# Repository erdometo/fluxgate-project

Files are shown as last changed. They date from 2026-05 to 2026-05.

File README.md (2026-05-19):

# 🧲 High-Precision Fluxgate Magnetic Field Sensor Design

An open-source, high-sensitivity, single-axis Fluxgate magnetometer and development platform designed for aerospace, geophysics, and navigation applications. This project implements a fully integrated system containing hardware (KiCad PCBs), firmware (MSP430 24-bit SD-ADC & RP2040 Controller), simulations (LTSpice), and software (Python PyQt real-time GUI).

Developed as a senior capstone engineering project at **Karadeniz Technical University (KTU)** by **Erdem Metin** and **Mücahit Ata**, under the supervision of **Prof. Dr. İsmail Kaya**.

---

## 📸 System Overview

The Fluxgate sensor system is designed around a dual-MCU architecture consisting of an **RP2040** (master controller and driver) and an **MSP430AFE253** (24-bit Sigma-Delta ADC data acquisition).

System Schematic
*Fig 1: Full system schematic diagram detailing all MCU pinouts, power distribution, and analog filters.*

<p align="center">
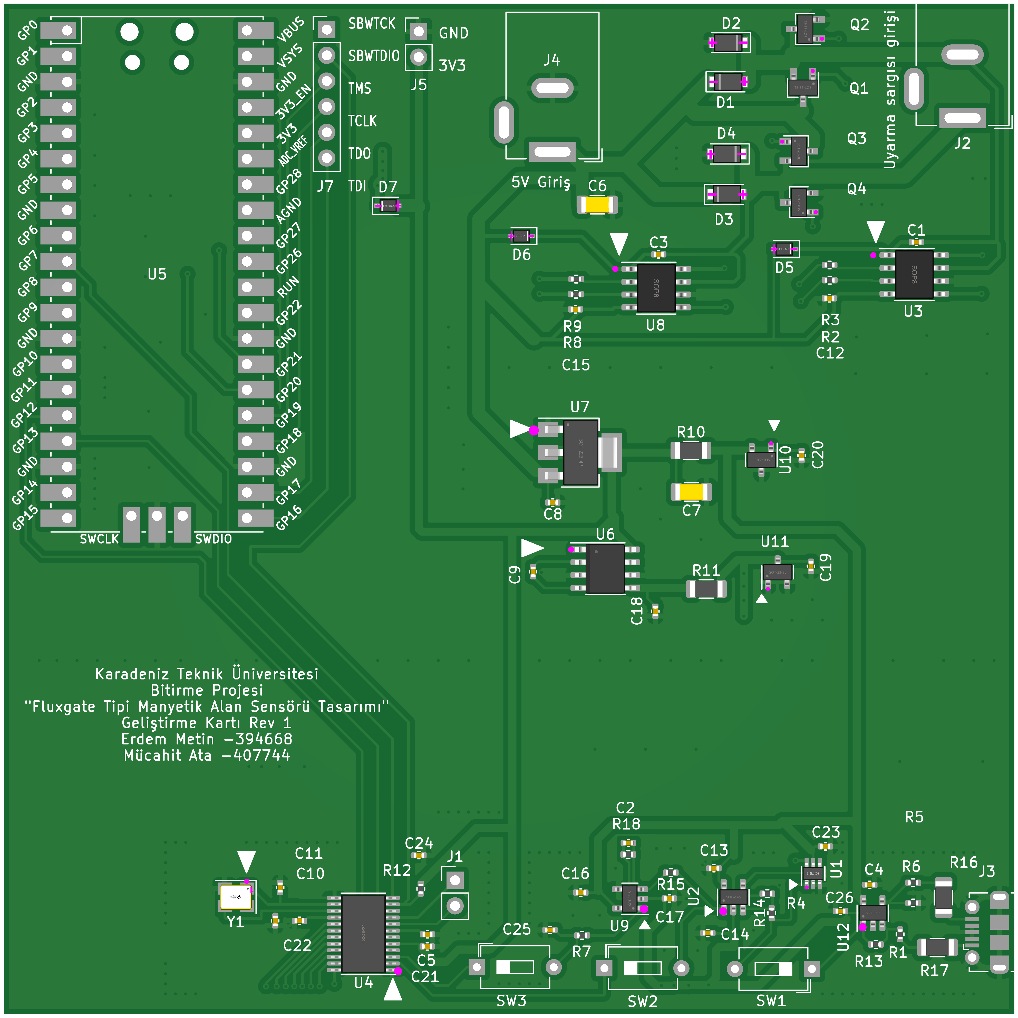
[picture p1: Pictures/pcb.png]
PCB Design Render
  
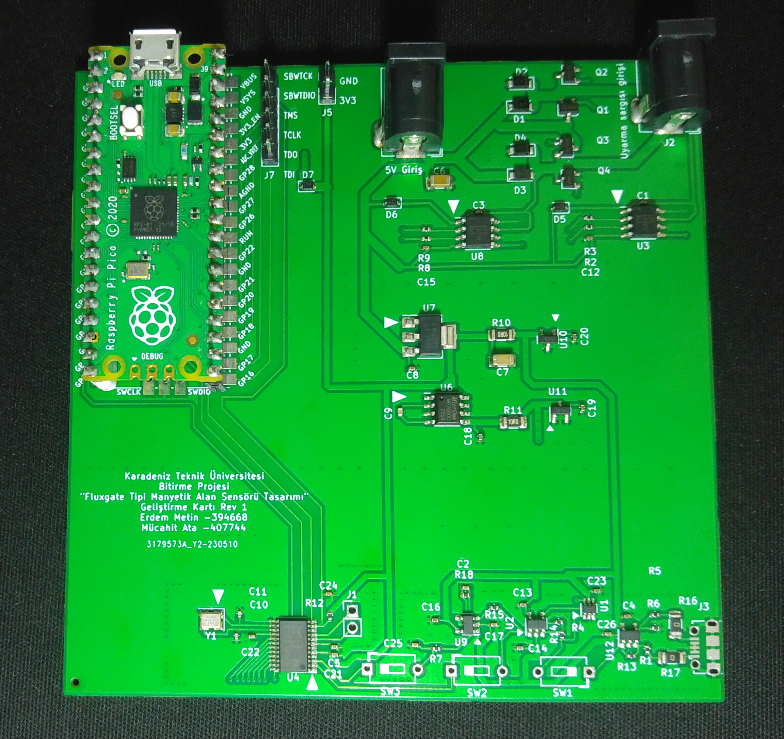
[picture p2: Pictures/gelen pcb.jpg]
Assembled Hardware Prototype
  
</p>
*Fig 2: KiCad PCB 3D layout render (left) and the fully assembled physical testing board (right).*

```mermaid
graph TD
    PC[Computer PyQt GUI / Matlab] <-->|USB virtual COM / UDP Wifi| Pico[Raspberry Pi Pico RP2040]
    Pico -->|PWM Excitation Control f| FET[H-Bridge MOSFET Driver]
    FET -->|AC Excitation staircase Wave| Core[Magnetic Core & Coils]
    Core -->|Induced Sensing Signal| Demod[Analog Processing Circuit]
    Demod -->|DC Level / AC Signal| MSP[MSP430AFE253 24-bit ADC]
    MSP -->|1.5 MBaud UART| Pico
```

---

## 📖 Theory of Operation

A **Fluxgate Magnetometer** measures weak static or low-frequency magnetic fields (in the nT to µT range) by exploiting the non-linear magnetic saturation characteristics of a ferromagnetic core.

1. **Excitation (Drive):** An AC current at frequency $f$ drives the core deep into saturation in both positive and negative directions.
2. **Symmetric Core State:** In the absence of an external magnetic field, the magnetic flux changes symmetrically. The voltage induced in the sensing (pick-up) coil contains only **odd harmonics** ($3f$, $5f$, etc.).
3. **Asymmetric Core State (External Field Present):** When an external magnetic field (like the Earth's field $H_{ext}$) is present, it biases the core, causing it to saturate earlier in one direction and later in the other.
4. **Second Harmonic (2f) Detection:** This asymmetry generates **even harmonics** (predominantly the $2f$ component) in the sensing coil. The amplitude of this second harmonic is directly proportional to the magnitude of the external magnetic field, and its phase indicates the field's direction.

---

## 🛠️ Project Structure

The repository is structured into logically separated folders to make implementation and replication straightforward:

*   📁 **[`Hardware/`](file:///c:/Users/ASUS/Desktop/Fluxgate/Fluxgate-Project-Files/Hardware)**: KiCad schematic and PCB layout designs, Gerber files, and Bill of Materials (BOM).
*   📁 **[`Firmware/`](file:///c:/Users/ASUS/Desktop/Fluxgate/Fluxgate-Project-Files/Firmware)**:
    *   **MSP430:** IAR and CCS projects for 24-bit Sigma-Delta ADC sampling at 16.5 kSps and 1.5 MBaud USART transmission.
    *   **RP2040 (Raspberry Pi Pico):** C/C++ SDK projects generating precise excitation PWM and streaming data to PC via USB Serial or UDP Wi-Fi.
*   📁 **[`Software/`](file:///c:/Users/ASUS/Desktop/Fluxgate/Fluxgate-Project-Files/Software)**: Python-based GUI utilizing `pyqtgraph` for real-time serial and UDP plotting, and Matlab analytics.
*   📁 **[`Simulations/`](file:///c:/Users/ASUS/Desktop/Fluxgate/Fluxgate-Project-Files/Simulations)**: LTSpice circuits simulating the H-Bridge excitation driver and the analog synchronous demodulation path.

---

## 🚀 Step-by-Step Build & Replication Guide

To replicate and build this high-precision Fluxgate sensor, follow these five steps:

### 1. Hardware Fabrication & Assembly
1. Go to **[`Hardware/`](file:///c:/Users/ASUS/Desktop/Fluxgate/Fluxgate-Project-Files/Hardware)** and select either the **Excitation Circuit V1**, the **Excitation Circuit Final**, or the **JLCPCB Version** which is optimized for SMT assembly.
2. Export Gerbers or use the provided `.zip` files under the directories to order PCBs from your manufacturer (e.g., JLCPCB).
3. Assemble the PCB using the BOM. Key components include:
    *   **Primary Controller:** Raspberry Pi Pico (RP2040)
    *   **Precision ADC:** MSP430AFE253IPW (24-bit Sigma-Delta ADC)
    *   **H-Bridge Driver:** HIP4082xB half-bridge gate driver
    *   **Excitation MOSFETs:** AP2300 or IRFZ44N
    *   **Ultra Low-Noise Opamps:** TP2311 or LT149x series (12nV/√Hz input noise)
    *   **Voltage References:** AN431 shunt regulators (2.5V, 20ppm/°C stability)

### 2. Fluxgate Core & Coil Preparation
1. **Core Selection:** Use a high-permeability **green iron-powder ferrite toroid core** with an **inner diameter of 7 mm, thickness of 2 mm, and height of 4.5 mm**. (While a 6-81 Permalloy racetrack core with $100\text{ µm}$ laminations provides lower noise, a toroidal ferrite core is robust and hand-windable).
2. **Drive Winding:** Wind the excitation (drive) coil uniformly around the toroid using **32 AWG** enameled copper wire. In the experimental prototype, the completed drive winding exhibited a measured **series resistance of $17.945\text{ }\Omega$** and a **series inductance of $19.686\text{ mH}$**.
3. **Sense Winding:** Wind the sensing (pick-up) coil on top of the drive winding, orienting the windings to capture the fluxgate effect while canceling direct coupling from the excitation drive.

Wound Fluxgate Core on Prototyping Board
*Fig 3: The custom hand-wound toroidal fluxgate core integrated onto the testing board.*

### 3. Simulation & Validation
1. Open **[`Simulations/LTSpice/`](file:///c:/Users/ASUS/Desktop/Fluxgate/Fluxgate-Project-Files/Simulations)**.
2. Run `fluxgate.asc` to simulate the H-Bridge excitation path. Verify the staircase voltage waveform across the drive bobbin.
3. Run `fluxgateACAnaliz.asc` or `Draft7.asc` to analyze the frequency response of the active integrator and synchronous demodulator. Ensure the integration region lies between **159 Hz and 1591 Hz** and the low-pass filter kesim frekansı is configured near **28 Hz**.

### 4. Firmware Deployment
1. **MSP430 Firmware:**
    *   Open IAR Embedded Workbench or Code Composer Studio.
    *   Load the project in **[`Firmware/MSP430_AFE_ADC/`](file:///c:/Users/ASUS/Desktop/Fluxgate/Fluxgate-Project-Files/Firmware/MSP430_AFE_ADC)** or **[`Firmware/MSP430_ADC_to_UART/`](file:///c:/Users/ASUS/Desktop/Fluxgate/Fluxgate-Project-Files/Firmware/MSP430_ADC_to_UART)**.
    *   Compile and flash the firmware using an eZ-FET debugger (or the Spy-Bi-Wire pins on an MSP430 Launchpad).
    *   *Function:* Configures the 12MHz MCLK, initializes the SD24 Module in group conversion mode, and streams 24-bit raw ADC readings via USART0 at **1.5M Baud**.
2. **RP2040 Firmware:**
    *   Navigate to **[`Firmware/Pico_Firmwares/`](file:///c:/Users/ASUS/Desktop/Fluxgate/Fluxgate-Project-Files/Firmware/Pico_Firmwares)**.
    *   Choose either `pico-custom-firmware-usb` (USB Virtual Serial) or `pico-custom-firmware-udp` (Wi-Fi streaming).
    *   Build the project using the Pico SDK (`CMake`) and flash the resulting `.uf2` file onto your Pi Pico.
    *   *Function:* Emits precise complementary PWM drive signals (80µs duty, 40µs dead-time) at frequency $f$ to drive the H-Bridge. It uses a **PIO state machine** to reliably capture the 1.5MBaud UART stream from the MSP430 and forwards it to the PC.

### 5. GUI & Visualization
1. Install Python 3 and requirements:
   ```bash
   pip install pyqtgraph PyQt5 pyserial numpy
   ```
2. Run the visualization app in **[`Software/Python_GUI_Demo/`](file:///c:/Users/ASUS/Desktop/Fluxgate/Fluxgate-Project-Files/Software/Python_GUI_Demo)**:
   ```bash
   python compass.py
   # or
   python pyqtgraph_float_v2x2_yesim.py
   ```
3. Connect your Pi Pico to the PC via USB. You will see a real-time rolling graph of the 24-bit sampled magnetic field data representing the external field.

---

## 📡 Digital Signal Processing (DSP) & Digital Lock-In Mode

During the final experimental testing phase of this project, the analog op-amps in the physical synchronous demodulation circuit were found to be defective or counterfeit, preventing analog phase detection from working out of the box. To solve this, the project utilized a highly robust **Digital Signal Processing (DSP)** pipeline to bypass the analog demodulator entirely.

### Bypassing the Analog Demodulator
1. The analog SPDT switch (SN74LVC1G3157) was disabled (tied to a static ground state via the MCU).
2. The active low-noise op-amps were configured as a simple differential preamplifier.
3. The raw, high-speed AC signal (which contains the even and odd harmonics) was fed directly into the **MSP430's 24-bit Sigma-Delta ADC**.
4. The raw, un-demodulated samples were digitized at ~16.5 kSps and streamed to the PC via the RP2040 UART/USB bridge.

### Two Host-Side Digital Processing Implementations
Your software repository implements two distinct mathematical approaches on the host PC to extract the external magnetic field from this raw stream:

1. **Frequency-Domain Demodulation (Real-Time FFT):**
   * *File:* **[`pyqtgraph_float_v2x2_yesim.py`](file:///c:/Users/ASUS/Desktop/Fluxgate/Fluxgate-Project-Files/Software/Python_GUI_Demo/pyqtgraph_float_v2x2_yesim.py)**
   * *Method:* Computes a high-performance **Fast Fourier Transform (FFT)** on blocks of 8192 raw samples using Scipy:
     ```python
     Yf0 = fft(ch0)
     ```
   * *Result:* The GUI displays the real-time frequency spectrum. By measuring the amplitude peak of the **second harmonic ($2f$ at 25 kHz)** in the frequency domain, the software calculates the precise external magnetic field intensity, completely replacing the physical analog lock-in filters!

2. **Time-Domain Smoothing (Moving Average Convolution):**
   * *Files:* **[`udp_plot_pyqt.py`](file:///c:/Users/ASUS/Desktop/Fluxgate/Fluxgate-Project-Files/Software/Python_GUI_Demo/udp_plot_pyqt.py)** and **[`udp_plot_pyqt_2.py`](file:///c:/Users/ASUS/Desktop/Fluxgate/Fluxgate-Project-Files/Software/Python_GUI_Demo/udp_plot_pyqt_2.py)**
   * *Method:* Unpacks the high-speed telemetry and applies a real-time **Moving Average Filter** using NumPy convolution across a 1000-sample window:
     ```python
     filtered_data = np.convolve(data, weights, mode='valid')
     ```
   * *Result:* Smooths out the excitation switching ripples and transient spikes, feeding a clean time-domain signal to the graphical compass needle interface to dynamically show the core's magnetic orientation.

---

## 🛠️ Hardware Debugging & Engineering Solutions

During the assembly and testing phase, two critical engineering challenges arose and were systematically resolved:

### 1. The H-Bridge Bootstrap Capacitor & Duty Cycle Adaptation
*   **The Issue:** High-side gate drivers require a bootstrap capacitor ($C_{Bst}$) to maintain the gate-to-source voltage ($V_{GS}$) when the high-side MOSFET turns on. By design guidelines, the minimum bootstrap capacitance is:
    $$C_{Bst} = \frac{Q_{gate}}{\Delta V_{Bst}}$$
    Using the AP2300 gate charge $Q_{gate} = 11\text{ nC}$ and an acceptable voltage ripple $\Delta V_{Bst} = 0.1\text{ V}$, the minimum capacitor required is $110\text{ nF}$. Due to a design oversight, a **$1\text{ nF}$** capacitor was initially populated. This capacitor discharged instantly, causing the high-side gate drivers to drop out immediately.
*   **The Fix:** Populating a **$1\text{ µF}$** capacitor resolved the gate-dropout issue. However, experimental tests under a $330\text{ }\Omega$ load revealed that the high-side gate could remain continuously open for a maximum of **$1.125\text{ ms}$** before the bootstrap charge depleted.
*   **PWM Adaptation:** To prevent the high-side gate from collapsing during lower frequencies, the RP2040 firmware was adapted to emit a highly optimized PWM excitation pattern. Instead of a basic symmetrical square wave, the drive cycle was structured as:
    *   **$0.8\text{ ms}$ Positive Drive Phase** (containing high-speed $80\text{ µs}$ pulses with $40\text{ µs}$ dead-times).
    *   **$0.4\text{ ms}$ Neutral Phase** (H-bridge disabled, allowing the bootstrap capacitors to fully recharge).
    *   **$0.8\text{ ms}$ Negative Drive Phase** (H-bridge reversed).

### 2. Defective Analog Op-Amps & DSP Bypass
*   **The Issue:** During board validation, short-circuiting the sensing coil to ground resulted in the low-noise differential preamplifier and active integrator output locks stuck at a solid **$2.5\text{ V}$** (the virtual ground analog reference voltage). The op-amps (TP2311 or LT1492) failed to respond to any AC or DC input signal changes, leading to the conclusion that the physical components received were defective or counterfeit.
*   **The Solution:** The analog synchronous SPDT demodulator switch (SN74LVC1G3157) was set to ground mode via the RP2040, transforming the first stage into a simple, highly linear $1:2$ differential preamplifier (total differential gain of 20). The raw, high-speed AC pick-up signal was routed directly into the MSP430's 24-bit Sigma-Delta ADC, and the entire lock-in and filtering cascade was bypassed in hardware and reconstructed in real-time software on the host PC.

---

## ⚡ Specifications

| Parameter | Value | Description |
| :--- | :--- | :--- |
| **Sensor Type** | Parallel Fluxgate | Single Axis Magnetometer |
| **Excitation Waveform** | AC Staircase Wave | Minimizes transient EMF spikes |
| **Excitation Frequency** | 12.5 kHz | Configurable via Pico PWM registers |
| **ADC Resolution** | 24-Bit | Sigma-Delta Converter (MSP430AFE253) |
| **Sampling Rate** | ~16,500 samples/sec | High-speed oversampled stream |
| **Baud Rate** | 1,500,000 Baud | High-speed MSP430 to RP2040 UART link |
| **Demodulator Gain** | 1:10 (or 20 Differential) | Synchronous analog SPDT demodulation |
| **Low-Pass Filter (LPF)** | $f_c = 28.42\text{ Hz}$ | Eliminates grid noise (50Hz) and ripples |
| **Integrator Bandwidth** | 159 Hz to 1591 Hz | Limits noise and captures second harmonics |

---

## ⚖️ License

This project is open-source and released under the [MIT License](file:///c:/Users/ASUS/Desktop/Fluxgate/Fluxgate-Project-Files/LICENSE). Feel free to use, modify, and distribute for personal, academic, or commercial purposes.

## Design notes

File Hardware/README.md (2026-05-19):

# 🔌 Hardware & PCB Design

This folder contains the KiCad schematics and PCB layout files for the Fluxgate Sensor Development and Testing Board. The hardware combines the master controller, excitation power electronics, high-speed 24-bit ADC, and a low-noise analog signal processing path into a single 150mm x 100mm PCB.

Full Circuit Schematic
*Fig 1: Complete circuit schematic for the Fluxgate Development Board (open-source).*

<p align="center">
  KiCad 3D Layout
  Manufactured PCB Board
</p>
*Fig 2: KiCad board layout 3D render (left) and the actual manufactured PCB received from JLCPCB (right).*

---

## 📁 Directory Directory

*   📁 **[`Excitation_Circuit_V1/`](file:///c:/Users/ASUS/Desktop/Fluxgate/Fluxgate-Project-Files/Hardware/Excitation_Circuit_V1)**: The initial KiCad prototype.
*   📁 **[`Excitation_Circuit_Final/`](file:///c:/Users/ASUS/Desktop/Fluxgate/Fluxgate-Project-Files/Hardware/Excitation_Circuit_Final)**: The revised KiCad project with improvements in the bootstrap driver and ground isolation.
*   📁 **[`KiCad_Development_Board_JLCPCB/`](file:///c:/Users/ASUS/Desktop/Fluxgate/Fluxgate-Project-Files/Hardware/KiCad_Development_Board_JLCPCB)**: Design optimized for JLCPCB's automated surface mount technology (SMT) assembly service. Contains BOM and component positioning files.

---

## ⚡ Hardware Architecture & Circuit Sub-systems

The Fluxgate Development Board contains four main hardware sub-systems:

### 1. Power Management & Low-Noise Rails
Since magnetic sensors are highly sensitive to power supply noise, a robust voltage regulation and reference system is implemented:
*   **Main Regulator:** AMS1117-3.3 produces the digital 3.3V supply.
*   **Negative Rail Generator:** ME7660C charge-pump voltage converter generates a low-noise $-3.3\text{ V}$ rail from the $3.3\text{ V}$ input.
*   **Precision Analog References:** Originally, the op-amps shared the noisy 3.3V digital rail with the microcontrollers, which coupled massive MCU switching ripples into the analog signal path. To achieve extremely low-noise operation, the board was modified to use two **AN431 precision shunt regulators** with a **20 PPM/°C temperature coefficient**. These regulators derive highly stable $+2.5\text{ V}$ and $-2.5\text{ V}$ virtual ground references from the noisy $3.3\text{ V}$ rail, isolated via $10\text{ }\Omega$ current-limiting resistors to prevent temperature-induced offset drifts.

```
       [ 5V USB Input ]
              │
      ┌───────┴───────┐
      ▼               ▼
[AMS1117-3.3V]   [ME7660C]
      │               │
  [ +3.3V ]       [ -3.3V ]
      │               │
  [ AN431 ]       [ AN431 ]
      │               │
  [ +2.5V ]       [ -2.5V ]
```

### 2. Excitation Drive (H-Bridge)
To saturate the ferromagnetic core in both directions:
*   **Drivers:** Two half-bridge drivers (LP1111) are configured to form a full H-bridge.
*   **Switching Elements:** Low $R_{DS(on)}$ AP2300 or IRFZ44N N-channel MOSFETs.
*   **Protection:** 1N5400 flyback diodes protect the MOSFETs against massive back-EMF spikes (up to 200A instantaneous rating) when the coil current reverses.
*   **Bootstrap Optimization:** High-side gate drivers require a bootstrap capacitor ($C_{Bst}$) to maintain the gate-to-source voltage ($V_{GS}$) when the high-side MOSFET is active. The minimum bootstrap capacitance is calculated using:
    $$C_{Bst} = \frac{Q_{gate}}{\Delta V_{Bst}}$$
    Using the AP2300 gate charge $Q_{gate} = 11\text{ nC}$ and an acceptable voltage ripple $\Delta V_{Bst} = 0.1\text{ V}$, the minimum capacitor required is $110\text{ nF}$.
    *   Due to a design oversight, a **$1\text{ nF}$** capacitor was initially populated, causing the high-side MOSFETs to fail to switch completely.
    *   Replacing this with a **$94\text{ nF}$** capacitor allowed switching but triggered rapid charge depletion, causing the gates to turn on and off hundreds of times during a 5ms cycle.
    *   Restoring this to **$1\text{ µF}$** in the final hardware stabilized the gate, allowing stable gate-on periods up to **$1.125\text{ ms}$** under a $330\text{ }\Omega$ load.

### 3. Low-Noise Analog Signal Processing
The induced voltage from the pickup (sensing) coil undergoes analog preprocessing to extract the second harmonic component ($2f$):
*   **Differential Input Preamp:** Winding coupling experiences massive Common-Mode coupling from the high-voltage excitation drive. To solve this, the sensing coil is connected to a **differential preamplifier with a 1:2 gain** using low-noise TP2311 or LT1492 op-amps. This rejects common-mode excitation noise while increasing the differential sensing signal, bringing the total channel gain to 20.
*   **Synchronous Demodulator:** An SN74LVC1G3157 analog SPDT switch acts as a phase-sensitive rectifier. It is toggled by the RP2040 at twice the excitation frequency ($2f$), demodulating the second harmonic directly to DC.
*   **Active Integrator:** A low-pass integrator with an integration bandwidth configured between **159 Hz and 1591 Hz** ($\text{BW} = 1/(2\pi R_f C)$ with $R_f = 100\text{ k}\Omega, C = 10\text{ nF}$).
*   **Output Filter:** An RC low-pass filter with a cutoff frequency $f_c = 28.42\text{ Hz}$ ($C = 100\text{ nF}, R = 56\text{ k}\Omega$) filters out the $50\text{ Hz}$ mains grid noise and lingering switching ripples.

### 4. Precision Digitization & Processing
*   **MSP430AFE253:** Reads the filtered DC level (or the pre-demodulated high-speed AC signal) using its internal **24-bit Sigma-Delta ADC**. It runs on a $12\text{ MHz}$ internal DCO and transmits over UART at **1.5M Baud**.
*   **RP2040 (Raspberry Pi Pico):** Controls H-Bridge timing and routes the MSP430's digitized telemetry to a computer via USB virtual serial or a UDP socket over Wi-Fi.

---

## 📋 Component Checklist (BOM)

If assembling the board manually, ensure the following core components are ready:

| Designator | Component Name | Package | Description |
| :--- | :--- | :--- | :--- |
| **U5** | Raspberry Pi Pico | Module | Master controller and PWM driver |
| **U4** | MSP430AFE253IPW | TSSOP-24 | 24-Bit Sigma-Delta ADC / High-Speed DSP |
| **U1, U2** | LP1111 (or HIP4082) | SOIC-8 | Half-Bridge Bootstrap MOSFET Gate Drivers |
| **Q1 - Q4** | AP2300 (or IRFZ44N) | SOT-23 / TO-220 | Excitation H-Bridge Switching MOSFETs |
| **U3, U8, U9** | TP2311 (or LT1492) | SOIC-8 | $12\text{ nV}/\sqrt{\text{Hz}}$ Low-Noise Precision Op-Amps |
| **U12** | SN74LVC1G3157 | SOT-363 | High-Speed SPDT Analog Switch (Demodulator) |
| **U10, U11** | AN431 | SOT-23 | High-Precision Shunt Voltage Regulator (2.5V) |
| **U6** | ME7660C | SOIC-8 | Switched-Capacitor Negative Voltage Converter |
| **U7** | AMS1117-3.3 | SOT-223 | $3.3\text{ V}$ Low-Dropout Linear Regulator |
| **D1 - D4** | 1N5400 (or 1N4148) | DO-201AD | 200A Flyback Back-EMF Protection Diodes |

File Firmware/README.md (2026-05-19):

# 💾 Firmware Guide

This folder contains the source code, project workspace configurations, and build directories for the dual-MCU system powering the Fluxgate magnetometer: the **Texas Instruments MSP430AFE253** and the **Raspberry Pi Pico (RP2040)**.

---

## 📁 Directory Structure

*   📁 **[`MSP430_ADC_to_UART/`](file:///c:/Users/ASUS/Desktop/Fluxgate/Fluxgate-Project-Files/Firmware/MSP430_ADC_to_UART)**: IAR project that configures the SD24 ADC module and transmits data via UART.
*   📁 **[`MSP430_AFE_ADC/`](file:///c:/Users/ASUS/Desktop/Fluxgate/Fluxgate-Project-Files/Firmware/MSP430_AFE_ADC)**: Standard MSP430 C firmware implementing oversampled 24-bit analog data acquisition.
*   📁 **[`MSP430_AFE_Test/`](file:///c:/Users/ASUS/Desktop/Fluxgate/Fluxgate-Project-Files/Firmware/MSP430_AFE_Test)**: Verification routines for validating the MCU clock and peripheral subsystems.
*   📁 **[`MSP430_SigmaDelta_Demo/`](file:///c:/Users/ASUS/Desktop/Fluxgate/Fluxgate-Project-Files/Firmware/MSP430_SigmaDelta_Demo)**: Code Composer Studio (CCS) project template for the Sigma-Delta ADC.
*   📁 **[`MSP430_UART_Demo/`](file:///c:/Users/ASUS/Desktop/Fluxgate/Fluxgate-Project-Files/Firmware/MSP430_UART_Demo)**: Isolated USART test code used to push the baud-rate boundaries.
*   📁 **[`Pico_Firmwares/`](file:///c:/Users/ASUS/Desktop/Fluxgate/Fluxgate-Project-Files/Firmware/Pico_Firmwares)**:
    *   **`pico-custom-firmware-usb`**: C/C++ SDK project routing data via high-speed USB CDC.
    *   **`pico-custom-firmware-udp`**: C/C++ SDK project streaming data over Wi-Fi UDP.

---

## 🧠 MSP430AFE253 Firmware Architecture

The MSP430's primary role is high-speed, high-resolution data acquisition using its integrated **SD24_A 24-bit Sigma-Delta ADC**.

```
    [Analog Input]
          │
          ▼
   [SD24 Channel 0/1] ──► [SD24_ISR (Interrupt)]
                                │ (Read 24-bit Conversion)
                                ▼
                       [USART0 TX Buffer] ──► [1.5 MBaud TX Pin]
```

### Key Configurations
1.  **Watchdog Timer:** Proactively disabled at power-on (`WDTCTL = WDTPW + WDTHOLD`) to prevent unexpected resets during clock configuration.
2.  **Clock System Calibration:**
    *   By default, the MSP430 runs on an internal Digitally Controlled Oscillator (DCO) at $1\text{ MHz}$.
    *   To support high-speed UART transmission without frame errors, the firmware calibrates the DCO to **$12\text{ MHz}$** using factory-stored calibration constants:
        ```c
        BCSCTL1 = CALBC1_12MHZ;
        DCOCTL = CALDCO_12MHZ;
        ```
3.  **High-Speed USART0 Setup:**
    *   Configured in asynchronous UART mode.
    *   Baud rate set to **1,500,000 Baud** (1.5M Baud) using the $12\text{ MHz}$ sub-main clock (SMCLK) as the clock source. This extreme baud rate is required to stream two channels of oversampled 24-bit data in real-time.
4.  **SD24_A Sigma-Delta ADC Register-Level Setup:**
    *   **Voltage Reference:** Set to use the internal precision $1.2\text{ V}$ bandgap reference.
    *   **Channel Grouping (`SD24GRP`):** Configures Channel 0 (Ch0) and Channel 1 (Ch1) in Group Conversion Mode, ensuring that conversions are initiated simultaneously across both analog channels to prevent phase lag during dual-axis or differential sensing.
    *   **LSB Formatting (`SD24LSBACC`):** Set to format the output alignment, allowing the firmware to extract the lower bits directly from the conversion registers.
    *   **Register Mapping:**
        *   `SD24CTL`: Configures the ADC clock source as SMCLK ($12\text{ MHz}$).
        *   `SD24INCTLx`: Controls input channel routing (Ch0/Ch1).
        *   `SD24GAINx`: Selects analog pre-amplifier gain settings.
        *   `SD24CCTLx`: Sets conversion options (Oversampling Ratio, interrupts).
        *   `SD24MEMx`: Stores raw ADC results.
    *   *Operation:* Inside the high-priority interrupt routine (`SD24_ISR`), the conversion memory registers (`SD24MEMx`) are read, formatted, split into bytes, and immediately written to the USART0 TX buffer to keep the stream gapless.

---

## 🎛️ RP2040 (Raspberry Pi Pico) Firmware Architecture

The RP2040 serves as the master coordinator. It handles two critical tasks:
1.  Generating ultra-stable, complementary PWM drive signals for the excitation circuit.
2.  Capturing the 1.5MBaud UART stream from the MSP430 and forwarding it to the PC.

### 1. Excitation PWM Synthesis
The RP2040 uses its hardware PWM slice to generate two out-of-phase drive signals (`in1` and `in2`) and a global `enable` gate. To prevent high-side gate charge depletion on the LP1111 half-bridge drivers, the excitation waveform requires a specific duty pattern. Instead of a basic symmetrical square wave, the RP2040 generates a triple-phase excitation sequence:
*   **Positive Phase ($0.8\text{ ms}$):** Emits high-speed active pulses of $80\text{ µs}$ on `in1` separated by $40\text{ µs}$ dead-times.
*   **Neutral Recharge Phase ($0.4\text{ ms}$):** The H-bridge is completely disabled (`enable` low). This gives the high-side bootstrap capacitors a dedicated window to fully recharge from the $+5\text{ V}$ supply.
*   **Negative Phase ($0.8\text{ ms}$):** Emits active $80\text{ µs}$ pulses on `in2` separated by $40\text{ µs}$ dead-times.

This triple-phase architecture ($0.8\text{ ms} / 0.4\text{ ms} / 0.8\text{ ms}$) guarantees that the high-side bootstrap gates never collapse, keeping the excitation stage perfectly stable.

### 2. High-Speed Telemetry Ingestion (PIO)
Standard microcontroller hardware UART engines can struggle to ingest continuous, gapless data streams at 1.5M Baud without dropping bits or starving the CPU.
*   The RP2040 solves this by using its integrated **Programmable I/O (PIO) blocks**.
*   A custom PIO state machine is loaded to act as a high-speed, hardware-level UART RX receiver on **GPIO10** (connected to MSP430's TXD pin).
*   The PIO automatically samples the incoming bitstream, decodes the serial frames, and writes the assembled bytes directly into a hardware FIFO.

### 3. PC Data Forwarding Paths
*   **USB Virtual Serial Mode (`pico-custom-firmware-usb`):**
    The firmware initializes a USB CDC (virtual serial port) interface using the **TinyUSB** stack. Bytes read from the PIO FIFO are pushed directly into the USB buffer, which appears on the PC as a Virtual COM port.
*   **Wi-Fi UDP Mode (`pico-custom-firmware-udp`):**
    If using a Raspberry Pi Pico W, the firmware initializes the CYW43439 Wi-Fi chip, connects to the local wireless network, and bundles the incoming ADC byte stream into **UDP Packets**. These packets are streamed wirelessly over the network to the PC's IP address, eliminating all physical connections to the sensor during measurement (greatly reducing electromagnetic interference).

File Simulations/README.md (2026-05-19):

# ⚡ LTSpice Simulations

This directory contains the LTSpice simulation files used to model, analyze, and optimize both the power excitation stage and the analog signal conditioning path prior to committing to PCB manufacturing.

---

## 📁 Key Simulation Files

*   📉 **[`fluxgate.asc`](file:///c:/Users/ASUS/Desktop/Fluxgate/Fluxgate-Project-Files/Simulations/LTSpice/fluxgate.asc)**: Main system model containing the MOSFET H-bridge driver, flyback diodes, and dual-coil mutual inductance model.
*   📉 **[`fluxgateACAnaliz.asc`](file:///c:/Users/ASUS/Desktop/Fluxgate/Fluxgate-Project-Files/Simulations/LTSpice/fluxgateACAnaliz.asc)**: AC frequency response analysis of the active integration filter and low-pass output stage.
*   📉 **[`driver.asc`](file:///c:/Users/ASUS/Desktop/Fluxgate/Fluxgate-Project-Files/Simulations/LTSpice/driver.asc)**: Isolated gate-driver simulation modeling half-bridge switching dynamics and bootstrap capacitor charging cycles.
*   📉 **[`Draft1.asc` to `Draft7.asc`](file:///c:/Users/ASUS/Desktop/Fluxgate/Fluxgate-Project-Files/Simulations/LTSpice)**: Incremental design drafts representing the evolution of the synchronous phase detector, low-pass filter coefficients, and feedback networks.

---

## 🎛️ Circuit Modeling & Analysis

LTSpice was used to simulate two primary engineering domains: the **Power Excitation Circuit** and the **Demodulator/Filter Conditioning Path**.

### 1. Excitation Circuit Simulation (`fluxgate.asc`, `driver.asc`)
*   **Purpose:** To verify that the H-bridge generates a clean AC staircase voltage across the drive bobbin without inducing excessive overshoot, rings, or cross-conduction.
*   **Gate Driver Substitution Limitation:** 
    Because a SPICE model for the specific **Harris/Intersil/Renesas HIP4082** full-bridge gate driver was unavailable in standard LTSpice libraries, the simulation was modeled using **two LT1162 half-bridge gate drivers** connected in a complementary configuration to form a complete full H-bridge excitation stage.
*   **H-Bridge Load Impedance Modeling:** 
    The H-bridge utilizes four N-channel MOSFETs (IRFZ44N/AP2300 series) driven by complementary gate pulses with a $40\text{ µs}$ dead-time. The load is modeled as a primary excitation inductor in series with its winding resistance:
    $$Z_{\text{load}}(s) = sL_1 + R_1$$
    where the primary excitation coil parameters are defined as $L_1 = 1.3\text{ mH}$ and series winding resistance $R_1 = 3\text{ }\Omega$.
*   **Back-EMF Suppression:** 
    The circuit model includes high-current 1N5400 flyback power diodes. Transient simulation (`.tran 0 0.01 0`) verifies that when the H-Bridge switches off, the inductor's magnetic energy discharges safely through the flyback path into the supply rails, clamping the maximum voltage stress to safe levels.
*   **Bootstrap Capacitor Dynamics:** 
    The gate-source bootstrap charging process is simulated. A bootstrap capacitor $C_{Bst}$ must supply the gate charge $Q_{gate}$ without dropping below a tolerable gate voltage dip $\Delta V_{Bst}$:
    $$C_{Bst} = \frac{Q_{gate}}{\Delta V_{Bst}}$$
    For $Q_{gate} = 11\text{ nC}$ (AP2300/IRFZ44N class) and $\Delta V_{Bst} = 0.1\text{ V}$, the absolute minimum capacitance is $110\text{ nF}$. The initial physical footprint error populated a $1\text{ nF}$ capacitor, which resulted in complete gate-source voltage collapse within microseconds in simulation. Populating a $1\text{ µF}$ capacitor stabilized the high-side gate-drive voltage, keeping the channel open for a maximum of $1.125\text{ ms}$ under load.

```
       +5V Supply
         │
    ┌────┴────┐
   [Q1]      [Q3]
    │──(L1)───│  <-- Winding Inductor (1.3mH, 3Ω)
   [Q2]      [Q4]
    └────┬────┘
         ▼ Ground
```

### 2. Analog Phase-Sensitive Demodulation (`fluxgateACAnaliz.asc`, `Draft7.asc`)
*   **Purpose:** To verify the rectification of the second harmonic ($2f$) signal and the removal of switching spikes.
*   **Demodulator Switching Model:** Implements a voltage-controlled switch component (`SW`) controlled by a square-wave source operating at twice the excitation frequency ($2f = 25\text{ kHz}$). This represents the SN74LVC1G3157 SPDT analog switch.
*   **Active Integrator Frequency Response:**
    The active integrator (with feedback resistor $R_f = 100\text{ k}\Omega$ and feedback capacitor $C = 10\text{ nF}$) has a parallel RC feedback path. The closed-loop transfer function is given by:
    $$H(s) = -\frac{Z_f(s)}{Z_{in}(s)} = -\frac{R_f}{R_{in} (1 + s R_f C)} = -\frac{R_f / R_{in}}{1 + s R_f C}$$
    *   **Low-Frequency Limit (Pole Frequency):**
        $$f_L = \frac{1}{2\pi R_f C} = \frac{1}{2\pi \cdot 100\text{ k}\Omega \cdot 10\text{ nF}} \approx 159.15\text{ Hz}$$
        Below this frequency ($f < f_L$), the capacitor behaves as an open circuit, and the integrator acts as a standard inverting amplifier with a fixed DC gain of $-R_f / R_{in} = -10$ (for $R_{in} = 10\text{ k}\Omega$).
    *   **High-Frequency Limit (Unity-Gain Frequency):**
        $$f_H = \frac{1}{2\pi R_{in} C} = \frac{1}{2\pi \cdot 10\text{ k}\Omega \cdot 10\text{ nF}} \approx 1591.55\text{ Hz}$$
        Above $f_H$, the gain drops below $0\text{ dB}$, limiting high-frequency noise amplification. The integration region is thus strictly bounded inside the bandpass-like region of $[159.2\text{ Hz}, 1591.5\text{ Hz}]$.
    *   **Transient Time Integration Limit:**
        For perfect integration of transient magnetic pulses without saturation, the integration time window $T$ must span at least five time constants of the feedback loop:
        $$T \ge 5 \tau = 5 R_f C = 5 \cdot 100\text{ k}\Omega \cdot 10\text{ nF} = 5\text{ ms}$$
        This time-domain limit corresponds to a minimum integration frequency of:
        $$f_{\text{min}} = \frac{1}{T} \le 200\text{ Hz}$$
*   **RC Output Low-Pass Filter Transfer Function:**
    The filtered signal is further smoothed using a passive RC low-pass filter:
    $$H_{\text{LPF}}(s) = \frac{1}{1 + s R_2 C_2}$$
    where $R_2 = 56\text{ k}\Omega$ and $C_2 = 100\text{ nF}$.
    *   **Cut-Off Frequency:**
        $$f_c = \frac{1}{2\pi R_2 C_2} = \frac{1}{2\pi \cdot 56\text{ k}\Omega \cdot 100\text{ nF}} \approx 28.42\text{ Hz}$$
    *   **AC Grid Noise Rejection:**
        This low cut-off frequency provides heavy attenuation for frequencies at and above $50\text{ Hz}$ (specifically, $\approx -10\text{ dB}$ at $50\text{ Hz}$ and $\approx -22\text{ dB}$ at $100\text{ Hz}$), which serves as a powerful shield rejecting local $50\text{ Hz}$ AC mains power grid radiation.

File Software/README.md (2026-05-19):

# 💻 Software, GUI & Analytics

This directory contains the Python-based real-time graphical user interfaces (GUIs), data plotting dashboards, and Matlab analytical scripts used to process, log, and visualize the digitized Fluxgate sensor telemetry.

---

## 📁 Key Software Files

*   🐍 **[`compass.py`](file:///c:/Users/ASUS/Desktop/Fluxgate/Fluxgate-Project-Files/Software/Python_GUI_Demo/compass.py)**: Python client that maps the parsed magnetic field intensity to a graphical rotating compass needle (`needle.png` and `dial.png`).
*   🐍 **[`pyqtgraph_float_v2x2_yesim.py`](file:///c:/Users/ASUS/Desktop/Fluxgate/Fluxgate-Project-Files/Software/Python_GUI_Demo/pyqtgraph_float_v2x2_yesim.py)**: Real-time, multi-channel oscilloscope client built using **PyQtGraph** for rendering the high-speed (16.5 kSps) 24-bit ADC data.
*   🐍 **[`udp_plot_pyqt.py`](file:///c:/Users/ASUS/Desktop/Fluxgate/Fluxgate-Project-Files/Software/Python_GUI_Demo/udp_plot_pyqt.py)**: Original Python plotting script for UDP data streams.
*   🐍 **[`udp_plot_pyqt_2.py`](file:///c:/Users/ASUS/Desktop/Fluxgate/Fluxgate-Project-Files/Software/Python_GUI_Demo/udp_plot_pyqt_2.py)**: Networked plotting client designed to bind to a local UDP socket and visualize wireless telemetry streamed over Wi-Fi by the RP2040 (updated version).
*   🐍 **[`fluxgateDB.py`](file:///c:/Users/ASUS/Desktop/Fluxgate/Fluxgate-Project-Files/Software/Python_GUI_Demo/fluxgateDB.py)**: Data logging engine that logs the parsed magnetic readings into a database structure for long-term drift studies.
*   📊 **[`m1.m`, `m2.m`](file:///c:/Users/ASUS/Desktop/Fluxgate/Fluxgate-Project-Files/Software/Python_GUI_Demo)**: Matlab scripts for importing logged datasets, executing Fast Fourier Transforms (FFT), and computing the signal-to-noise ratio (SNR) and harmonic distortion of the sensor.

---

## 🖥️ Graphical Dashboards & APIs

The software stack implements three main processing and filtering pathways to display sensor data:

### 1. Real-Time Fast Fourier Transform (FFT) Analyzer (`pyqtgraph_float_v2x2_yesim.py`)
This script acts as a high-speed, GPU-accelerated **digital spectrum analyzer** used to run in **DSP Mode** (bypassing physical filters).
*   **Performance Engine:** Utilizes **PyQtGraph** for rendering, which delegates processing directly to the GPU via OpenGL/Qt graphics contexts. This allows the GUI to plot 16,500 samples/sec continuously at 60fps without lag or UI freezing.
*   **Spectral Demodulation & FFT Math:** 
    *   Reads and decodes the gapless 1.5MBaud UART stream.
    *   Saves raw AC data points into rolling buffer arrays of size $N = 8192$.
    *   Computes the Discrete Fourier Transform (DFT) via the Fast Fourier Transform (FFT) algorithm on the CPU:
        $$X[k] = \sum_{n=0}^{N-1} x[n] \cdot e^{-j \frac{2\pi}{N} k n}, \quad k = 0, 1, \dots, N-1$$
        where $x[n]$ is the discrete time-domain input sequence, $N = 8192$, and $k$ represents the frequency bin.
    *   The complex magnitude of each frequency bin is calculated as:
        $$|X[k]| = \sqrt{\text{Re}(X[k])^2 + \text{Im}(X[k])^2}$$
    *   Plots the rolling magnitude spectrum on a logarithmic scale (`p2.setLogMode(False, True)`) using the decibel (dB) scale representation:
        $$\text{Magnitude}_{\text{dB}}[k] = 20 \log_{10} \left( |X[k]| + \epsilon \right)$$
        where $\epsilon = 10^{-10}$ is a regularization constant added to prevent singular $\log(0)$ errors.
*   **Digital Lock-In Amplification:**
    *   **Excitation Frequency:** Given the RP2040 triple-phase excitation cycle ($0.8\text{ ms}$ positive + $0.4\text{ ms}$ neutral + $0.8\text{ ms}$ negative = $2.0\text{ ms}$ total period), the fundamental drive frequency is $f_0 = \frac{1}{2\text{ ms}} = 500\text{ Hz}$.
    *   **Demodulation Math:** The fluxgate effect concentrates the external magnetic field intensity in the second harmonic ($2f_0 = 1000\text{ Hz}$ or $1\text{ kHz}$). The digital lock-in process multiplies the digitized sensor output $x[n]$ with orthogonal sine and cosine reference signals at the second harmonic frequency:
        $$I[n] = x[n] \cdot \sin(4\pi f_0 n T_s)$$
        $$Q[n] = x[n] \cdot \cos(4\pi f_0 n T_s)$$
        where $T_s = \frac{1}{f_s}$ is the sampling period (for $f_s \approx 16.5\text{ kSps}$, $T_s \approx 60.6\text{ µs}$).
    *   **Filtering & Vector Extraction:** The in-phase $I[n]$ and quadrature $Q[n]$ products are passed through a digital low-pass filter (moving average or convolution) to extract the static DC terms $I_{\text{filt}}$ and $Q_{\text{filt}}$. The reconstructed magnetic field magnitude $R$ and phase angle $\theta$ are then derived as:
        $$R = \sqrt{I_{\text{filt}}^2 + Q_{\text{filt}}^2}$$
        $$\theta = \arctan2(Q_{\text{filt}}, I_{\text{filt}})$$
        This dual-phase lock-in structure allows the GUI to extract magnetic intensity with massive noise rejection, capturing both magnitude and phase orientation while bypassing all physical analog filter drift and component tolerances.

### 2. Time-Domain Moving Average Smoothing (`udp_plot_pyqt.py` and `udp_plot_pyqt_2.py`)
These scripts are designed for time-domain visualization of both raw and filtered signals.
*   **Signal Reconstruction:** Decodes UDP packets received over Wi-Fi, separating the primary channel and secondary OPAMP channels.
*   **Moving Average Filter Math:** Applies a digital **Moving Average Filter** in real-time using a NumPy convolution window of $M = 1000$ samples:
    $$y[n] = \frac{1}{M}\sum_{k=0}^{M-1} x[n-k]$$
*   **Discrete Time Convolution:** This summation is mathematically equivalent to the linear convolution of the input sequence $x[n]$ with a rectangular impulse response $h[n]$:
    $$y[n] = (x * h)[n] = \sum_{k=-\infty}^{\infty} x[k] \cdot h[n-k]$$
    where the filter's discrete impulse response $h[n]$ is defined by:
    $$h[n] = \begin{cases} \frac{1}{M}, & 0 \le n < M \\ 0, & \text{otherwise} \end{cases}$$
    ```python
    window_size = 1000
    weights = np.ones(window_size) / window_size
    filtered_data = np.convolve(data, weights, mode='valid')
    ```
*   **Frequency Response & Notch Characteristics:** The frequency-domain transfer function $H(e^{j\omega})$ of this moving average filter is a Dirichlet kernel (sinc-like function):
    $$H(e^{j\omega}) = \frac{1}{M} \sum_{n=0}^{M-1} e^{-j\omega n} = e^{-j\omega \frac{M-1}{2}} \cdot \frac{\sin\left(\frac{\omega M}{2}\right)}{M \sin\left(\frac{\omega}{2}\right)}$$
    This transfer function provides deep low-pass filtering and places periodic notches (infinite attenuation) at integer multiples of $f_{\text{notch}} = \frac{f_s}{M}$. For $f_s \approx 16.5\text{ kSps}$ and $M = 1000$, the first notch occurs at exactly $16.5\text{ Hz}$, which effectively filters out high-frequency switching ripples, transient spikes, and electromagnetic noise from the excitation H-bridge, providing a pristine, readable time-domain baseline.

*   **Wireless Ingestion (UDP Sockets):** To isolate the sensor from electromagnetic coupling (EMI) radiating from the host computer's USB ports, the sensor streams data over Wi-Fi. The scripts initialize a UDP receiver socket:
    ```python
    import socket
    sock = socket.socket(socket.AF_INET, socket.SOCK_DGRAM)
    sock.bind(('0.0.0.0', 6001))
    ```
    It listens for incoming packets, extracts the 24-bit binary ADC payloads, and updates the PyQtGraph widget dynamically.

### 3. Graphical Compass UI
*   **Implementation:** `compass.py` integrates a lightweight PyQt interface that loads two image assets: `dial.png` (a 360-degree compass card) and `needle.png` (a red indicator needle).
*   **Function:** By converting the incoming digitized voltage stream into a magnetic field vector (scaled in microteslas, $µT$), the script computes the relative magnetic heading and applies a rotation matrix to `needle.png` in real-time, providing an intuitive, interactive display of the sensor's direction.

---

## 🚀 How to Run the GUIs

### Prerequisites
Install Python 3.8+ and the required packages:
```bash
pip install PyQt5 pyqtgraph numpy pyserial
```

### Running the USB Serial Plotter
1. Ensure the hardware is connected via USB and recognized by your system (check Device Manager on Windows for the active COM port, e.g., `COM3`).
2. Run the PyQtGraph script:
   ```bash
   python pyqtgraph_float_v2x2_yesim.py
   ```

### Running the Wireless UDP Plotter
1. Ensure the Pico W and your computer are connected to the same local network.
2. Update the `LOCAL_IP` in `udp_plot_pyqt_2.py` or `udp_plot_pyqt.py` to match your computer's IP address.
3. Start the UDP server script:
   ```bash
   python udp_plot_pyqt_2.py
   # or
   python udp_plot_pyqt.py
   ```
4. Power on the sensor. The data stream will automatically render on the screen.

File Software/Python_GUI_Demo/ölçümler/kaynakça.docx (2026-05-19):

[1]. İ. Yağlıdere, “Fluxgate Tipi Hassas Magnetik Sensör Tasarımı,” Yüksek Lisans Tezi, İstanbul Teknik Üniversitesi Fen Bilimleri Enstitüsü, Haziran 2010, sf. 1.

[2] U. Topal, Tubitak Proje Özeti, 2013.

[3] C. Hinnrichs, J. Stahl, Kai Kuchen Brandt ve M. Schilling, Dependence of Sensitivity and Noise of Fluxgate Sensors on Race-track Geometry, 2001, pp. 1983-1985.

[4] J. Kubik ve P. Ripka, "Racetrack fluxgate sensor core demagnetization," Sensors and Actuators A: Physical, Volume 143, Issue 2, 2008, Pages 237-244, ISSN 0924-4247, (https://doi.org/10.1016/j.sna.2007.10.066.)

[5] M. Janosek, M. Butta, M. Dressler, E. Saunderson, D. Novotny ve C. Fourie, "1-pT Noise Fluxgate Magnetometer for Geomagnetic Measurements and Unshielded Magnetocardiography," IEEE Transactions on Instrumentation and Measurement, vol. 69, no. 5, pp. 2552-2560, May 2020, doi: 10.1109/TIM.2019.2949205.

[6] E. Özkök, "Düşük manyetik alan algılama için fluxgate sensör geliştirme ve optimizasyonu," Yüksek Lisans Tezi, Yildiz Teknik Üniversitesi Fen Bilimleri Enstitüsü, İstanbul, 2017, sf. 17-18.

[7] E. Özergin, “Elektrodepozisyon Tekniği ile Büyütülen CoFeCu Filmlerin Yapısal, Manyetik ve Manyetodirenç Özelliklerinin incelenmesi,” Yüksek Lisans Tezi, Balikesir Üniversitesi

Fen Bilimleri Enstitüsü, 2008.

[8] E. Özkök, "Düşük manyetik alan algılama için fluxgate sensör geliştirme ve optimizasyonu," Yüksek Lisans Tezi, Yildiz Teknik Üniversitesi Fen Bilimleri Enstitüsü, İstanbul, 2017, sf. 12-17.

[9] H. Can, "Farklı uygulama alanlaı için fluxgate sensör tasarımı ve opimizasyonu," Doktora Tezi, Gebze Teknik Üniversitesi Fen Bilimleri Enstitüsü, 2018, sf. 6.

[10] Imperial College London, “Fluxgate Magnetometers,” Web [Online]. (https://www.imperial.ac.uk/space-and-atmospheric-physics/research/areas/space-magnetometer-laboratory/space-instrumentation-research/magnetometers/fluxgate-magnetome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), Erişim tarihi: 22 Nisan 2023.

[11] X. Shen, Y. Teng, and X. Hu, “Design of a Low-Cost Small-Size Fluxgate Sensor,” Sensors, vol. 21, no. 19, p. 6598, Oct. 2021, doi: 10.3390/s21196598.

[12] R. Noble, "Fluxgate Magnetometry," Electronics World + Wireless World, Eylül 1991, sf. 726.

[13] R. Clarke, “Fluxgate Magnetometer,” Web [Online], 2007, (https://www.clarcana.info/proj/magnetometer/index.html), Erişim tarihi: 18 Ağustos 2023.

[14] W. Y. Du, Resistive, Capacitive, Inductive, and Magnetic Sensor Technologies, CRC Press, 2014, sf. 209.

[15] W. Y. Du, Resistive, Capacitive, Inductive, and Magnetic Sensor Technologies, CRC Press, 2014, sf. 206.

[16] K. Evans, "Fluxgate Magnetometer Explained," 23 Ekim 2006. Web [Online] (http://www.invasens.co.uk/FluxgateExplained.PDF), Erişim tarihi: 11.06.2023.

[17] H. Can, "Farklı uygulama alanlaı için fluxgate sensör tasarımı ve opimizasyonu," Doktora Tezi, Gebze Teknik Üniversitesi Fen Bilimleri Enstitüsü, 2018, sf. 9.

[18] "‘Supermalloy: a New Magnetic Alloy," Nature 161, p. 554, 1948, (https://doi.org/10.1038/161554a0).

[19] "Wikipedia- Permeability (electromagnetism)," [Online]. (https://en.wikipedia.org/wiki/Permeability_(electromagnetism)) Erişim tarihi: 30.12.2022.

[20] D. M. Miles, R. Dvorsky, K. Greene, C. T. Hansen, B. B. Narod, ve M. D. Webb, “Contributors to fluxgate magnetic noise in permalloy foils including a potential new copper alloy regime,” Geosci. Instrum. Method. Data Syst., vol. 11, sf. 111–126, 2022, (https://doi.org/10.5194/gi-11-111-2022).

[21] D. M. Miles, M. Ciurzynski, D. Barona, B. B. Narod, J. R. Bennest, A. Kale, M. Lessard, D. K. Milling, J. Larson, ve I. R. Mann, “Low-noise permalloy ring cores for fluxgate magnetometers,” Geosci. Instrum. Method. Data Syst, vol. 8, sf. 227-240, 2019,
(https://doi.org/10.5194/gi-8-227-2019).

[22] S. A. Macintyre, J. G. Webster, "Magnetic Field Measurement," Electricial Measurement, Signal Proccessing and Displays, CRC Press, Bölüm: 12-1, 2004.

[23] YSX321SL CRYSTAL UNIT Datasheet, YXC. Crystal, Shenzen, 2021.

[24] Preliminary Datasheet LP1111, Lowpowersemi, China, 2017.

[25] AP2300 N-Channel MOSFET, All Power Semi Conducter Ltd., v1.0.

[26] Adjustable Precision Shunt Regulators: AN431, D. Incorporated, Rev. 3 - 2.

[27] “MSP430F2xx, MSP430G2xx Family User’s Guide”, Texas Instruments, REVISED AUGUST 2022.

[28] Raspberry Pi Pico Datasheet, Raspberry Pi Trading Ltd, build-version: 000dcb1-clean, 2021.

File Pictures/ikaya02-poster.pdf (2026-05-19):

# Fluxgate Tipi Manyetik Alan Sensörü Tasarımı

Erdem METİN
erdem-metin@windowslive.com

Mücahit ATA
6934muco@gmail.com

Proje Danışmanı : Prof.Dr. İsmail KAYA ikaya@ktu.edu.tr

Yapılan proje sayesinde çok çeşitli Fluxgate tipi manyetometrelerin geliştirilebilmesinin önü açılmış, yapılabilecek ileri çalışmalar sayesinde özel kullanım alanlarına yönelik sensörler geliştirilebilir. Üretilen Fluxgate sensöründe nüve, ADC ve sinyal işleme tekniği gibi konular geliştirilmeye açık olup elde edilen mevcut hassasiyetle basit bir pusula uyarlaması yapmak mümkün olmuştur. Elde edilen sensörün kalibrasyonu, tasarlanan 6-81 Permalloy malzeme bazlı bir nüvenin üretimi gibi aşamaların ilerletilmesi ile proje hedefi olan 1pT gürültü oranına ulaşılması mümkün olabilir.

Çözünürlük, ölçüm aralığı, kompakt boyutları gibi özellikleri yönünden Fluxgate tipi manyetik alan sensörleri bir üstünlüğe sahiptir. Bu projede de bir Fluxgate sensörü üretilmiş ve klasik yöntemlerin dışında sayısal sinyal işleme teknikleriyle beraber 24 bit çözünürlüğe sahip sensör verisi elde edilmeye çalışılmıştır. Bunların yanı sıra Fluxgate nüvesi, sinyalin analog olarak işlenmesi, alınan verinin kablosuz olarak gönderilmesi gibi konulara da odaklanılmıştır

Analog bazlı sinyal işleme tekniklerinde birçok faktörden dolayı ulaşılabilecek çözünürlük ve gürültü seviyeleri sınırlanmaktadır. Bu probleme karşın, sensör verisi sayısal olarak işlenirse daha üstün bir performans elde edilmesi mümkün olabilir. Nüve tasarımı ve nüve malzemesinde yapılacak geliştirmelerle beraber çok hassas manyetik akı yoğunluğu ölçümleri mümkün hale gelecektir. Bu sayede havacılıkta, Jeomanyetik haritalandırma çalışmalarında ve Manyeto kardiyografi gibi manyetik alanların hassas bir şekilde ölçülmesini gerektirecek alanlar için vektörel bir manyetometre geliştirmek amaçlanmıştır.

Algılanan sinyalin yorumlanabilmesi için bu sinyalin ortalama ve etkin değerini bilmemiz yeterlidir. Bunun için ADC üzerinden alınan veriyi sayısal olarak işleyecek bir sistem tasarlanmıştır.

1Hz | 10Hz | 100Hz | 1KHz

0dB

2dB

4dB

6dB

8dB

10dB

12dB

14dB

16dB

18dB

20dB

22dB

-88°

-80°

-72°

-64°

-56°

-48°

-40°

-32°

-24°

-16°

-8°

0° V(integrator)

SINE(0 .1 250 0.1p 0.1p 0)

V1

PULSE(-2 2 0 0.1p 0.1p 0.002 0.004 0)

V3

U1

LT1498

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
SPDT

U3

LT1498

R8

10k

C3

10n

R4

100k

C2

100n

R6

56k

U4

LT1498

R1

200k
R2

100k
R3

100k R9 200k

+5v
-5v

+5v

demodulator

-5v

+5v -5v

lowpass

integrator

+5v -5v

preamp

.tran 0 .2 0.0 startup

.subckt SPDT COM NO NC POS NEG
S1 COM NO POS NEG MYSW1
S2 COM NC NEG POS MYSW2
.model MYSW1 SW(Ron=.01 Roff=1000Meg Vh=.25 Vt=.5) .model MYSW2 SW(Ron=.01 Roff=1000Meg Vh=.25 Vt=-.5) .ends

Senkron Demodülatör Devresi

Lowpass İntegral Alıcı Filtre

2F frekansında darbe

2F frekansında algılanan sinyal

RC Lowpass Filtre

1:2 Preamp Farksal Giriş

Simülasyon aşamasında tasarlanan analog sinyal işleme devresine ve uyarma devresine ilişkin simülasyonlar yapılmıştır.

Fluxgate Etkisi

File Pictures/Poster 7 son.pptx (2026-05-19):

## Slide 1

Fluxgate Tipi Manyetik Alan Sensörü Tasarımı

Proje Danışmanı : Prof.Dr. İsmail KAYA
ikaya@ktu.edu.tr

Analog bazlı sinyal işleme tekniklerinde birçok faktörden dolayı ulaşılabilecek çözünürlük ve gürültü seviyeleri sınırlanmaktadır. Bu probleme karşın, sensör verisi sayısal olarak işlenirse daha üstün bir performans elde edilmesi mümkün olabilir. Nüve tasarımı ve nüve malzemesinde yapılacak geliştirmelerle beraber çok hassas manyetik akı yoğunluğu ölçümleri mümkün hale gelecektir. Bu sayede havacılıkta, Jeomanyetik haritalandırma çalışmalarında ve Manyeto kardiyografi gibi manyetik alanların hassas bir şekilde ölçülmesini gerektirecek alanlar için vektörel bir manyetometre geliştirmek amaçlanmıştır.

Erdem METİN
erdem-metin@windowslive.com

Mücahit ATA
6934muco@gmail.com

Çözünürlük, ölçüm aralığı, kompakt boyutları gibi özellikleri yönünden Fluxgate tipi manyetik alan sensörleri bir üstünlüğe sahiptir. Bu projede de bir Fluxgate sensörü üretilmiş ve klasik yöntemlerin dışında sayısal sinyal işleme teknikleriyle beraber 24 bit çözünürlüğe sahip sensör verisi elde edilmeye çalışılmıştır. Bunların yanı sıra Fluxgate nüvesi, sinyalin analog olarak işlenmesi, alınan verinin kablosuz olarak gönderilmesi gibi konulara da odaklanılmıştır

Özet

Giriş

Algılanan sinyalin yorumlanabilmesi için bu sinyalin ortalama ve etkin değerini bilmemiz yeterlidir. Bunun için ADC üzerinden alınan veriyi sayısal olarak işleyecek bir sistem tasarlanmıştır.

Konu

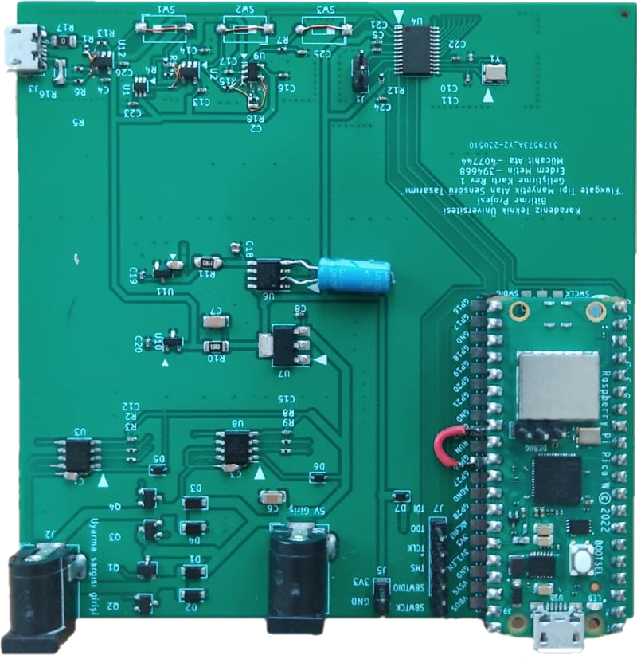
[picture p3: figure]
elektronik donanım, devre, elektronik mühendisliği, elektronik bileşen içeren bir resim Açıklama otomatik olarak oluşturuldu
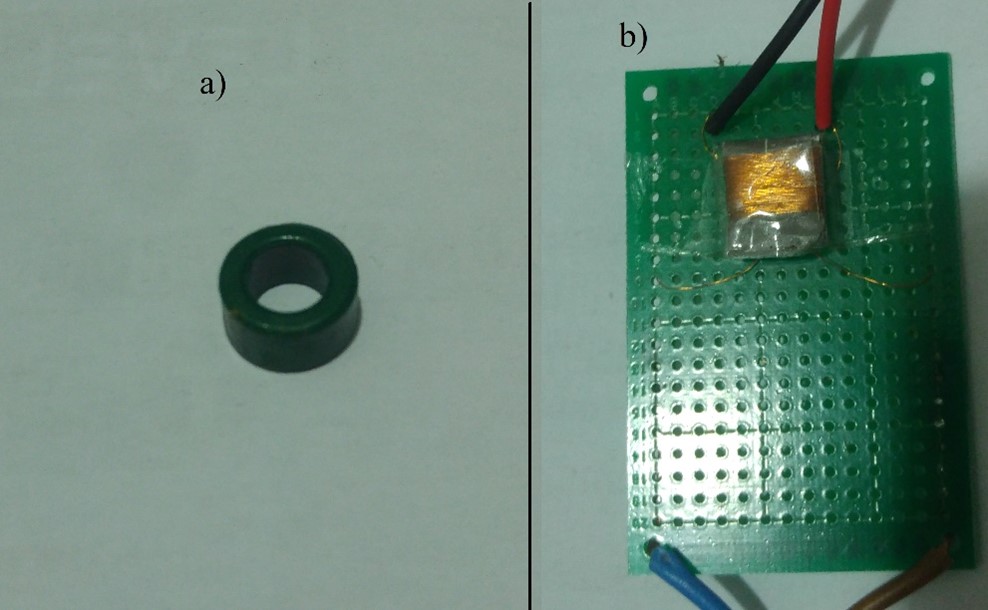
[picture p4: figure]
elektronik donanım, elektronik mühendisliği, Elektrik kabloları, devre bileşeni içeren bir resim Açıklama otomatik olarak oluşturuldu
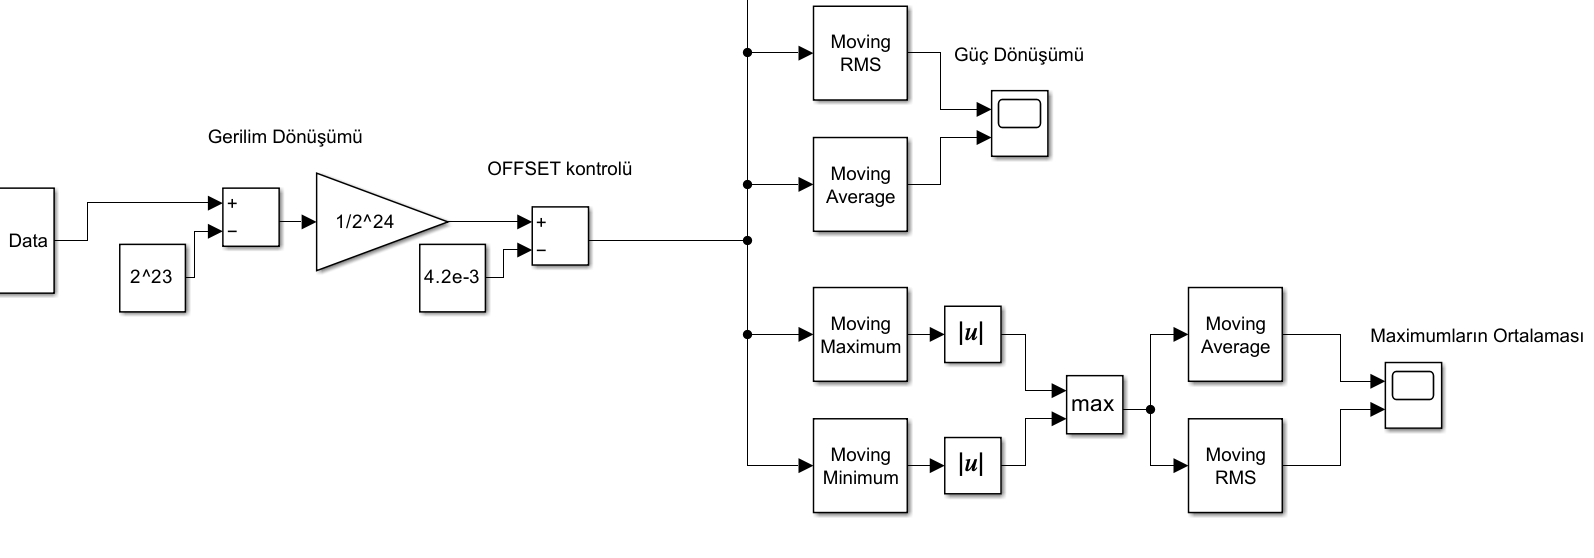
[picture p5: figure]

Tasarım

Deneysel bağlantı diyagramları

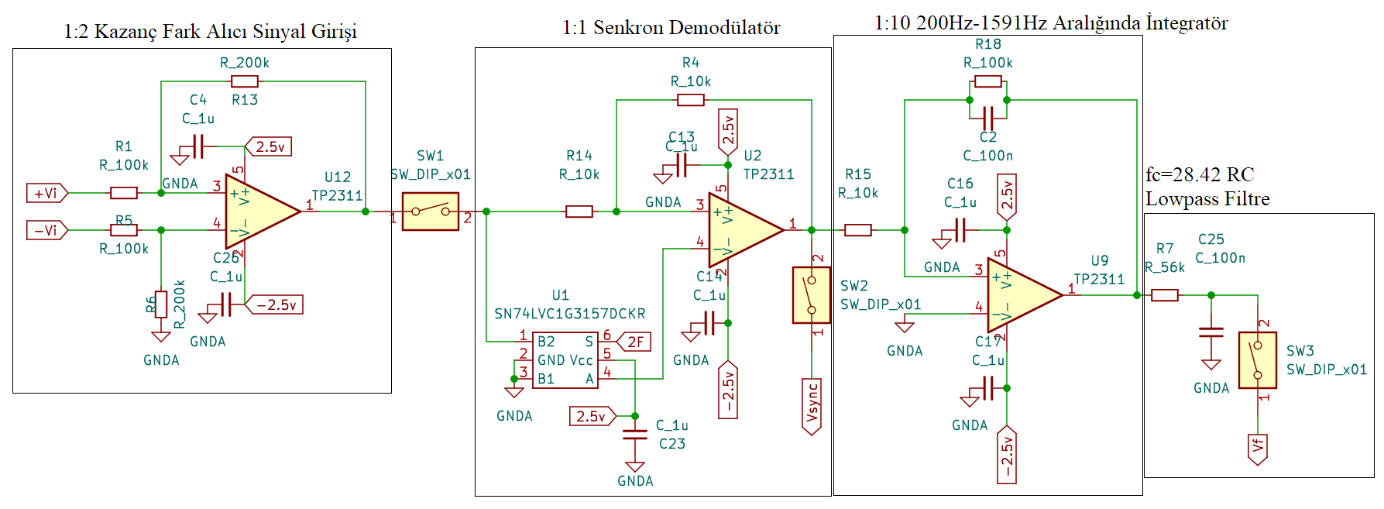
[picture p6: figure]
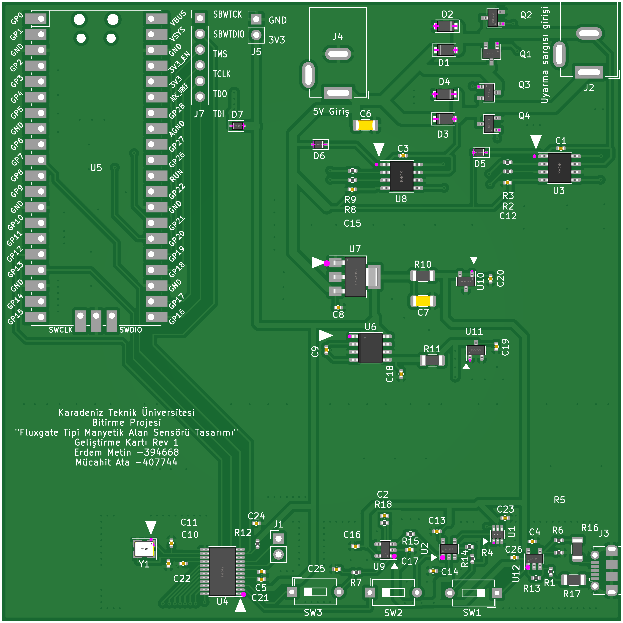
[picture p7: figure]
devre, metin, ekran görüntüsü, harita içeren bir resim Açıklama otomatik olarak oluşturuldu
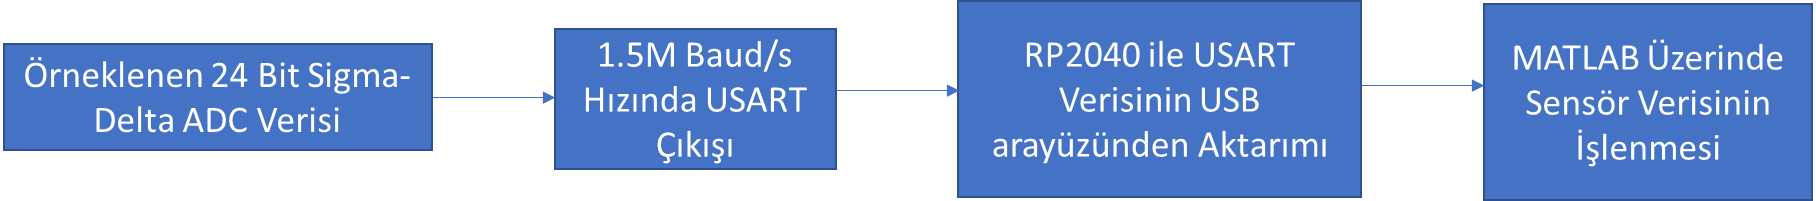
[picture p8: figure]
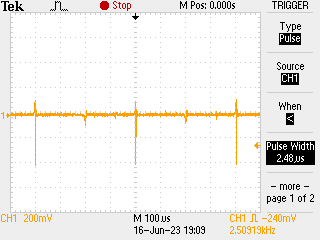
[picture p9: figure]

Fluxgate Etkisi

Simülasyon Sonuçları

Simülasyon aşamasında tasarlanan analog sinyal işleme devresine ve uyarma devresine ilişkin simülasyonlar yapılmıştır.

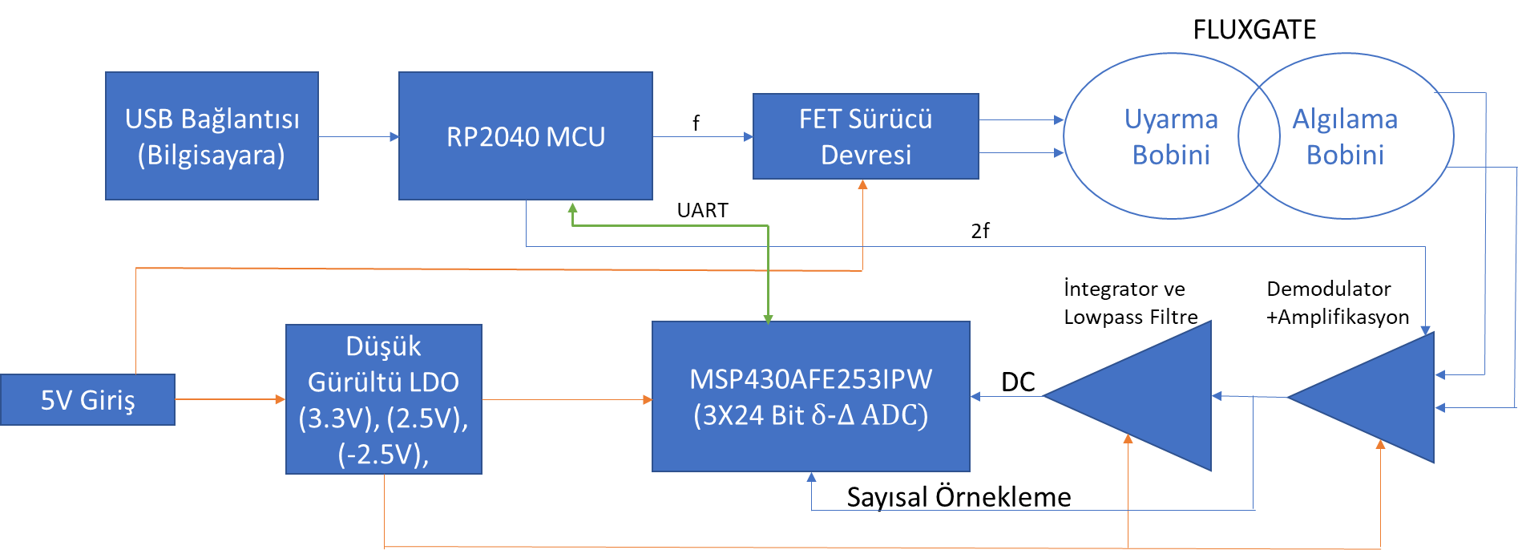
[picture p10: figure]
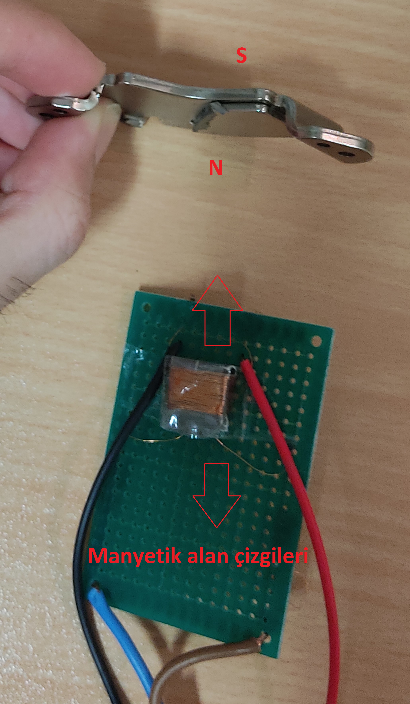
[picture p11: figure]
alet, elektronik mühendisliği, devre bileşeni, elektronik bileşen içeren bir resim Açıklama otomatik olarak oluşturuldu

Değerlendirme

Yapılan proje sayesinde çok çeşitli Fluxgate tipi manyetometrelerin geliştirilebilmesinin önü açılmış, yapılabilecek ileri çalışmalar sayesinde özel kullanım alanlarına yönelik sensörler geliştirilebilir. Üretilen Fluxgate sensöründe nüve, ADC ve sinyal işleme tekniği gibi konular geliştirilmeye açık olup elde edilen mevcut hassasiyetle basit bir pusula uyarlaması yapmak mümkün olmuştur. Elde edilen sensörün kalibrasyonu, tasarlanan 6-81 Permalloy malzeme bazlı bir nüvenin üretimi gibi aşamaların ilerletilmesi ile proje hedefi olan 1pT gürültü oranına ulaşılması mümkün olabilir.

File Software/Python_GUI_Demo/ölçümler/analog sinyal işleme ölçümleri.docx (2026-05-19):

Analog sinyal işleme devresindeki hatalar:

İlk başta Op-Amp’ların sahte olduğu ve bu yüzden devrenin çalışmadığı düşünülmüştü. Sonrasında tasarımda yapılan hatanın (şekil xx) fark edilmesi üzerine PCB’deki hatalı yollar kazınarak söküldü ve şekil xx’deki gibi yeni bağlantılar yapıldı. Bu işlemlerden sonra analog sinyal işleme devresi ile sinyal işlemek mümkündü.

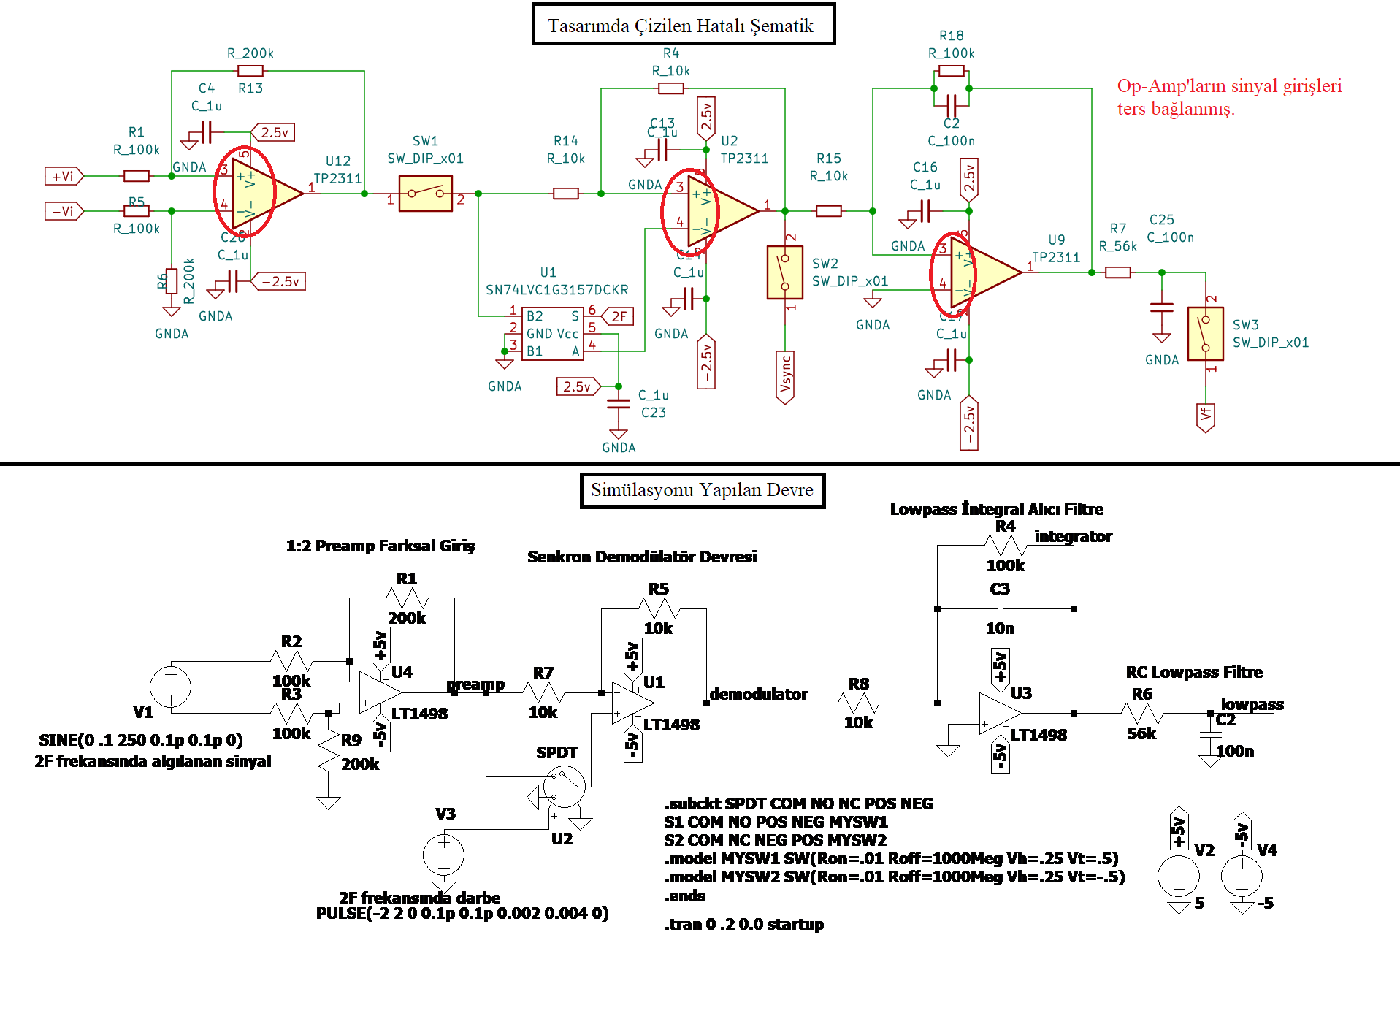
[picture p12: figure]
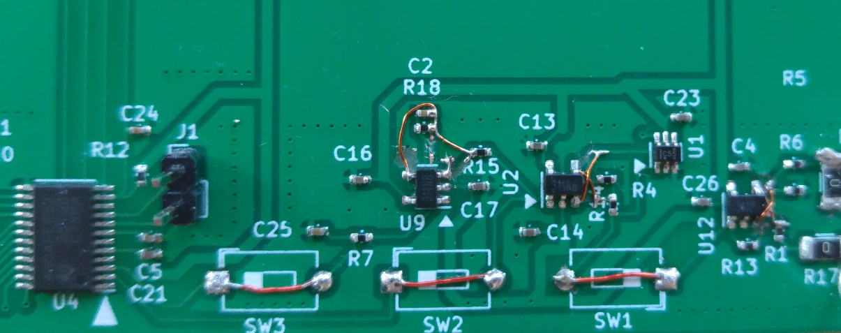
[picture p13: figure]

Nüvenin satürasyon süresi 70 mikrosaniye olarak ölçüldü. Satürasyonun garantilenmesi için 80 mikrosaniyelik merdiven dalga formu üretildi.

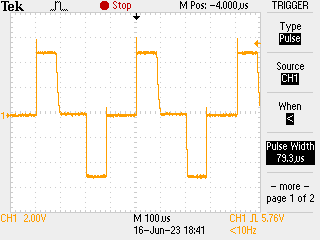
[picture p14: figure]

Uyarma altında dalga formu bu şekilde oldu. Endüktansın dolması ve nüenin çökmesi bu aralıklarda oldu (şekilde göster).

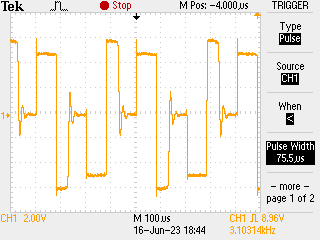
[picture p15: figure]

Ortam manyetik alanı altında yaklaşık -400mV tepe değerli algılama sinyali elde edildi


Nüveye kuzey kutbundan şekil x deki gibi mıknatıs yaklaştırılınca yaklaşık -800mV tepe değerli algılama sinyali elde edildi

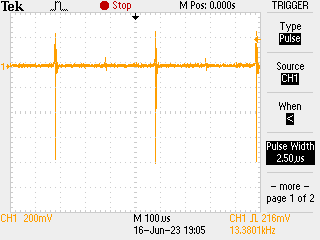
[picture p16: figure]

Aynı mesafeden mıknatısın güney kutbu yaklaştırıldığında yaklaşık 600mV tepe değerli algılama sinyali elde edildi.

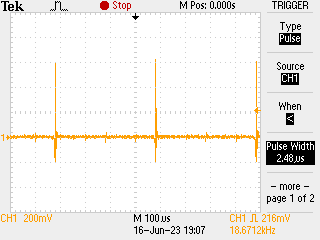
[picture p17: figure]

Analog sinyal işleme sonuçları

Şekil xx’deki (önceki şekil) ortam manyetik alanı nüve konumu değiştirilmeden, 1:2 kazanç oranlı preamp devresi sonrasında aşağıdaki gibi olmuştur.

Bu sinyalde uyarma geriliminin oluşturduğu gürültü vardır. Bu gürültüyü gidermek için senkron demodülasyon işlemi yapılmalıdır.

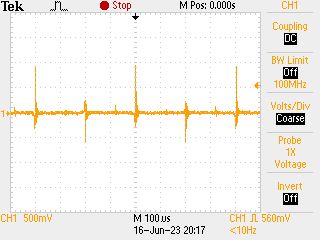
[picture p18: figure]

Senkron demodülasyon için demodülasyon sinyali şekil X’deki ikinci kanal gibi üretilmiştir. Bu şekildeki birinci kanal (CH1) uyarma devresinin ileri veya geri fazının anahtarlanmasını ifade etmektedir. Demodülasyon işleminde elde edilmek istenen sonuç ise nüvenin ilk anahtarlanması anında oluşan gürültüyü engellemektir. Bu yüzden nüvenin indüklenme frekansından 40us ileri fazda, 120us genişliğinde, 200us periyodunda bir sinyal üretilmiştir. Böylece demodülatör devresi nüvenin sadece çökme (uyarma geriliminin sıfıra düştüğü bölge) anlarını yakalayacaktır.

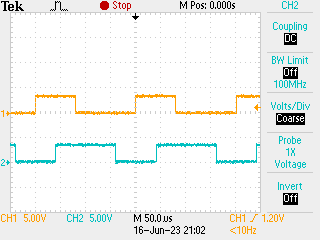
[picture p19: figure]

Demodulasyon işleminin sonucunda şekil x’deki gibi demodulator çıkışı elde edilmiştir. Bu çıktıda, Şekil x’in aksine preamp devresi çıkışında bulunan uyarma gürültüsü mevcut değildir.

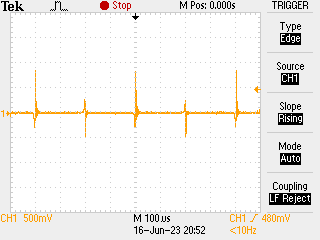
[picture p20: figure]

Demodüle edilen sinyalin artık gücü hesaplanabilir. Bunun için analog sinyal işleme devresinde bir adet integral alıcı Op-amp devresi ve bir adet RC alçak geçiren filtre bulunur. Bu işlemlerden de geçen sinyal artık doğru gerilim cinsinden elde edilen sinyalin ortalama gücünü verecektir.

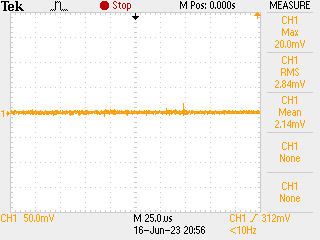
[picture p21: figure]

Sonuç olarak nüve rastgele bir konuma bakarken 2.14mV ortalama gerilime sahip bir sinyal okunmuştur. Bu sinyal artık ADC üzerinden okunarak bilgisayara aktarılabilir.

ADC üzerinden sinyallerin okunması ve mikrotesla dönüşümleri

Offset ayarı:

Yaklaşık 2.4mv offset okundu.

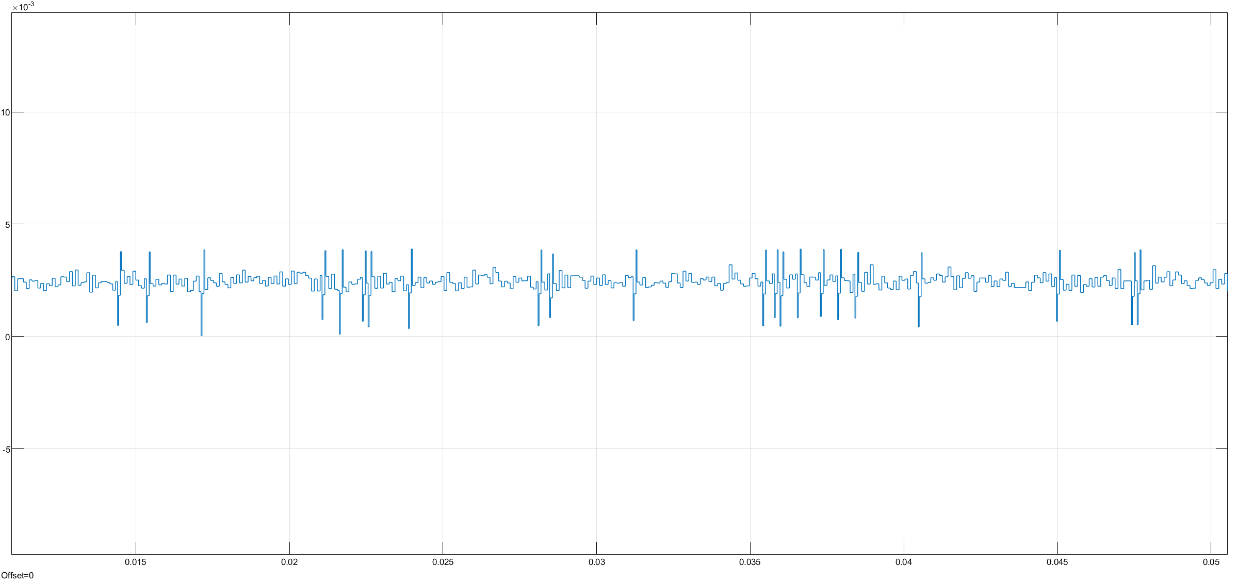
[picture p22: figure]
metin, çizgi, öykü gelişim çizgisi; kumpas; grafiğini çıkarma, diyagram içeren bir resim Açıklama otomatik olarak oluşturuldu

30ksps hızında ölçüm yapıldığından, her örnek değeri yaklaşık 33.33us zaman aralığında alınmaktadır. 200us periyodik aralıklarla gerçekleşen fluxgate algılama sinyalinde tercihen 10 adet ölçümün ortalama gücünü ve etkin değerini bulmak için Simulink üzerinde Moving Average ve Moving RMS blokları kullanılmıştır. 10 adet fluxgate etkisi 2ms edeceğinden, toplam 60 adet örneği kapsayacak şekilde bu bloklar konfigüre edilmiştir.

Analog sinyal işleme devresi 5kHz frekansında çalıştırıldığında, analog sinyal işleme devresinin çıkışında güçlü bir gerilim elde edilemedi. Elde edilen gerilm yaklaşık 50uT’lik ortam manyetik akı yoğunluğu için 2.14mV idi. Bu yüzden devrenin çalışma frekansında değişikliklere gidildi.

Bu değişiklikler yapılmadan önce 5kHz frekansında bir fluxgate sinyalinin simülasyonu yapıldı.

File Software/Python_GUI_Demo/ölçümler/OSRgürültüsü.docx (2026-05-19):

Osr 32:

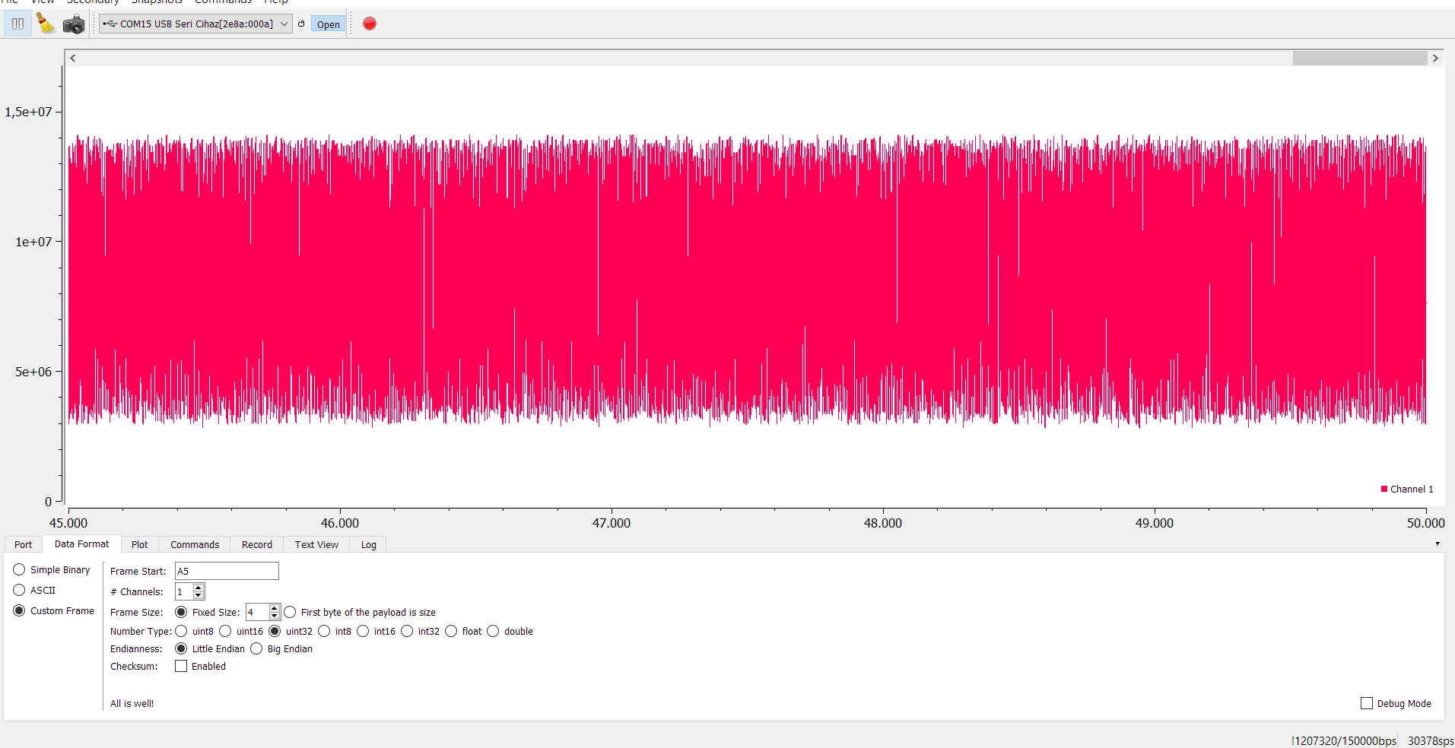
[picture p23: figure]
metin, ekran görüntüsü, yazılım içeren bir resim Açıklama otomatik olarak oluşturuldu

Osr: 64

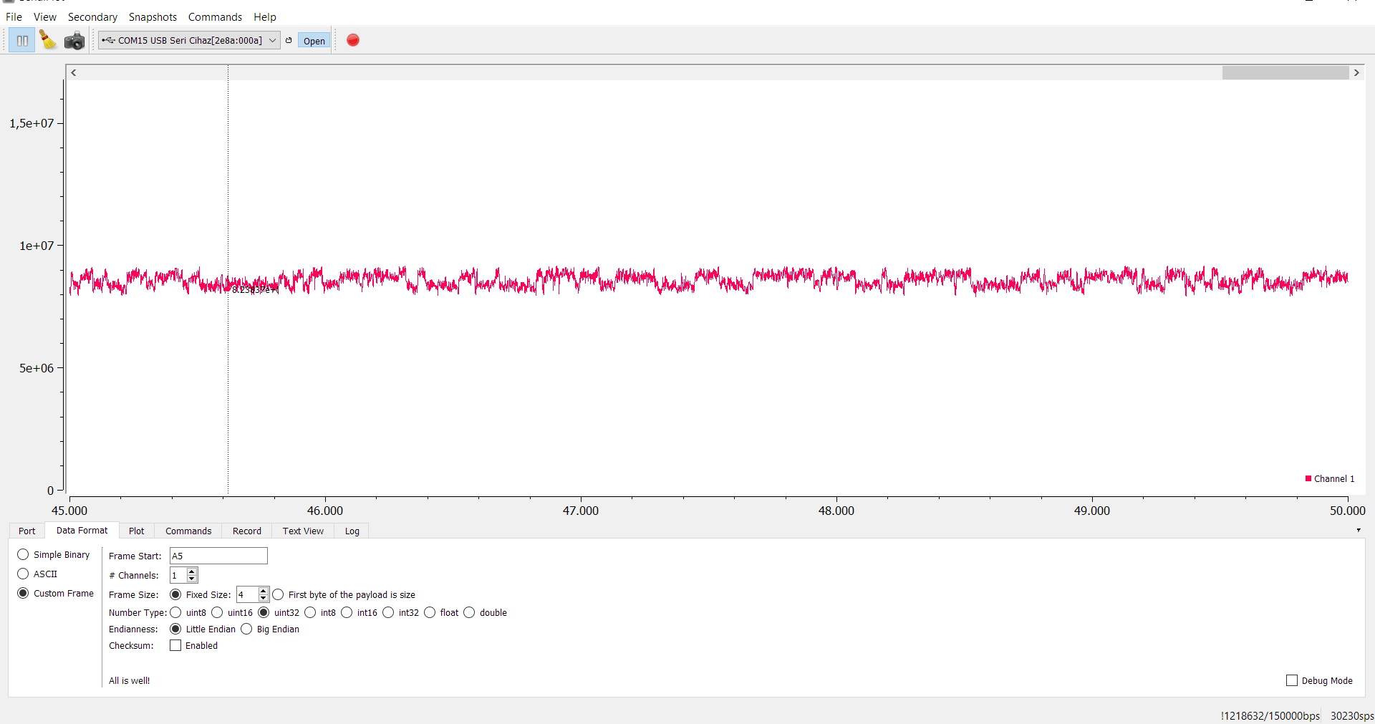
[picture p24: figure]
metin, ekran görüntüsü, yazılım, çizgi içeren bir resim Açıklama otomatik olarak oluşturuldu

Osr 128:

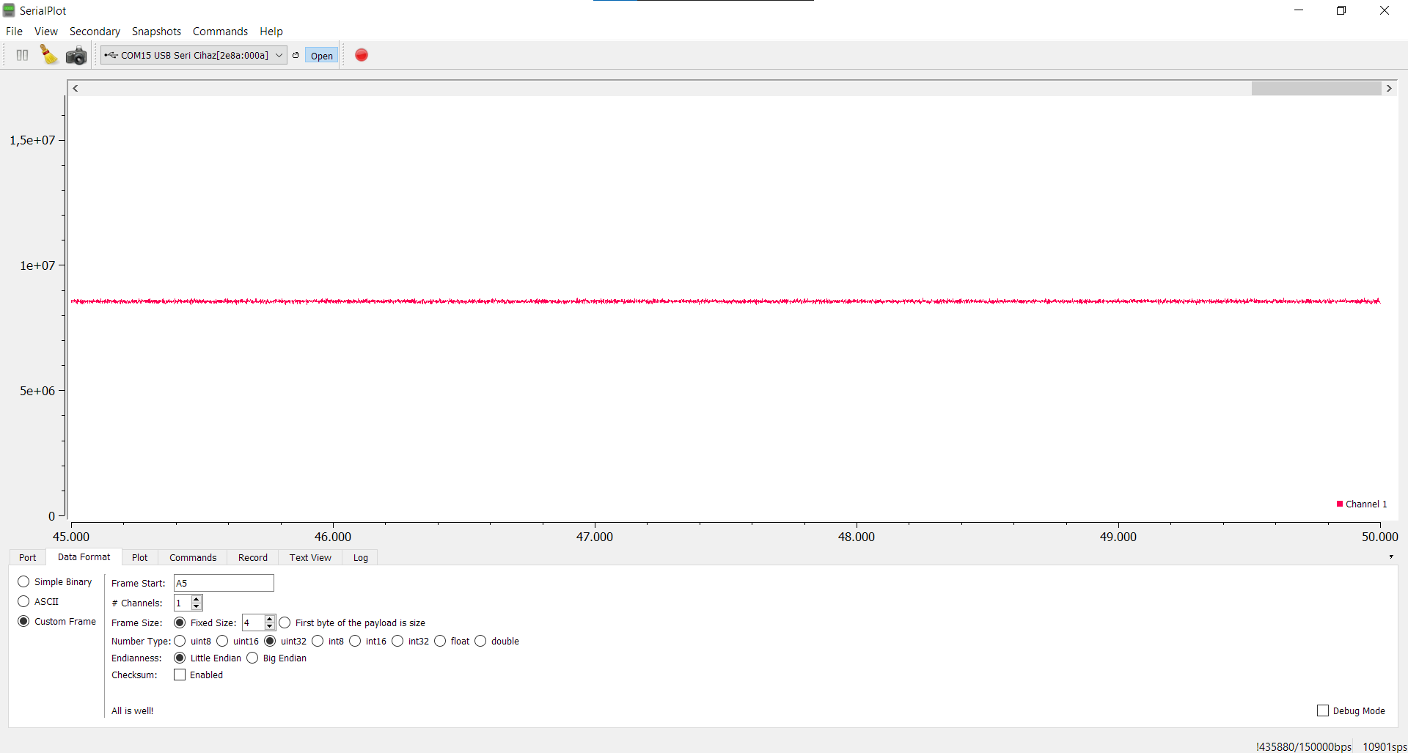
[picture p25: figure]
metin, ekran görüntüsü, yazılım, çizgi içeren bir resim Açıklama otomatik olarak oluşturuldu

Osr:1024

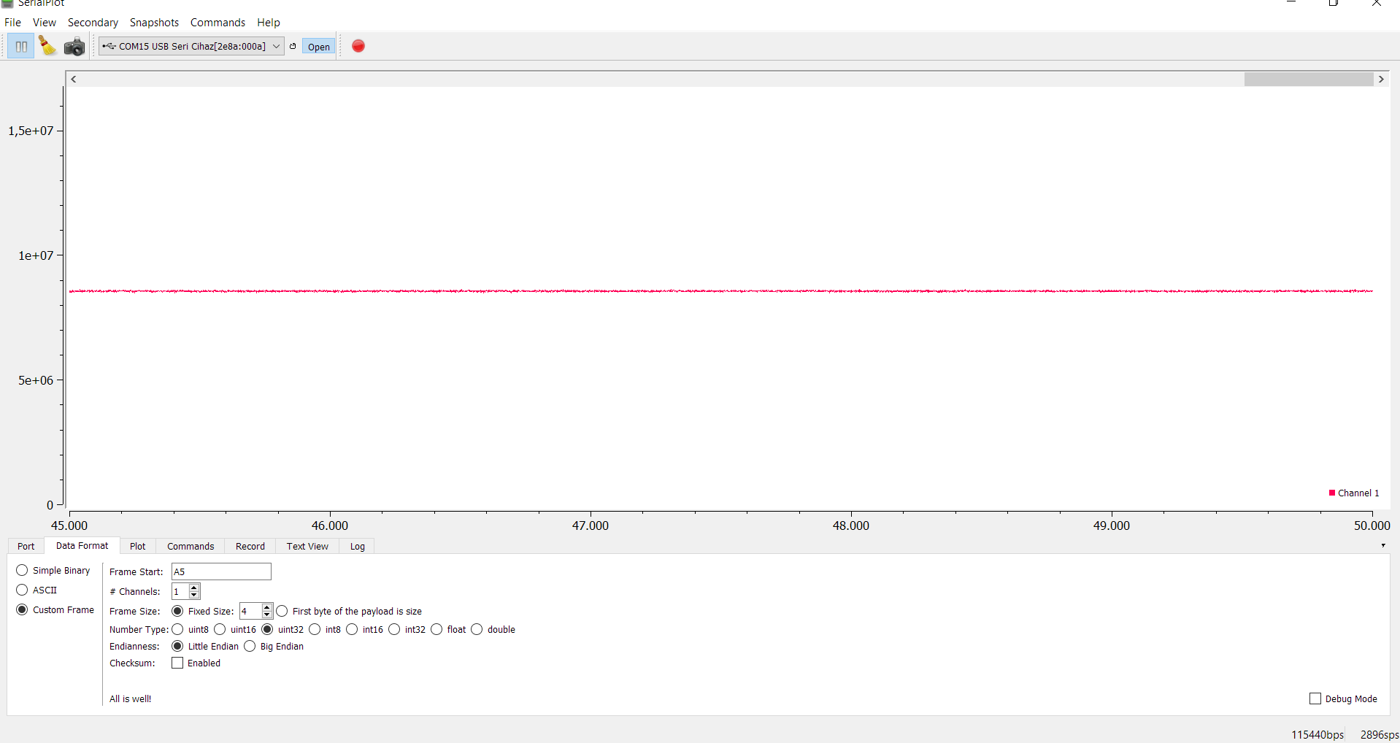
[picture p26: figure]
metin, ekran görüntüsü, yazılım, ekran, görüntüleme içeren bir resim Açıklama otomatik olarak oluşturuldu

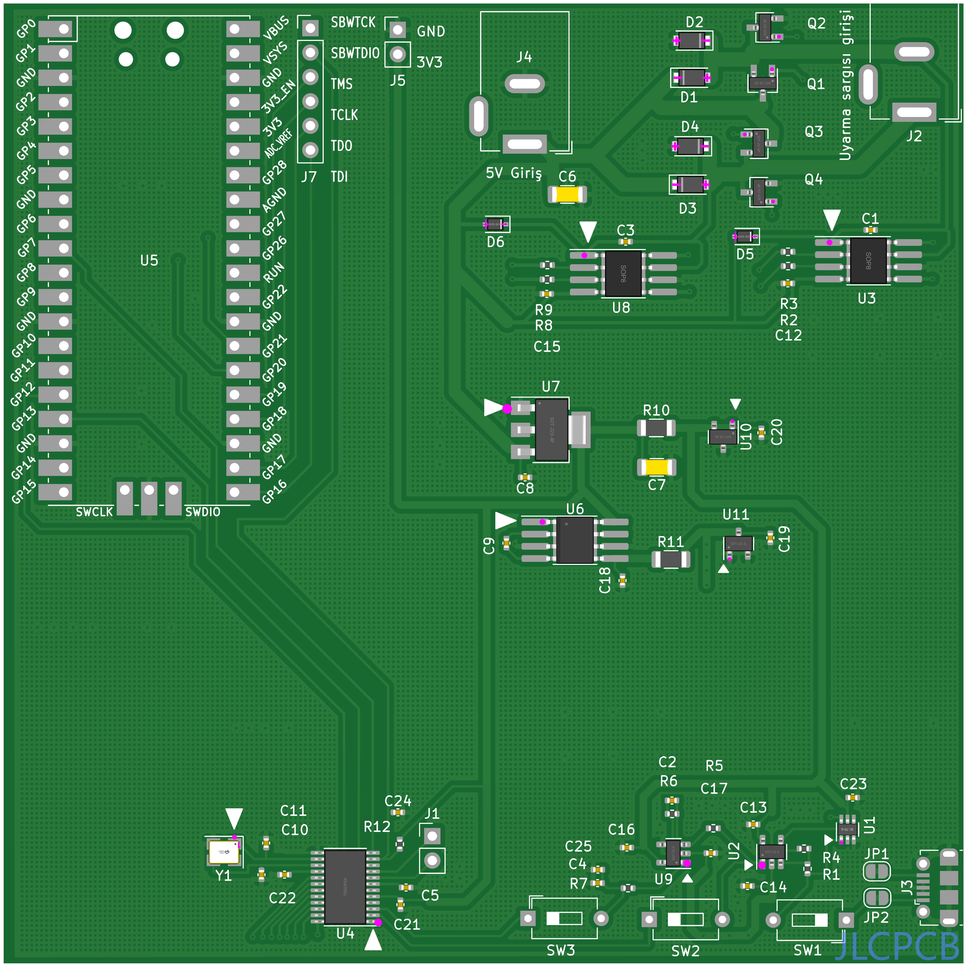
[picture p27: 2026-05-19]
Hardware/KiCad_Development_Board_JLCPCB/kontrol/pcb.png

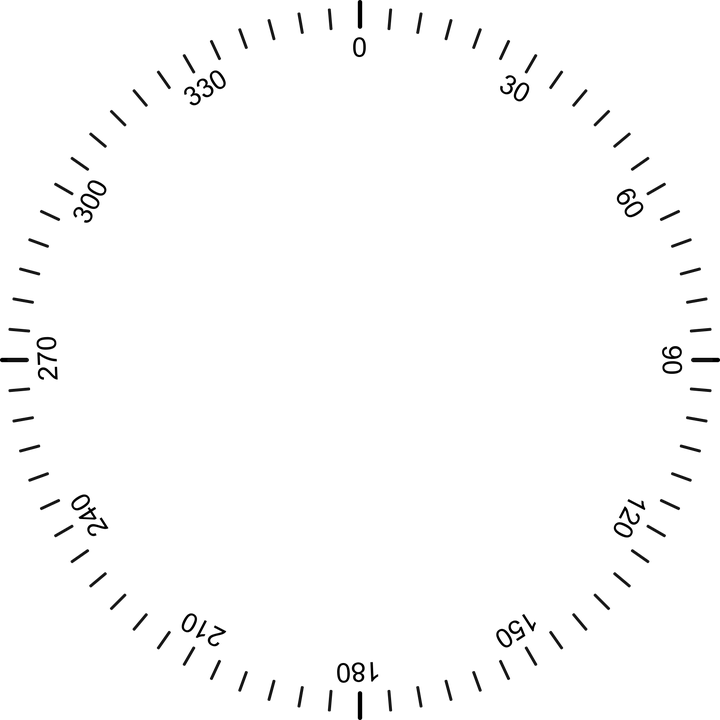
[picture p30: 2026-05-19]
Software/Python_GUI_Demo/dial.png

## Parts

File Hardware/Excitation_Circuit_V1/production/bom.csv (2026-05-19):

Designator | Footprint | Quantity | Value | LCSC Part #
C1, C3 | CP_Elec_3x5.3 | 2 | C_1u
C2 | CP_Elec_6.3x3.9 | 1 | C_100n
C4 | CP_Elec_6.3x3.9 | 1 | C_200n
C5 | CP_Elec_6.3x4.5 | 1 | C_100n
C6, C7 | CP_Elec_3x5.3 | 2 | C_100u
C8, C9 | CP_Elec_3x5.3 | 2 | C_150u
D1, D2, D3, D4 | D_DO-201AD_P15.24mm_Horizontal | 4 | 1N5400
D5, D6 | D_DO-41_SOD81_P10.16mm_Horizontal | 2 | 1N4001
J1 | PinHeader_1x02_P1.27mm_Vertical_SMD_Pin1Left | 1 | Conn_01x02_Female
J2 | BarrelJack_CUI_PJ-036AH-SMT_Horizontal | 1 | 5v
J3 | BarrelJack_CLIFF_FC681465S_SMT_Horizontal | 1 | Uyarma sargısı bağlantısı
J4 | BarrelJack_CLIFF_FC681465S_SMT_Horizontal | 1 | Algılama sargısı bağlantısı
J5 | BarrelJack_CLIFF_FC681465S_SMT_Horizontal | 1 | Opsiyonel güç girişi
J6 | BarrelJack_CLIFF_FC681465S_SMT_Horizontal | 1 | Opsiyonel sinyal çıkışı
Q1, Q2, Q3, Q4 | TO254P1016X419X2286-3 | 4 | IRFZ44N
R1 | R_Axial_DIN0204_L3.6mm_D1.6mm_P5.08mm_Horizontal | 1 | R_1k
R2, R3, R4 | R_Axial_DIN0204_L3.6mm_D1.6mm_P5.08mm_Horizontal | 3 | R_10k
R5, R6, R7 | R_Axial_DIN0204_L3.6mm_D1.6mm_P5.08mm_Horizontal | 3 | R_72k
SW1, SW2, SW3, SW4 | SW_DIP_SPSTx01_Slide_6.7x4.1mm_W8.61mm_P2.54mm_LowProfile | 4 | SW_DIP_x01
SW5, SW6 | SW_Push_2P1T_Toggle_CK_PVA1xxH3xxxxxxV2 | 2 | Bypass anahtarı
U1 | Texas_S-PVSON-N10 | 1 | TS3A24159DRCR
U2 | SO-16_3.9x9.9mm_P1.27mm | 1 | LT1492
U3 | SOIC-16_3.9x9.9mm_P1.27mm | 1 | HIP4082xB
U4 | TSSOP-24_4.4x7.8mm_P0.65mm | 1 | MSP430AFE233IPW
U5 | RPi_Pico_SMD_TH | 1 | Pico
U6 | SO-8_3.9x4.9mm_P1.27mm | 1 | LTC660
U7 | SOT-223-3_TabPin2 | 1 | LD1117S33TR_SOT223
Y1 | 01005 | 1 | Crystal

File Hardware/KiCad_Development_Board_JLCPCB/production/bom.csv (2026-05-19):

Designator | Footprint | Quantity | Value | LCSC Part #
C1 | 0402 | 1 | C_1.1nf
C10 | 0402 | 1 | C_18p
C11 | 0402 | 1 | C_18p
C12 | 0402 | 1 | C_1u
C13 | 0402 | 1 | C_1u
C14 | 0402 | 1 | C_1u
C15 | 0402 | 1 | C_1u
C16 | 0402 | 1 | C_1u
C17 | 0402 | 1 | C_1u
C18 | 0402 | 1 | C_1u
C19 | 0402 | 1 | C_1u
C2 | 0402 | 1 | C_100n
C20 | 0402 | 1 | C_1u
C21 | 0402 | 1 | C_1u
C22 | 0402 | 1 | C_1u
C23 | 0402 | 1 | C_1u
C24 | 0402 | 1 | C_1.1nf
C25 | 0402 | 1 | C_100n
C26 | 0402 | 1 | C_1u
C3 | 0402 | 1 | C_1.1nf
C4 | 0402 | 1 | C_1u
C5 | 0402 | 1 | C_100n
C6 | 1206 | 1 | C_100u
C7 | 1206 | 1 | C_100u
C8 | 0402 | 1 | C_1u
C9 | 0402 | 1 | C_10u
D1, D2, D3, D4 | D_SOD-123F | 4 | 1N4007
D5, D6, D7 | D_SOD-323 | 3 | 1N4148WS
J1 | PinHeader_1x02_P2.54mm_Vertical | 1 | Conn_01x02_Female
J2, J4 | BarrelJack_GCT_DCJ200-10-A_Horizontal | 2 | Jack-DC
J3 | USB_Micro-B_Molex-105017-0001 | 1 | Algılama sargısı girişi
J5 | PinHeader_1x02_P2.54mm_Vertical | 1 | power
J7 | PinHeader_1x06_P2.54mm_Vertical | 1 | JTAG-SBW
Q1, Q2, Q3, Q4 | TSOT-23 | 4 | AP2300
R1 | 0402 | 1 | R_100k
R10 | 1206 | 1 | R_10
R11 | 1206 | 1 | R_10
R12 | 0402 | 1 | R_47k
R13 | 0402 | 1 | R_200k
R14 | 0402 | 1 | R_10k
R15 | 0402 | 1 | R_10k
R16 | 1206 | 1 | R_0
R17 | 1206 | 1 | R_0
R18 | 0402 | 1 | R_100k
R2 | 0402 | 1 | R_1k
R3 | 0402 | 1 | R_1k
R4 | 0402 | 1 | R_10k
R5 | 0402 | 1 | R_100k
R6 | 0402 | 1 | R_200k
R7 | 0402 | 1 | R_56k
R8 | 0402 | 1 | R_1k
R9 | 0402 | 1 | R_1k
SW1, SW2, SW3 | SW_DIP_SPSTx01_Slide_6.7x4.1mm_W7.62mm_P2.54mm_LowProfile | 3 | SW_DIP_x01
U1 | Texas_R-PDSO-G6 | 1 | SN74LVC1G3157DCKR
U10, U11 | SOT-23 | 2 | AN431
U12, U2, U9 | SOT-23-5 | 3 | TP2311
U3, U8 | SOP-8_3.9x4.9mm_P1.27mm | 2 | LP1111SOF
U4 | TSSOP-24_4.4x7.8mm_P0.65mm | 1 | MSP430AFE253IPW
U5 | RPi_Pico_SMD_TH | 1 | Pico
U6 | SOP-8_3.9x4.9mm_P1.27mm | 1 | ME7660C
U7 | SOT-223-3_TabPin2 | 1 | AMS1117-3.3V
Y1 | Crystal_SMD_3225-4Pin_3.2x2.5mm | 1 | Crystal_GND23_Small

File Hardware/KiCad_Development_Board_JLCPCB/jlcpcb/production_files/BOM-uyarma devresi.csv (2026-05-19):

Comment | Designator | Footprint | LCSC
TP2311 | U12,U2,U9 | SOT-23-5 | C116439
R_1k | R2,R3,R8,R9 | R_0402_1005Metric | C11702
C_100u | C6,C7 | C_1206_3216Metric | C15008
C_1.1nf | C1,C24,C3 | C_0402_1005Metric | C1523
C_100n | C2,C25,C5 | C_0402_1005Metric | C1525
C_18p | C10,C11 | C_0402_1005Metric | C1549
C_10u | C9 | C_0402_1005Metric | C15525
R_0 | R16,R17 | R_1206_3216Metric | C17888
R_10 | R10,R11 | R_1206_3216Metric | C17903
AP2300 | Q1,Q2,Q3,Q4 | TSOT-23 | C20917
1N4148WS | D5,D6,D7 | D_SOD-323 | C2128
R_100k | R1,R18,R5 | R_0402_1005Metric | C25741
R_10k | R14,R15,R4 | R_0402_1005Metric | C25744
R_200k | R13,R6 | R_0402_1005Metric | C25764
R_47k | R12 | R_0402_1005Metric | C25792
R_56k | R7 | R_0402_1005Metric | C25796
SN74LVC1G3157DCKR | U1 | Texas_R-PDSO-G6 | C38663
C_1u | C12,C13,C14,C15,C16,C17,C18,C19,C20,C21,C22,C23,C26,C4,C8 | C_0402_1005Metric | C52923
AMS1117-3.3V | U7 | SOT-223-3_TabPin2 | C6186
1N4007 | D1,D2,D3,D4 | D_SOD-123F | C64898
MSP430AFE253IPW | U4 | TSSOP-24_4.4x7.8mm_P0.65mm | C79303
Crystal_GND23_Small | Y1 | Crystal_SMD_3225-4Pin_3.2x2.5mm | C9002
AN431 | U10,U11 | SOT-23 | C97718
Conn_01x02_Female | J1 | PinHeader_1x02_P2.54mm_Vertical
LP1111SOF | U8 | SOP-8_3.9x4.9mm_P1.27mm
Algılama sargısı girişi | J3 | USB_Micro-B_Molex-105017-0001
Jack-DC | J4 | BarrelJack_GCT_DCJ200-10-A_Horizontal
Jack-DC | J2 | BarrelJack_GCT_DCJ200-10-A_Horizontal
ME7660C | U6 | SOP-8_3.9x4.9mm_P1.27mm
LP1111SOF | U3 | SOP-8_3.9x4.9mm_P1.27mm
power | J5 | PinHeader_1x02_P2.54mm_Vertical
JTAG-SBW | J7 | PinHeader_1x06_P2.54mm_Vertical
Pico | U5 | RPi_Pico_SMD_TH

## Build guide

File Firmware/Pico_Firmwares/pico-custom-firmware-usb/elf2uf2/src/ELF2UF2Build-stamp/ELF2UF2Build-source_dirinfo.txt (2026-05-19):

# This is a generated file and its contents are an internal implementation detail.
# The download step will be re-executed if anything in this file changes.
# No other meaning or use of this file is supported.

method=source_dir
command=
source_dir=C:/Users/ASUS/Downloads/pico-uart-bridge-4.1/pico-uart-bridge-4.1/pico-sdk/tools/elf2uf2
work_dir=

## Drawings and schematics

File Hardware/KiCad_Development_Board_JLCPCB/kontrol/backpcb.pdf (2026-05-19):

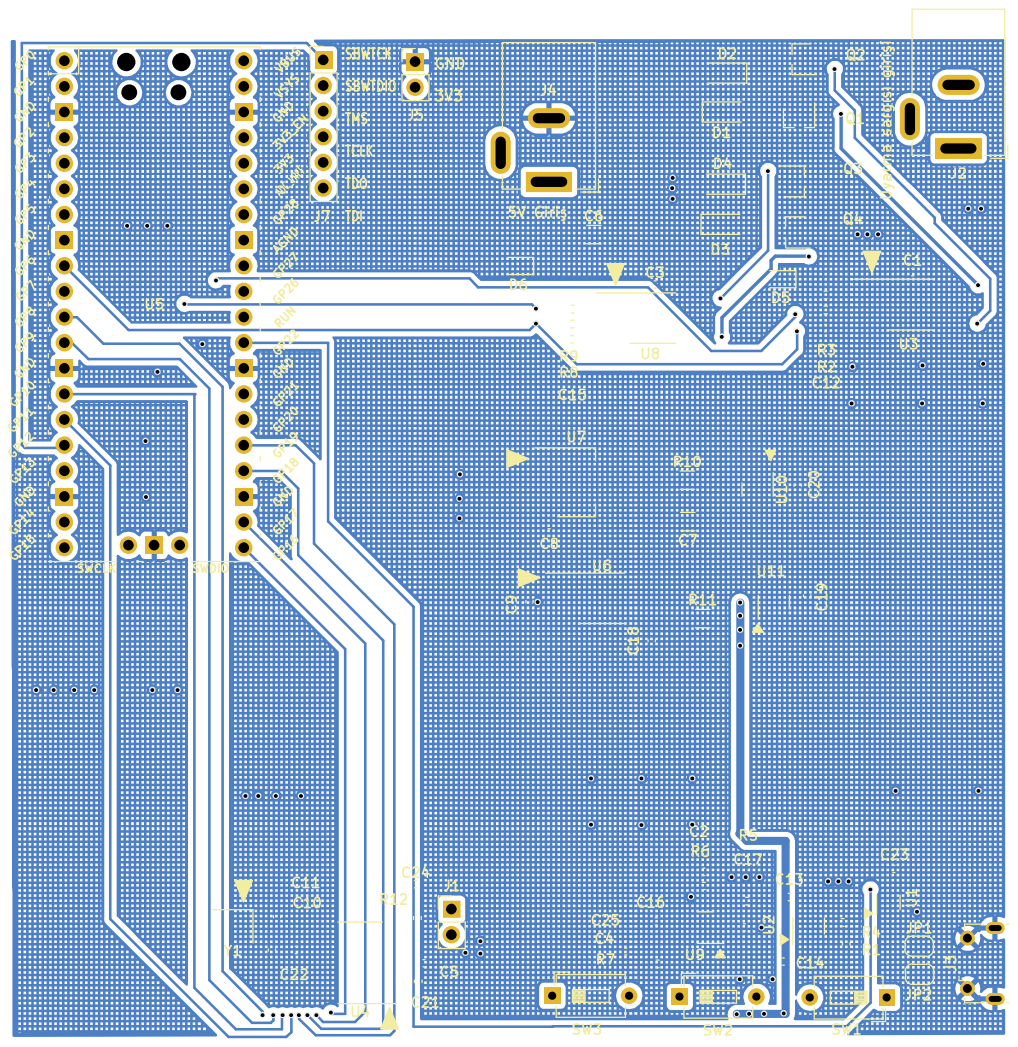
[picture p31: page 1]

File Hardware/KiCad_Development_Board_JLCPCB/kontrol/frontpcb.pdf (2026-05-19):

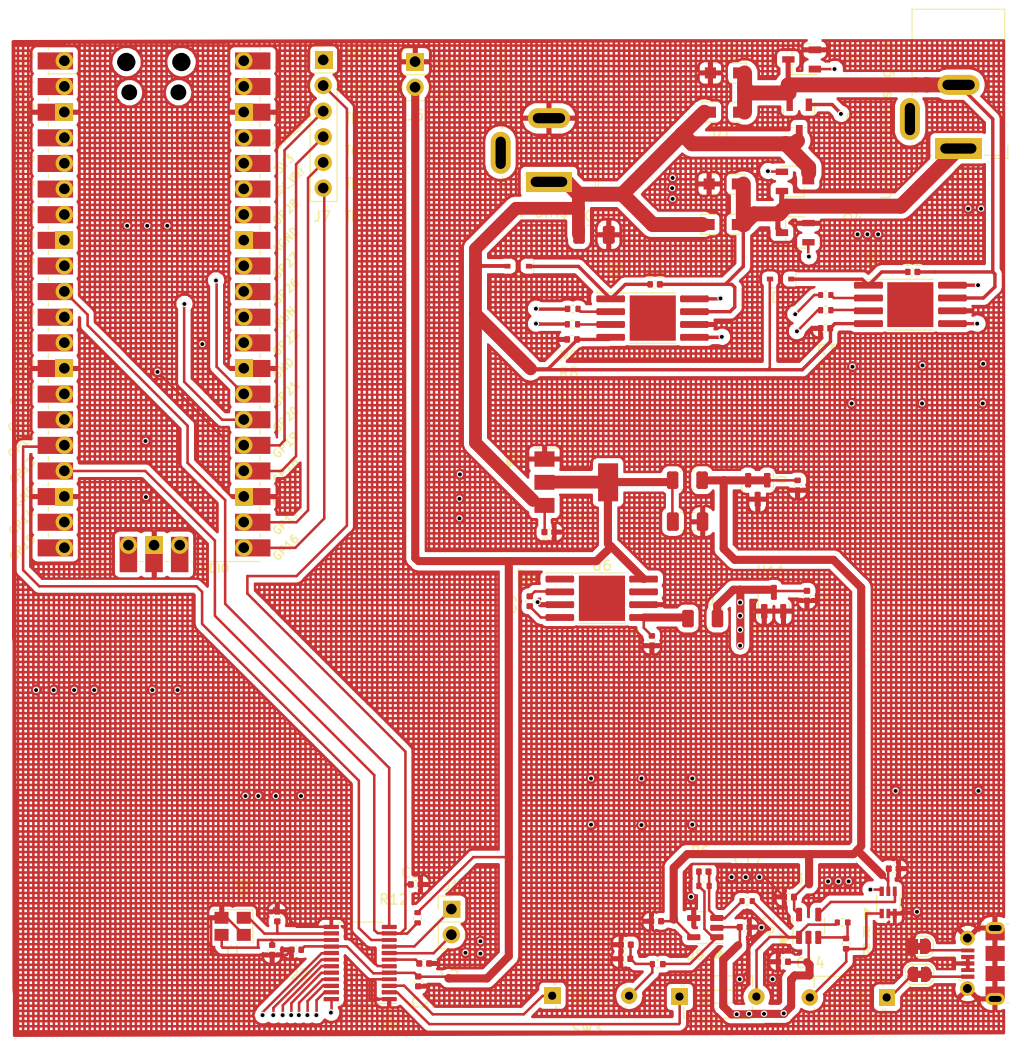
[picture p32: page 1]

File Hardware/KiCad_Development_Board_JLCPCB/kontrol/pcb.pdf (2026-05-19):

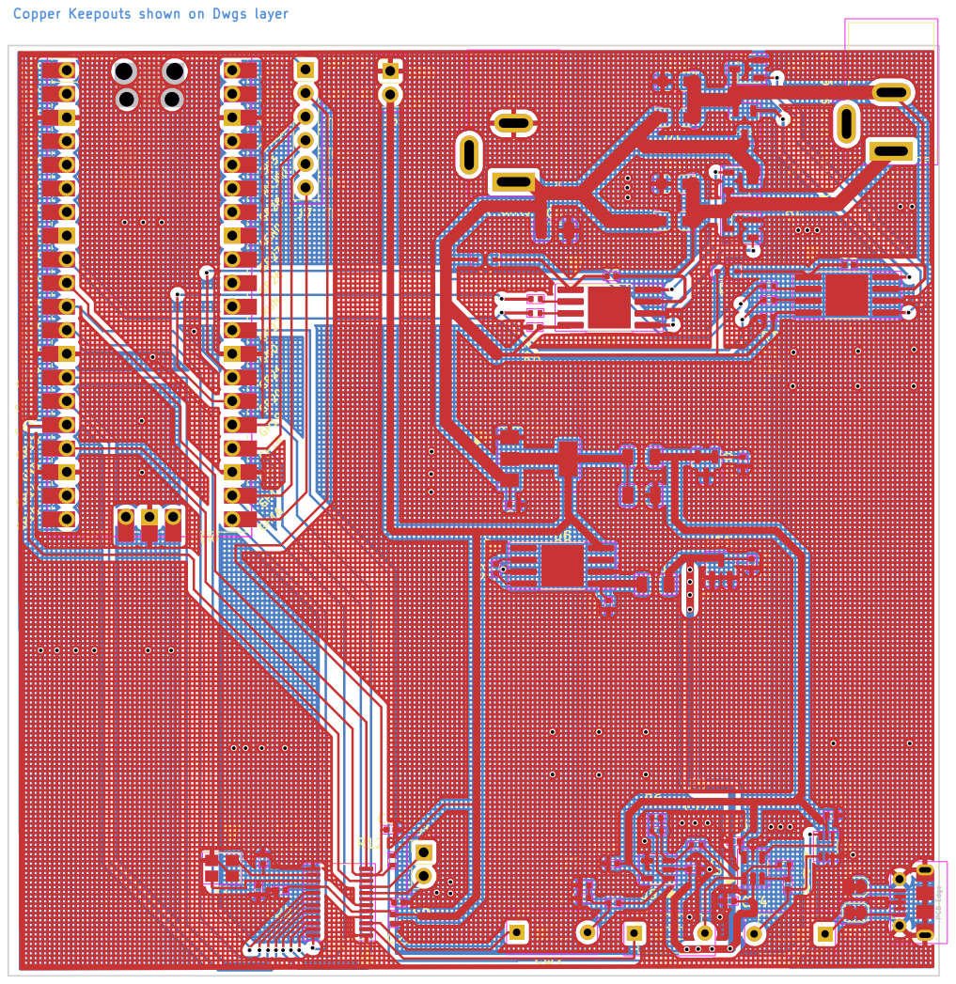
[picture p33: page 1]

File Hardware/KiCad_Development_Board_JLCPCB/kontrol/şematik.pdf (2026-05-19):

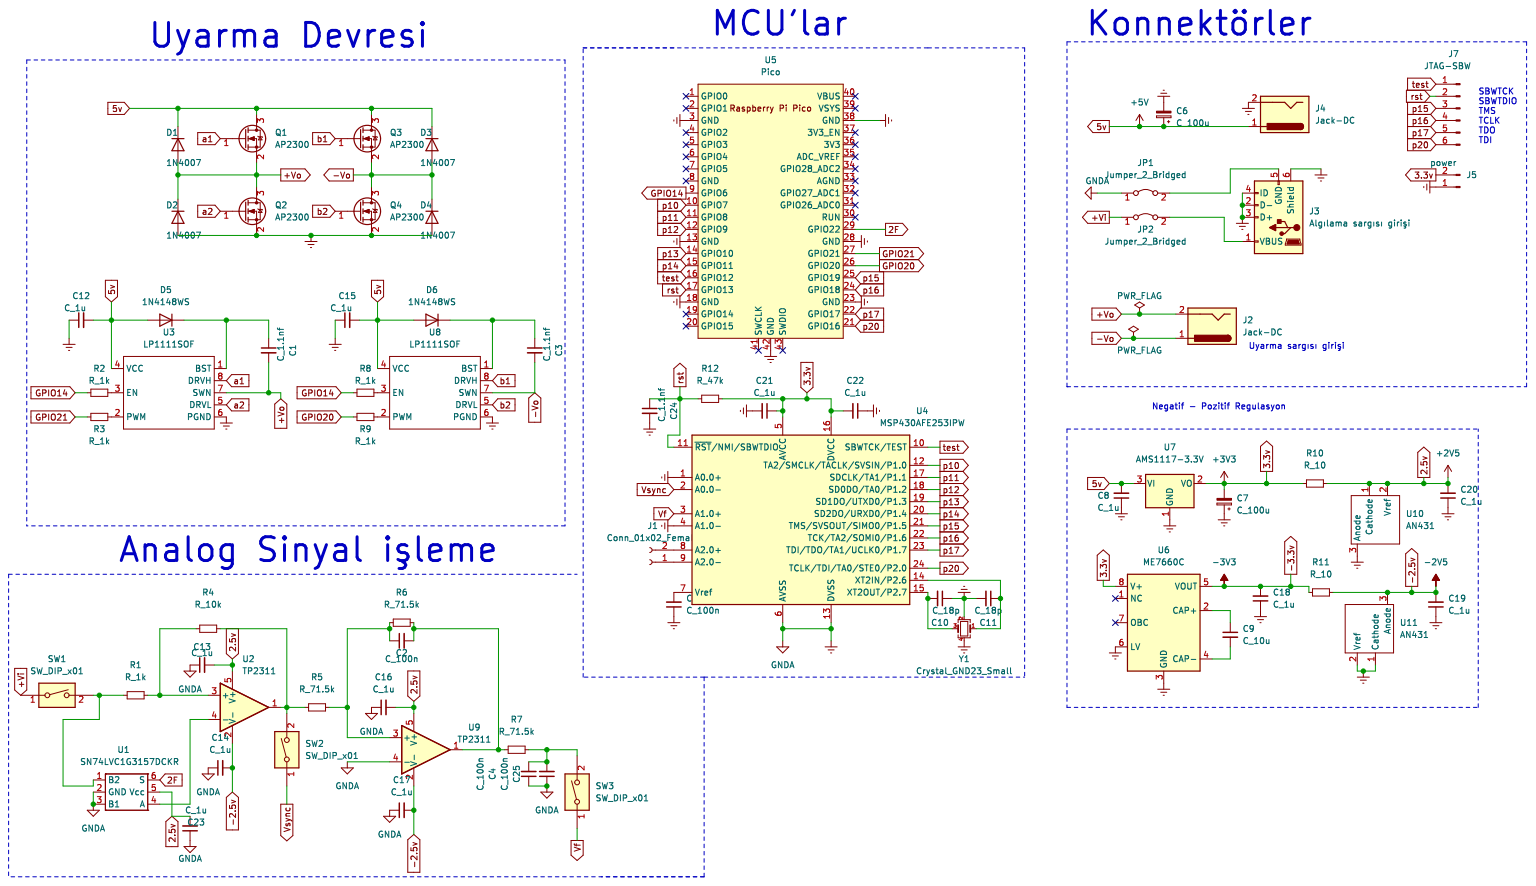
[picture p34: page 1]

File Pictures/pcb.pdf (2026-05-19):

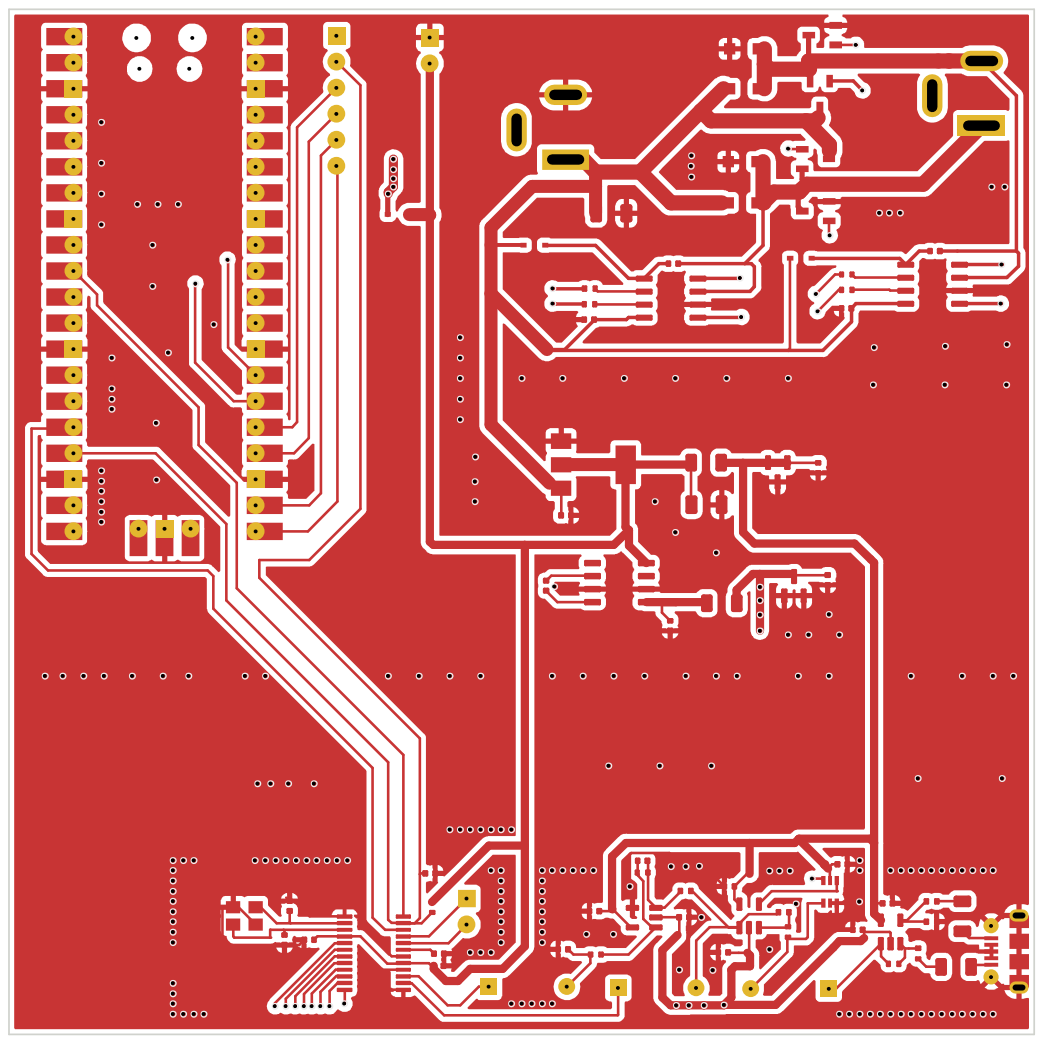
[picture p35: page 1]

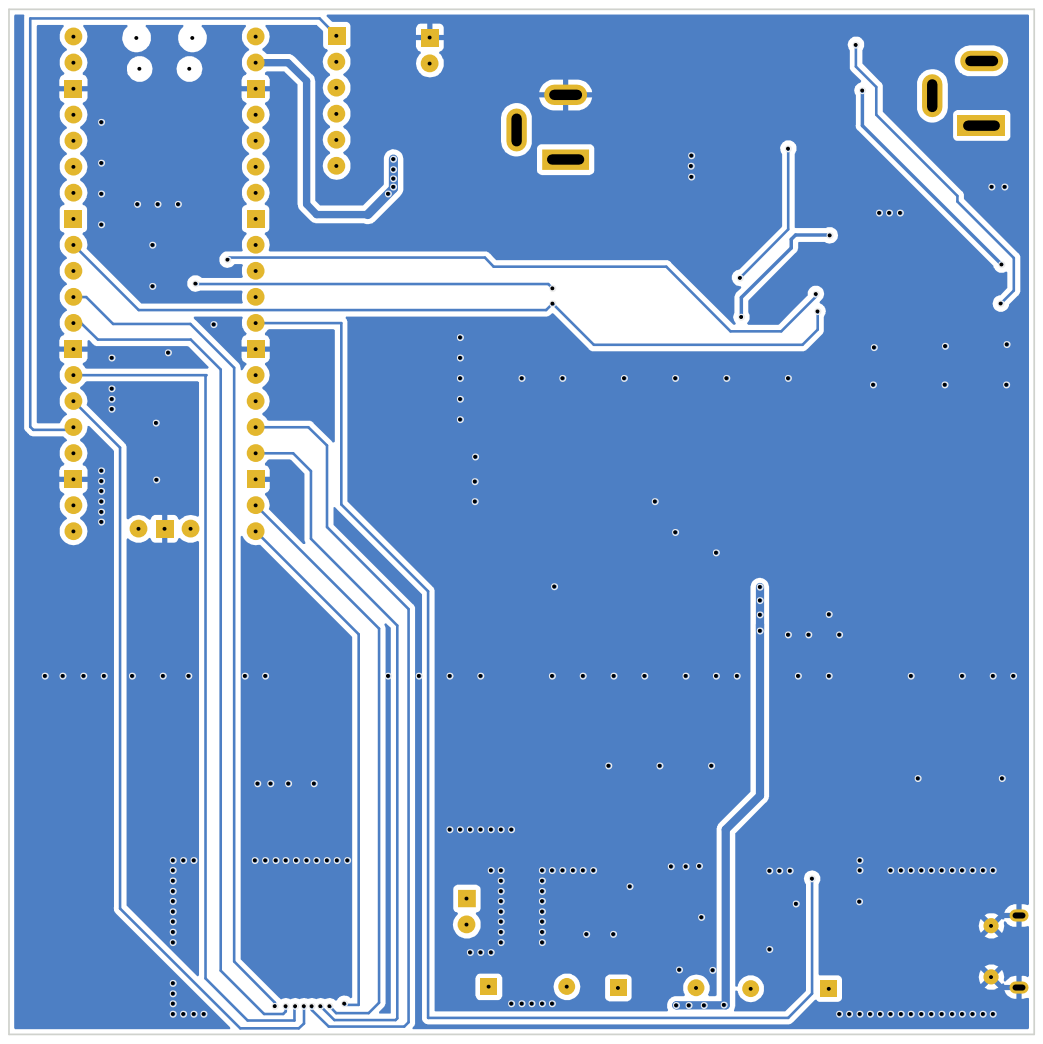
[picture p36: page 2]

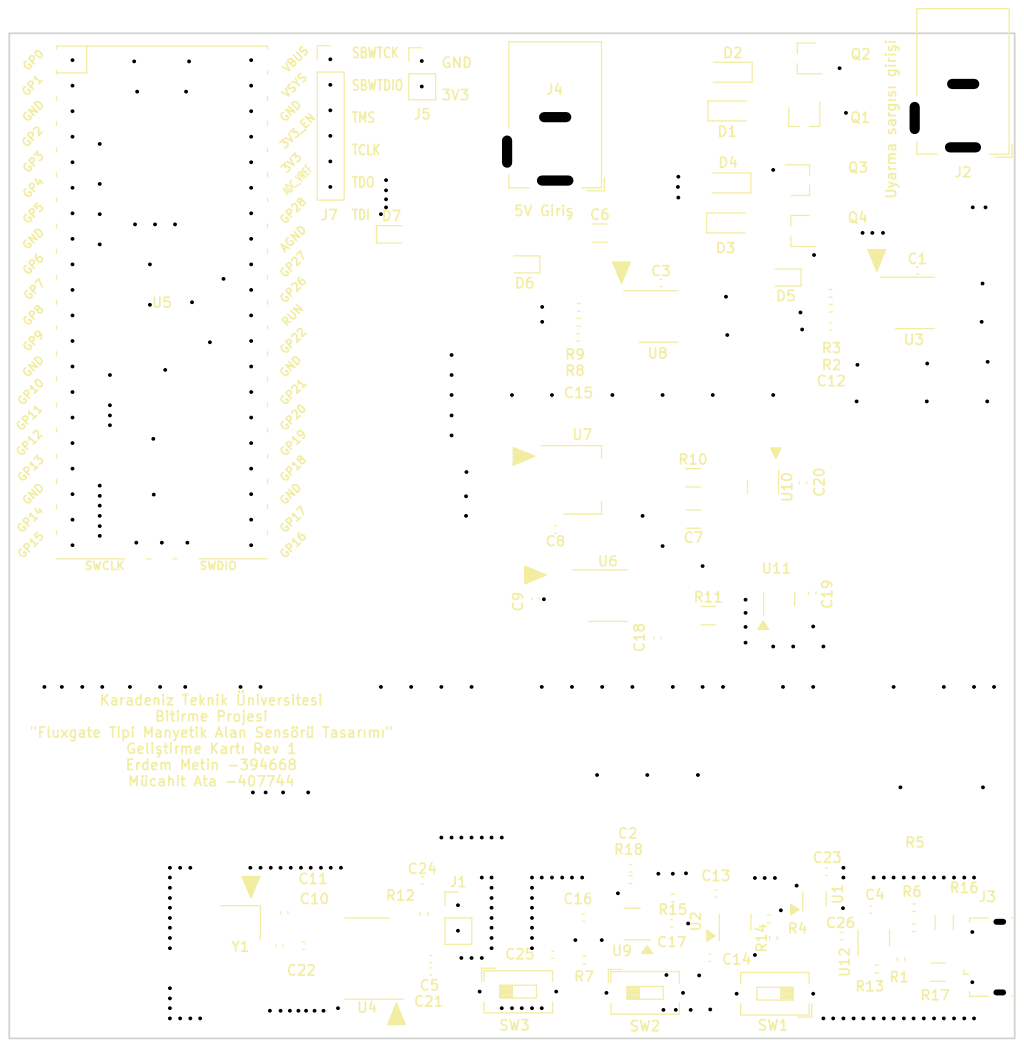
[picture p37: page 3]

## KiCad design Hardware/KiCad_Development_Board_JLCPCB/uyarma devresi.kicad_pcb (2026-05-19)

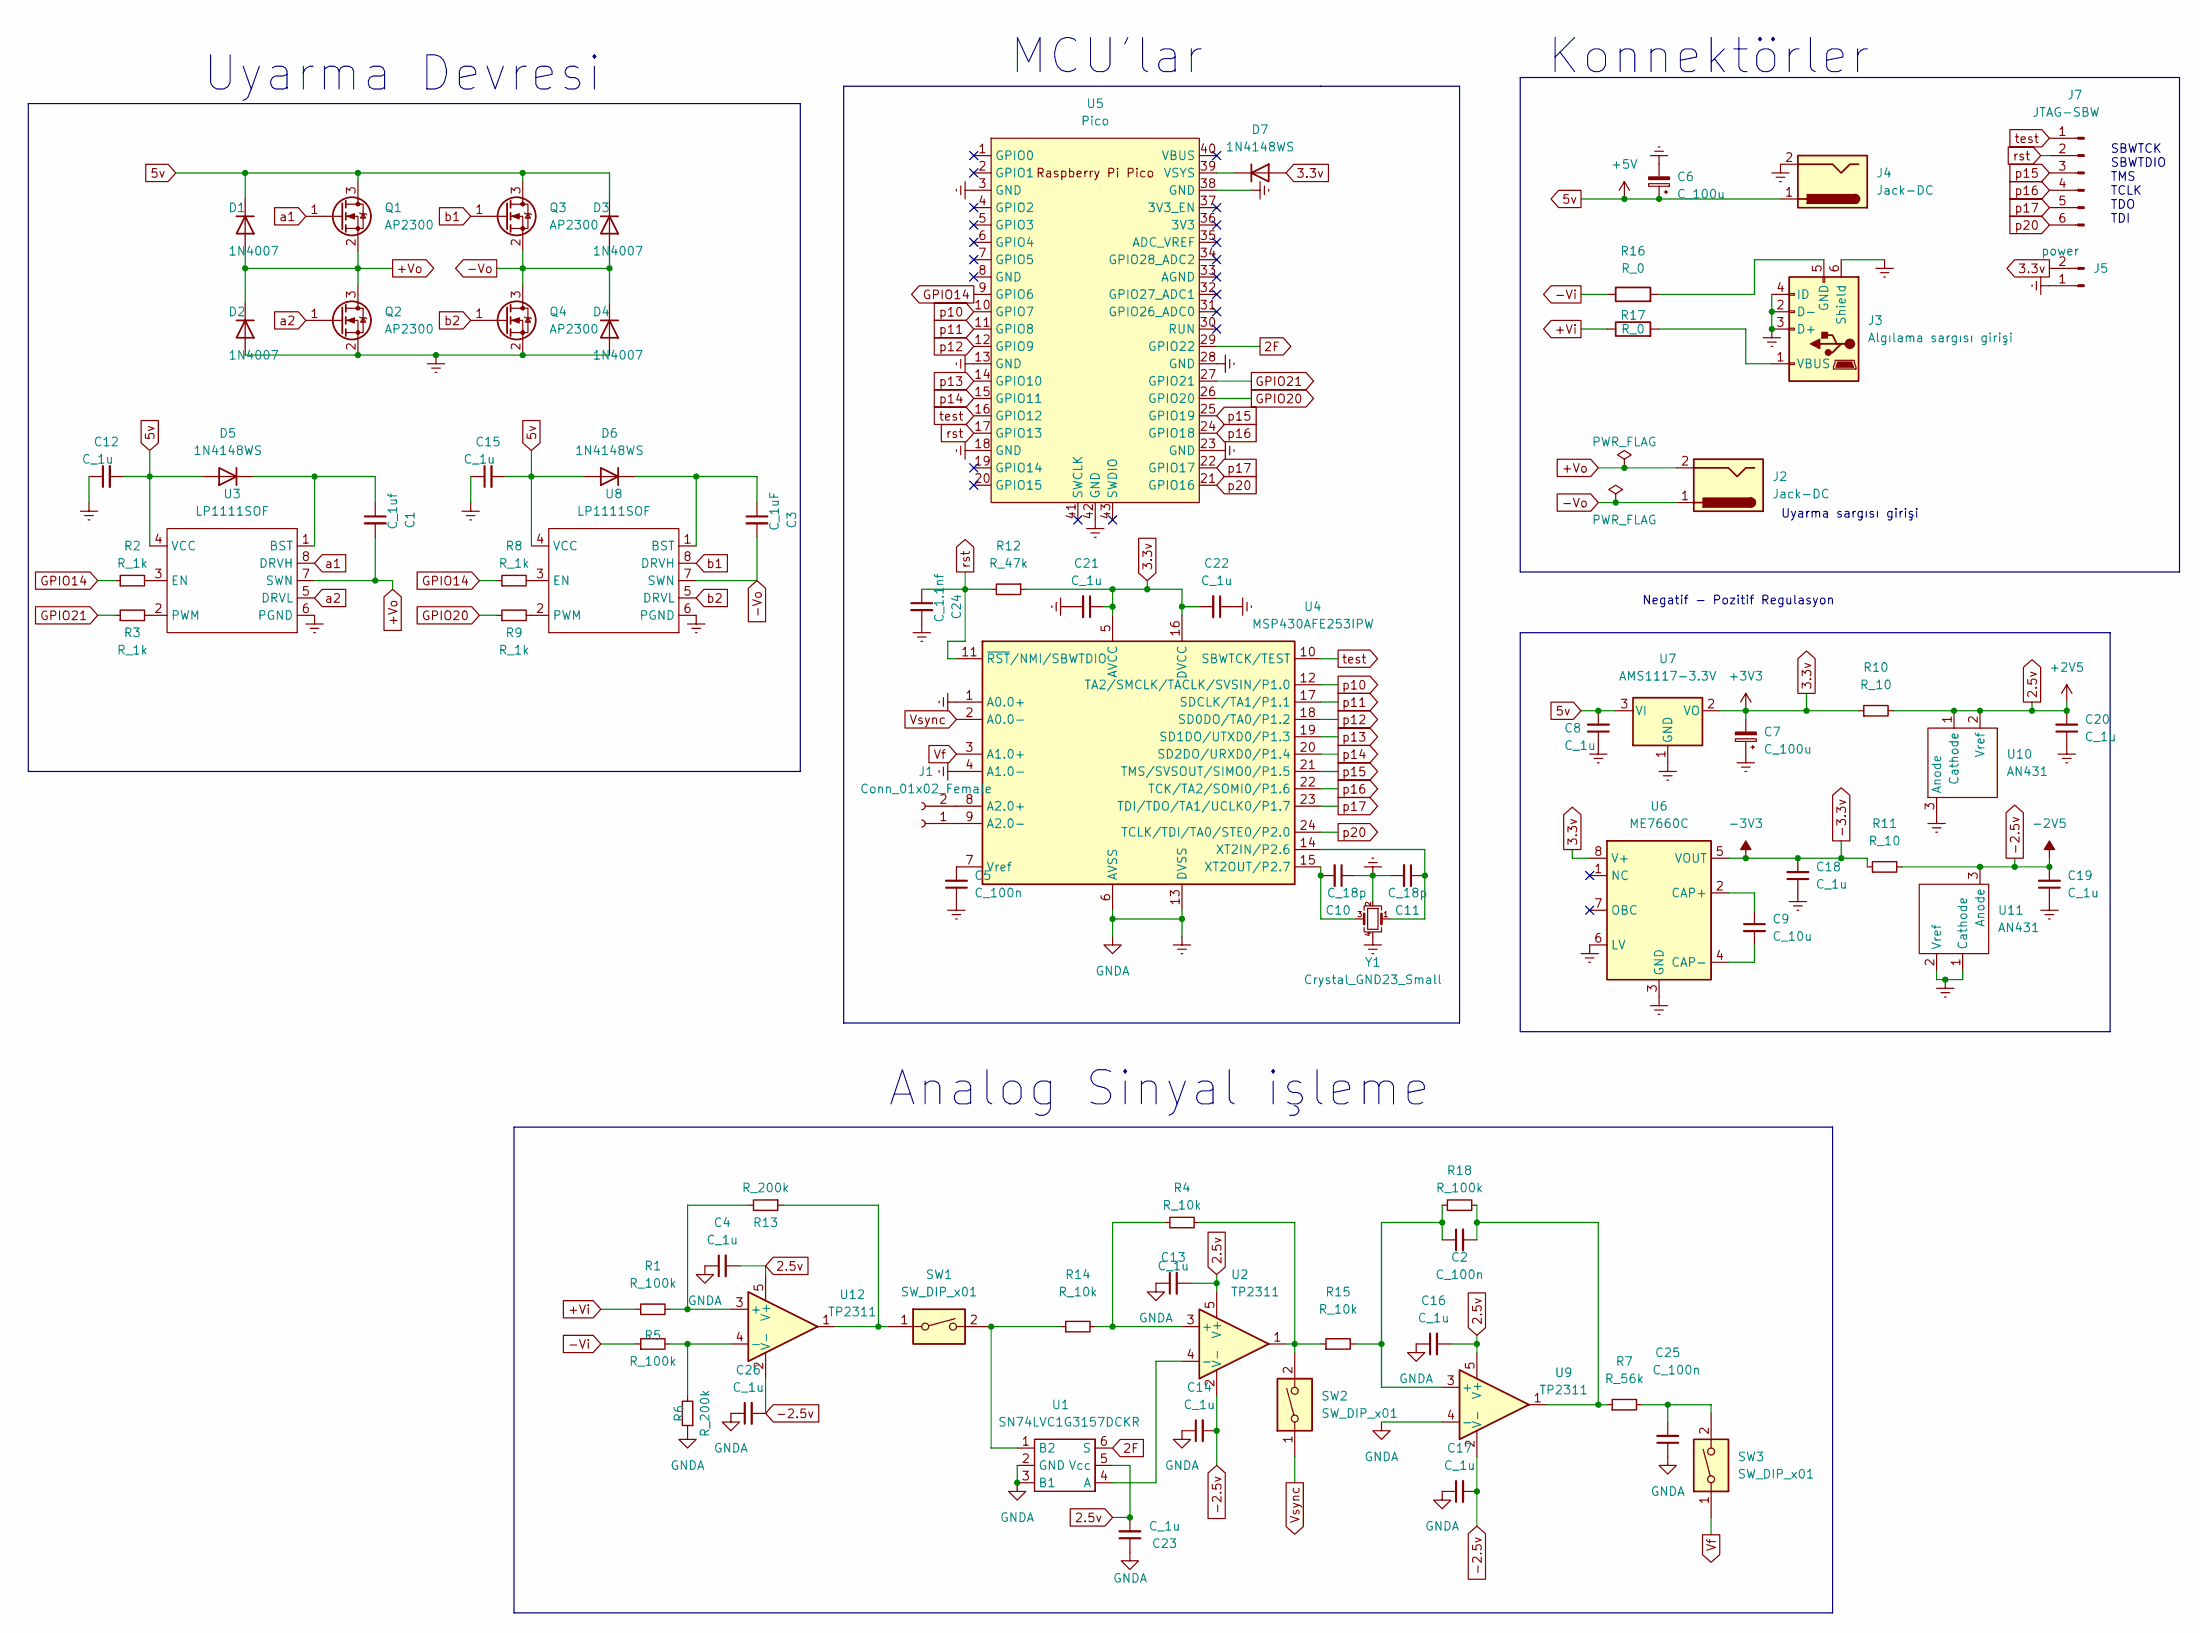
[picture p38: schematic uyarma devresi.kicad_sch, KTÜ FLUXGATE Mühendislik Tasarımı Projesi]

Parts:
C1: C_1uf; C_0402_1005Metric
C2, C5, C25: C_100n; C_0402_1005Metric
C3: C_1uF; C_0402_1005Metric
C4, C8, C12, C13, C14, C15, C16, C17, C18, C19, C20, C21, C22, C23, C26: C_1u; C_0402_1005Metric
C6, C7: C_100u; C_1206_3216Metric
C9: C_10u; C_0402_1005Metric
C10, C11: C_18p; C_0402_1005Metric
C24: C_1.1nf; C_0402_1005Metric
D1, D2, D3, D4: 1N4007; D_SOD-123F
D5, D6, D7: 1N4148WS; D_SOD-323
J1: Conn_01x02_Female; PinHeader_1x02_P2.54mm_Vertical
J2, J4: Jack-DC; BarrelJack_GCT_DCJ200-10-A_Horizontal
J3: Algılama sargısı girişi; USB_Micro-B_Molex-105017-0001
J5: power; PinHeader_1x02_P2.54mm_Vertical
J7: JTAG-SBW; PinHeader_1x06_P2.54mm_Vertical
Q1, Q2, Q3, Q4: AP2300; TSOT-23
R1, R5, R18: R_100k; R_0402_1005Metric
R2, R3, R8, R9: R_1k; R_0402_1005Metric
R4, R14, R15: R_10k; R_0402_1005Metric
R6, R13: R_200k; R_0402_1005Metric
R7: R_56k; R_0402_1005Metric
R10, R11: R_10; R_1206_3216Metric
R12: R_47k; R_0402_1005Metric
R16, R17: R_0; R_1206_3216Metric
SW1, SW2, SW3: SW_DIP_x01; SW_DIP_SPSTx01_Slide_6.7x4.1mm_W7.62mm_P2.54mm_LowProfile
U1: SN74LVC1G3157DCKR; Texas_R-PDSO-G6
U2, U9, U12: TP2311; SOT-23-5
U3, U8: LP1111SOF; SOP-8-1EP_4.57x4.57mm_P1.27mm_EP4.57x4.45mm
U4: MSP430AFE253IPW; TSSOP-24_4.4x7.8mm_P0.65mm
U5: Pico; RPi_Pico_SMD_TH
U6: ME7660C; SOP-8-1EP_4.57x4.57mm_P1.27mm_EP4.57x4.45mm
U7: AMS1117-3.3V; SOT-223-3_TabPin2
U10, U11: AN431; SOT-23
Y1: Crystal_GND23_Small; Crystal_SMD_3225-4Pin_3.2x2.5mm

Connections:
2.5v: C4.2, C13.2, C16.2, C20.2, C23.2, R10.2, U1.5 (Vcc), U2.5 (V+), U9.5 (V+), U10.1 (Cathode), U10.2 (Vref), U12.5 (V+)
2F: U1.6 (S), U5.29 (GPIO22)
3.3v: C7.2, C21.1, C22.2, D7.2 (A), J5.2, R10.1, R12.1, U4.5 (AVCC), U4.16 (DVCC), U6.8 (V+), U7.2 (VO)
5v: C6.1, C8.2, C12.2, C15.2, D1.1 (K), D3.1 (K), D5.2 (A), D6.2 (A), J4.1, Q1.3 (D), Q3.3 (D), U3.4 (VCC), U7.3 (VI), U8.4 (VCC)
+Vi: R1.1, R17.1
+Vo: C1.2, D1.2 (A), D2.1 (K), J2.2, Q1.2 (S), Q2.3 (D), U3.7 (SWN)
-2.5v: C14.2, C17.2, C19.2, C26.2, R11.2, U2.2 (V-), U9.2 (V-), U11.3 (Anode), U12.2 (V-)
-3.3v: C18.2, R11.1, U6.5 (VOUT)
-Vi: R5.1, R16.1
-Vo: C3.2, D3.2 (A), D4.1 (K), J2.1, Q3.2 (S), Q4.3 (D), U8.7 (SWN)
Earth: C4.1, C5.1, C6.2, C7.1, C8.1, C10.1, C11.2, C12.1, C13.1, C14.1, C15.1, C16.1, C17.1, C18.1, C19.1, C20.1, C21.2, C22.1, C23.1, C24.2, C25.1, C26.1, D2.2 (A), D4.2 (A), J3.2 (D-), J3.3 (D+), J3.4 (ID), J3.6 (Shield), J4.2, J5.1, Q2.2 (S), Q4.2 (S), R6.1, U1.2 (GND), U1.3 (B1), U3.6 (PGND), U4.1 (A0.0+), U4.4 (A1.0-), U4.6 (AVSS), U4.13 (DVSS), U5.3 (GND), U5.13 (GND), U5.18 (GND), U5.23 (GND), U5.28 (GND), U5.38 (GND), U5.42 (GND), U6.3 (GND), U6.6 (LV), U7.1 (GND), U8.6 (PGND), U9.4 (-), U10.3 (Anode), U11.1 (Cathode), U11.2 (Vref), Y1.2, Y1.4
GPIO14: R2.1, R8.1, U5.9 (GPIO6)
GPIO20: R9.1, U5.26 (GPIO20)
GPIO21: R3.1, U5.27 (GPIO21)
unnamed: C1.1, D5.1 (K), U3.1 (BST)
unnamed: C2.1, R15.2, R18.1, U9.3 (+)
unnamed: C2.2, R7.1, R18.2, U9.1
unnamed: C3.1, D6.1 (K), U8.1 (BST)
unnamed: C5.2, U4.7 (Vref)
unnamed: C9.1, U6.2 (CAP+)
unnamed: C9.2, U6.4 (CAP-)
unnamed: C10.2, U4.15 (XT2OUT/P2.7), Y1.3
unnamed: C11.1, U4.14 (XT2IN/P2.6), Y1.1
unnamed: C25.2, R7.2, SW3.2
unnamed: J1.1, U4.9 (A2.0-)
unnamed: J1.2, U4.8 (A2.0+)
unnamed: J3.1 (VBUS), R17.2
unnamed: J3.5 (GND), R16.2
unnamed: R1.2, R13.2, U12.3 (+)
unnamed: R2.2, U3.3 (EN)
unnamed: R3.2, U3.2 (PWM)
unnamed: R4.1, R14.2, U2.3 (+)
unnamed: R4.2, R15.1, SW2.2, U2.1
unnamed: R5.2, R6.2, U12.4 (-)
unnamed: R8.2, U8.3 (EN)
unnamed: R9.2, U8.2 (PWM)
unnamed: R13.1, SW1.1, U12.1
unnamed: R14.1, SW1.2, U1.1 (B2)
unnamed: U1.4 (A), U2.4 (-)
unnamed: D7.1 (K), U5.39 (VSYS)
Vf: SW3.1, U4.3 (A1.0+)
Vsync: SW2.1, U4.2 (A0.0-)
a1: Q1.1 (G), U3.8 (DRVH)
a2: Q2.1 (G), U3.5 (DRVL)
b1: Q3.1 (G), U8.8 (DRVH)
b2: Q4.1 (G), U8.5 (DRVL)
p10: U4.12 (TA2/SMCLK/TACLK/SVSIN/P1.0), U5.10 (GPIO7)
p11: U4.17 (SDCLK/TA1/P1.1), U5.11 (GPIO8)
p12: U4.18 (SD0DO/TA0/P1.2), U5.12 (GPIO9)
p13: U4.19 (SD1DO/UTXD0/P1.3), U5.14 (GPIO10)
p14: U4.20 (SD2DO/URXD0/P1.4), U5.15 (GPIO11)
p15: J7.3, U4.21 (TMS/SVSOUT/SIMO0/P1.5), U5.25 (GPIO19)
p16: J7.4, U4.22 (TCK/TA2/SOMI0/P1.6), U5.24 (GPIO18)
p17: J7.5, U4.23 (TDI/TDO/TA1/UCLK0/P1.7), U5.22 (GPIO17)
p20: J7.6, U4.24 (TCLK/TDI/TA0/STE0/P2.0), U5.21 (GPIO16)
rst: C24.1, J7.2, R12.2, U4.11 (~RST/NMI/SBWTDIO), U5.17 (GPIO13)
test: J7.1, U4.10 (SBWTCK/TEST), U5.16 (GPIO12)

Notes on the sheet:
Uyarma sargısı girişi
Analog Sinyal işleme
MCU'lar
SBWTCK SBWTDIO TMS TCLK TDO TDI
Negatif - Pozitif Regulasyon
Uyarma Devresi
Konnektörler

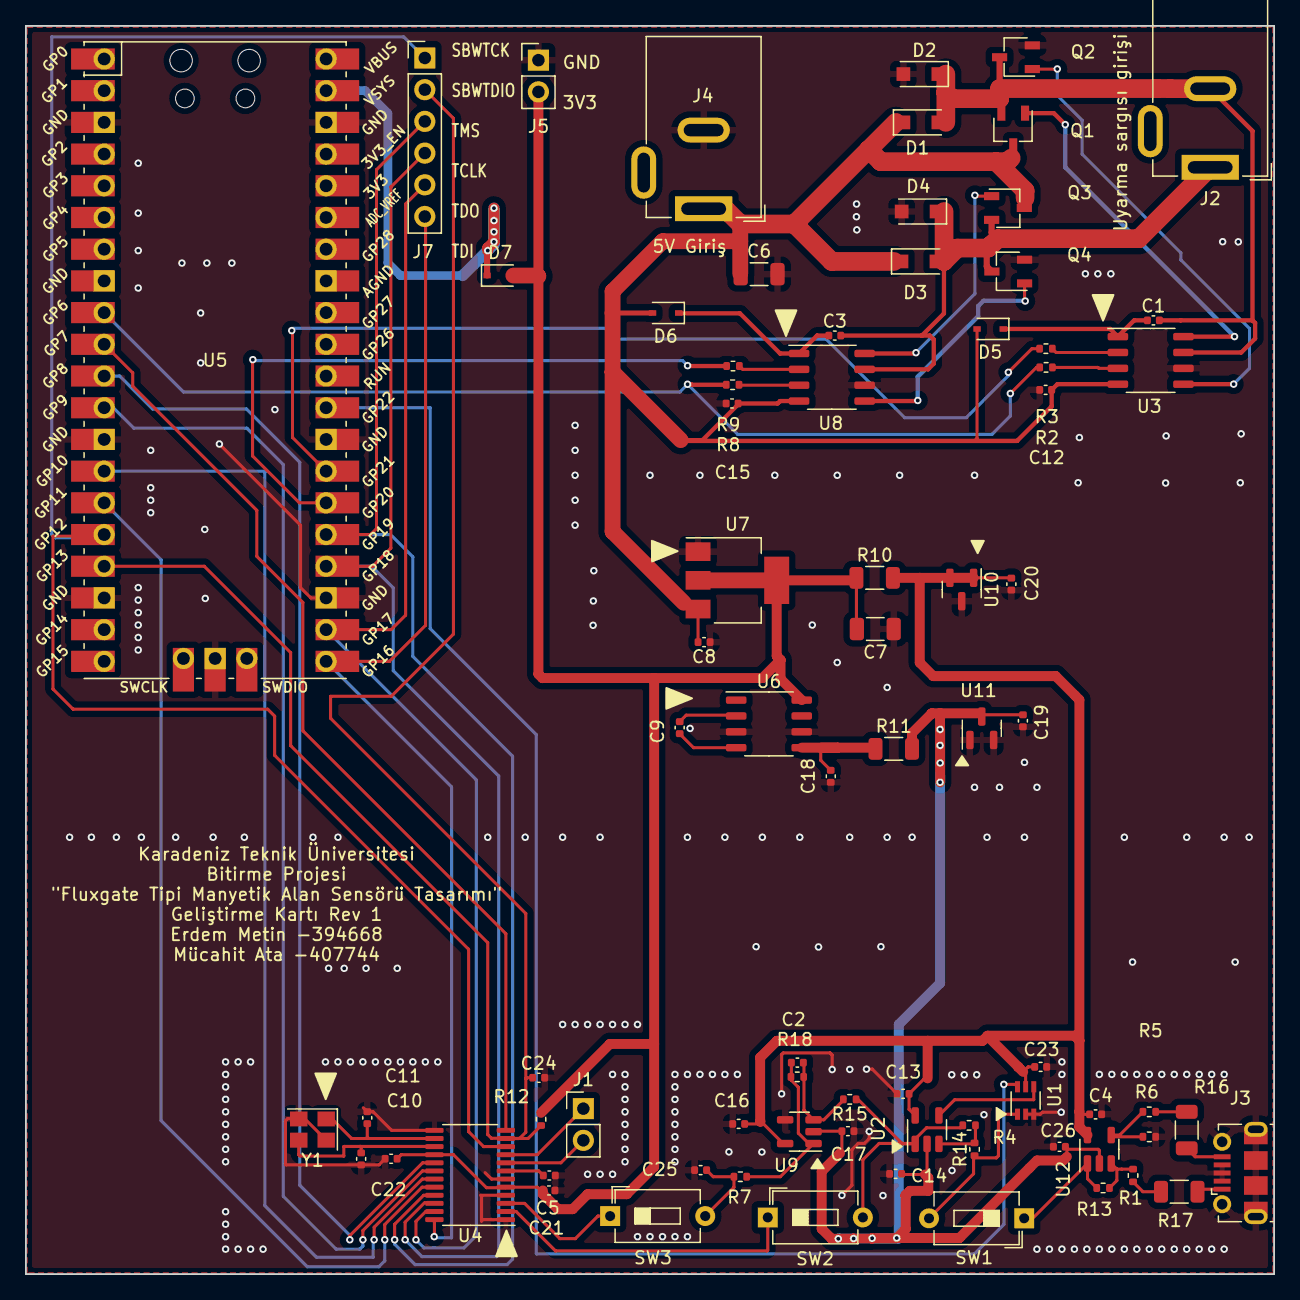
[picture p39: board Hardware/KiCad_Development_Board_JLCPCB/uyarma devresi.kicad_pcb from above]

Board: 2 copper layers, 100.0 x 100.0 mm, 77 parts (0 on the bottom side), 57 nets.

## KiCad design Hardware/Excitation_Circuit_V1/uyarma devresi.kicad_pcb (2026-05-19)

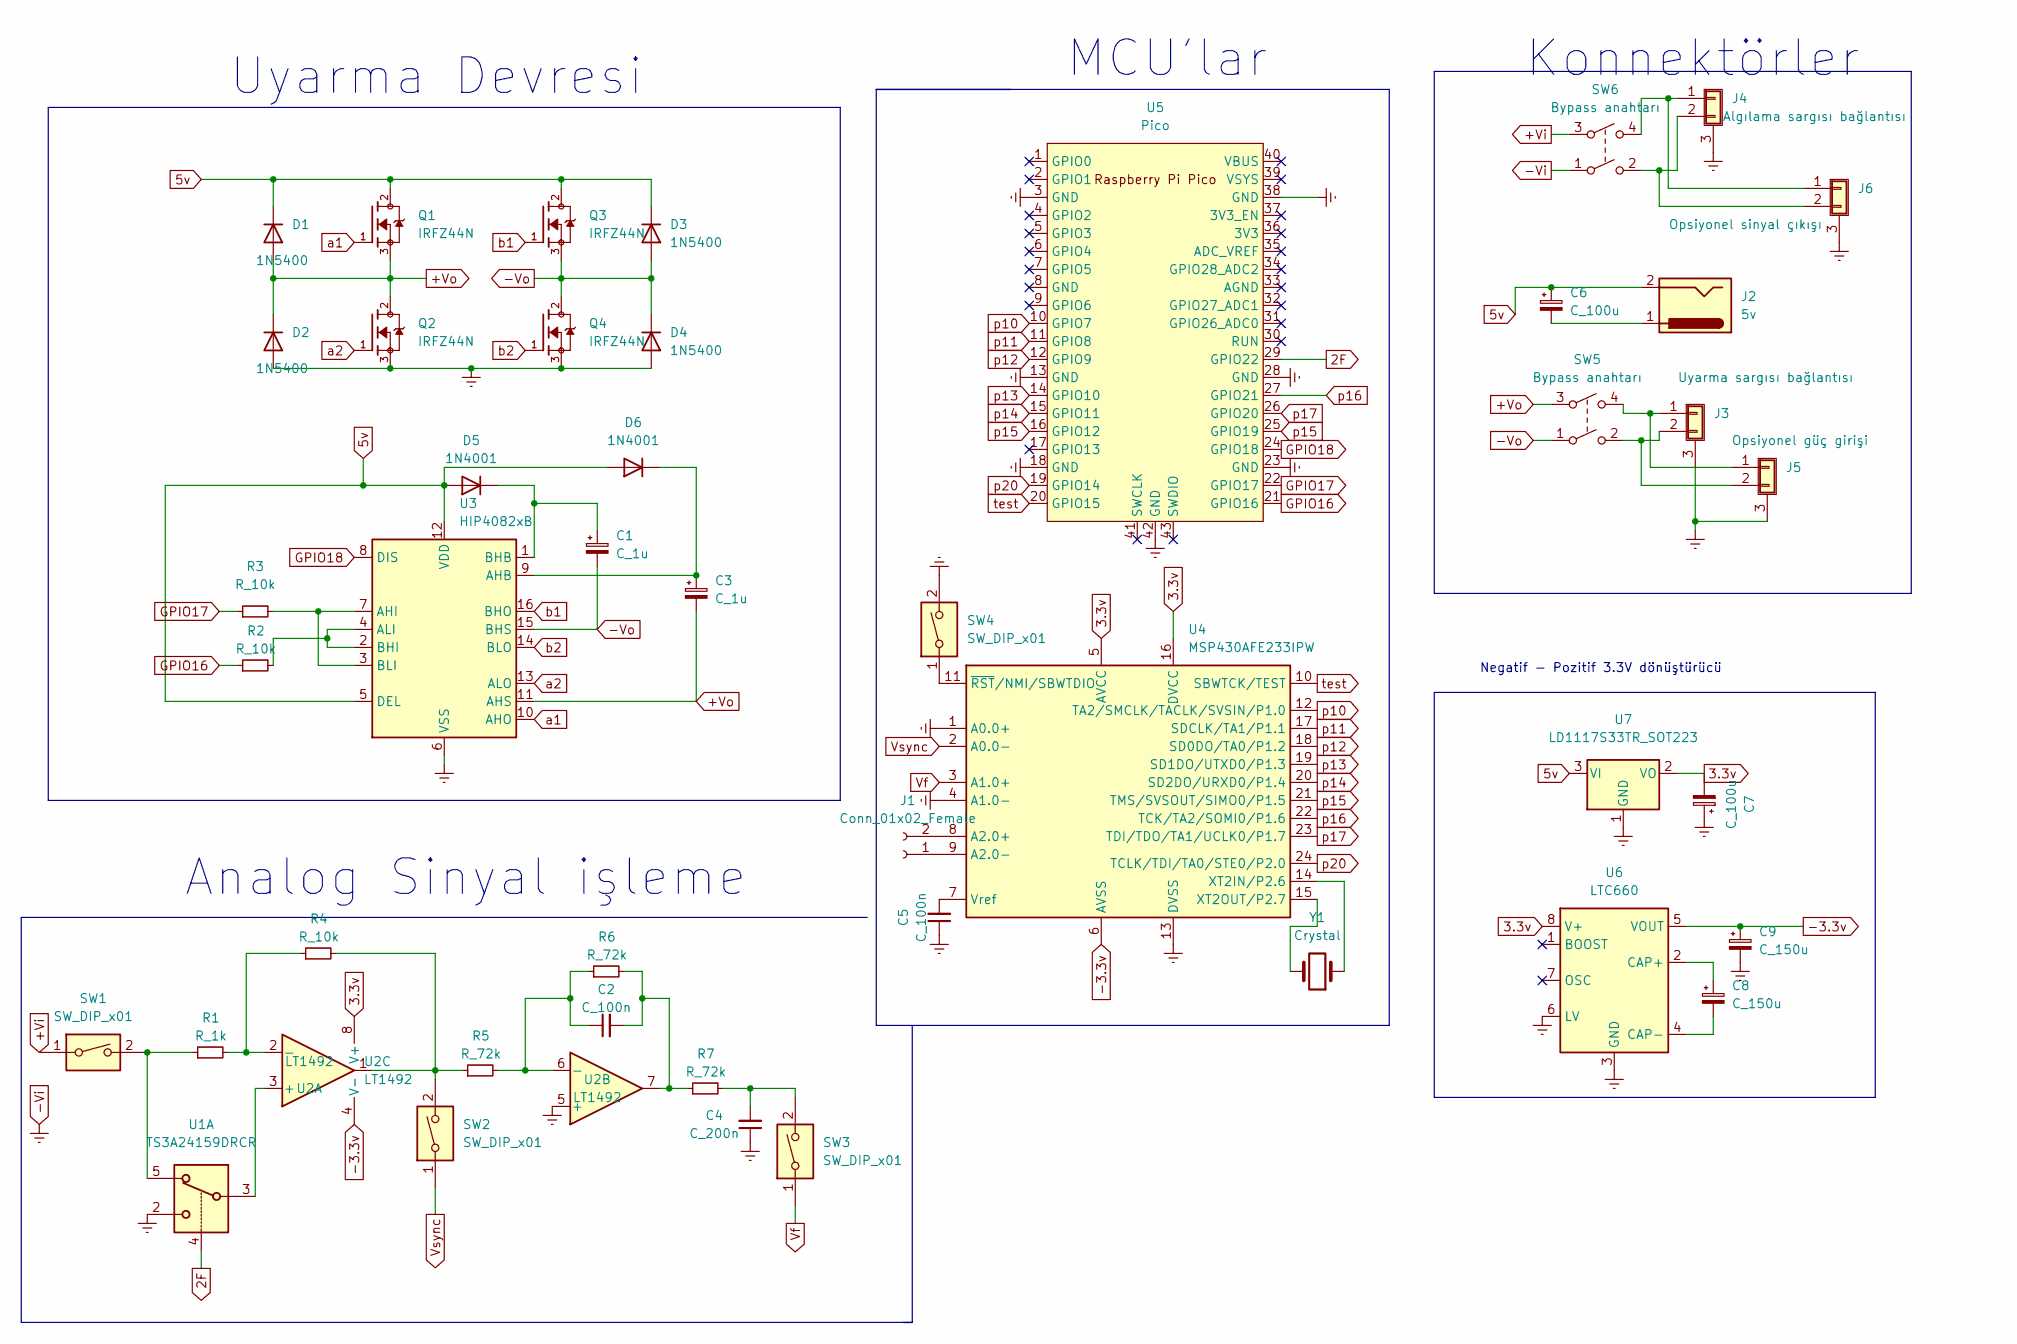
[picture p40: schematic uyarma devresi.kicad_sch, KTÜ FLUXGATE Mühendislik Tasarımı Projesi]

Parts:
C1, C3: C_1u; CP_Elec_3x5.3
C2: C_100n; CP_Elec_6.3x3.9
C4: C_200n; CP_Elec_6.3x3.9
C5: C_100n; CP_Elec_6.3x4.5
C6, C7: C_100u; CP_Elec_10x12.5
C8, C9: C_150u; CP_Elec_3x5.3
D1, D2, D3, D4: 1N5400; D_DO-201AD_P15.24mm_Horizontal
D5, D6: 1N4001; D_DO-41_SOD81_P10.16mm_Horizontal
J1: Conn_01x02_Female; PinHeader_1x02_P1.27mm_Vertical_SMD_Pin1Left
J2: 5v; BarrelJack_CUI_PJ-036AH-SMT_Horizontal
J3: Uyarma sargısı bağlantısı; BarrelJack_CLIFF_FC681465S_SMT_Horizontal
J4: Algılama sargısı bağlantısı; BarrelJack_CLIFF_FC681465S_SMT_Horizontal
J5: Opsiyonel güç girişi; BarrelJack_CLIFF_FC681465S_SMT_Horizontal
J6: Opsiyonel sinyal çıkışı; BarrelJack_CLIFF_FC681465S_SMT_Horizontal
Q1, Q2, Q3, Q4: IRFZ44N; TO254P1016X419X2286-3; PARTREV 09/21/10
R1: R_1k; R_Axial_DIN0204_L3.6mm_D1.6mm_P5.08mm_Horizontal
R2, R3, R4: R_10k; R_Axial_DIN0204_L3.6mm_D1.6mm_P5.08mm_Horizontal
R5, R6, R7: R_72k; R_Axial_DIN0204_L3.6mm_D1.6mm_P5.08mm_Horizontal
SW1, SW2, SW3, SW4: SW_DIP_x01; SW_DIP_SPSTx01_Slide_6.7x4.1mm_W8.61mm_P2.54mm_LowProfile
SW5, SW6: Bypass anahtarı; SW_Push_2P1T_Toggle_CK_PVA1xxH3xxxxxxV2
U1: TS3A24159DRCR; Texas_S-PVSON-N10
U2: LT1492; SO-16_3.9x9.9mm_P1.27mm
U3: HIP4082xB; SOIC-16_3.9x9.9mm_P1.27mm
U4: MSP430AFE233IPW; TSSOP-24_4.4x7.8mm_P0.65mm
U5: Pico; RPi_Pico_SMD_TH
U6: LTC660; SO-8_3.9x4.9mm_P1.27mm
U7: LD1117S33TR_SOT223; SOT-223-3_TabPin2
Y1: Crystal; R_01005_0402Metric

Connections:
2F: U1.4, U5.29 (GPIO22)
3.3v: C7.2, U2.8 (V+), U4.5 (AVCC), U4.16 (DVCC), U6.8 (V+), U7.2 (VO)
5v: C6.1, D1.1 (K), D3.1 (K), D5.2 (A), D6.2 (A), J2.2, Q1.2, Q3.2, U3.5 (DEL), U3.12 (VDD), U7.3 (VI)
+Vi: SW1.1, SW6.3
+Vo: C3.2, D1.2 (A), D2.1 (K), Q1.3, Q2.2, SW5.3, U3.11 (AHS)
-3.3v: C9.1, U2.4 (V-), U4.6 (AVSS), U6.5 (VOUT)
-Vi: C4.1, C5.1, C7.1, C9.2, D2.2 (A), D4.2 (A), J3.3 (Shield), J4.3 (Shield), J5.3 (Shield), J6.3 (Shield), Q2.3, Q4.3, SW4.2, SW6.1, U1.2, U2.5 (+), U3.6 (VSS), U4.1 (A0.0+), U4.4 (A1.0-), U4.13 (DVSS), U5.3 (GND), U5.13 (GND), U5.18 (GND), U5.23 (GND), U5.28 (GND), U5.38 (GND), U5.42 (GND), U6.3 (GND), U6.6 (LV), U7.1 (GND)
-Vo: C1.2, D3.2 (A), D4.1 (K), Q3.3, Q4.2, SW5.1, U3.15 (BHS)
GPIO16: R2.1, U5.21 (GPIO16)
GPIO17: R3.1, U5.22 (GPIO17)
GPIO18: U3.8 (DIS), U5.24 (GPIO18)
unnamed: C1.1, D5.1 (K), U3.1 (BHB)
unnamed: C2.1, R5.2, R6.1, U2.6 (-)
unnamed: C2.2, R6.2, R7.1, U2.7
unnamed: C3.1, D6.1 (K), U3.9 (AHB)
unnamed: C4.2, R7.2, SW3.2
unnamed: C5.2, U4.7 (Vref)
unnamed: C6.2, J2.1
unnamed: C8.1, U6.2 (CAP+)
unnamed: C8.2, U6.4 (CAP-)
unnamed: J1.1, U4.9 (A2.0-)
unnamed: J1.2, U4.8 (A2.0+)
unnamed: J3.1, J5.1, SW5.4
unnamed: J3.2, J5.2, SW5.2
unnamed: J4.1, J6.1, SW6.4
unnamed: J4.2, J6.2, SW6.2
unnamed: R1.1, SW1.2, U1.5
unnamed: R1.2, R4.1, U2.2 (-)
unnamed: R3.2, U3.3 (BLI), U3.7 (AHI)
unnamed: R4.2, R5.1, SW2.2, U2.1
unnamed: SW4.1, U4.11 (~RST/NMI/SBWTDIO)
unnamed: U1.3, U2.3 (+)
unnamed: R2.2, U3.2 (BHI), U3.4 (ALI)
unnamed: U4.14 (XT2IN/P2.6), Y1.1
unnamed: U4.15 (XT2OUT/P2.7), Y1.2
Vf: SW3.1, U4.3 (A1.0+)
Vsync: SW2.1, U4.2 (A0.0-)
a1: Q1.1, U3.10 (AHO)
a2: Q2.1, U3.13 (ALO)
b1: Q3.1, U3.16 (BHO)
b2: Q4.1, U3.14 (BLO)
p10: U4.12 (TA2/SMCLK/TACLK/SVSIN/P1.0), U5.10 (GPIO7)
p11: U4.17 (SDCLK/TA1/P1.1), U5.11 (GPIO8)
p12: U4.18 (SD0DO/TA0/P1.2), U5.12 (GPIO9)
p13: U4.19 (SD1DO/UTXD0/P1.3), U5.14 (GPIO10)
p14: U4.20 (SD2DO/URXD0/P1.4), U5.15 (GPIO11)
p15: U4.21 (TMS/SVSOUT/SIMO0/P1.5), U5.16 (GPIO12), U5.25 (GPIO19)
p16: U4.22 (TCK/TA2/SOMI0/P1.6), U5.27 (GPIO21)
p17: U4.23 (TDI/TDO/TA1/UCLK0/P1.7), U5.26 (GPIO20)
p20: U4.24 (TCLK/TDI/TA0/STE0/P2.0), U5.19 (GPIO14)
test: U4.10 (SBWTCK/TEST), U5.20 (GPIO15)

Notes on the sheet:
Analog Sinyal işleme
MCU'lar
Negatif - Pozitif 3.3V dönüştürücü
Uyarma Devresi
Konnektörler

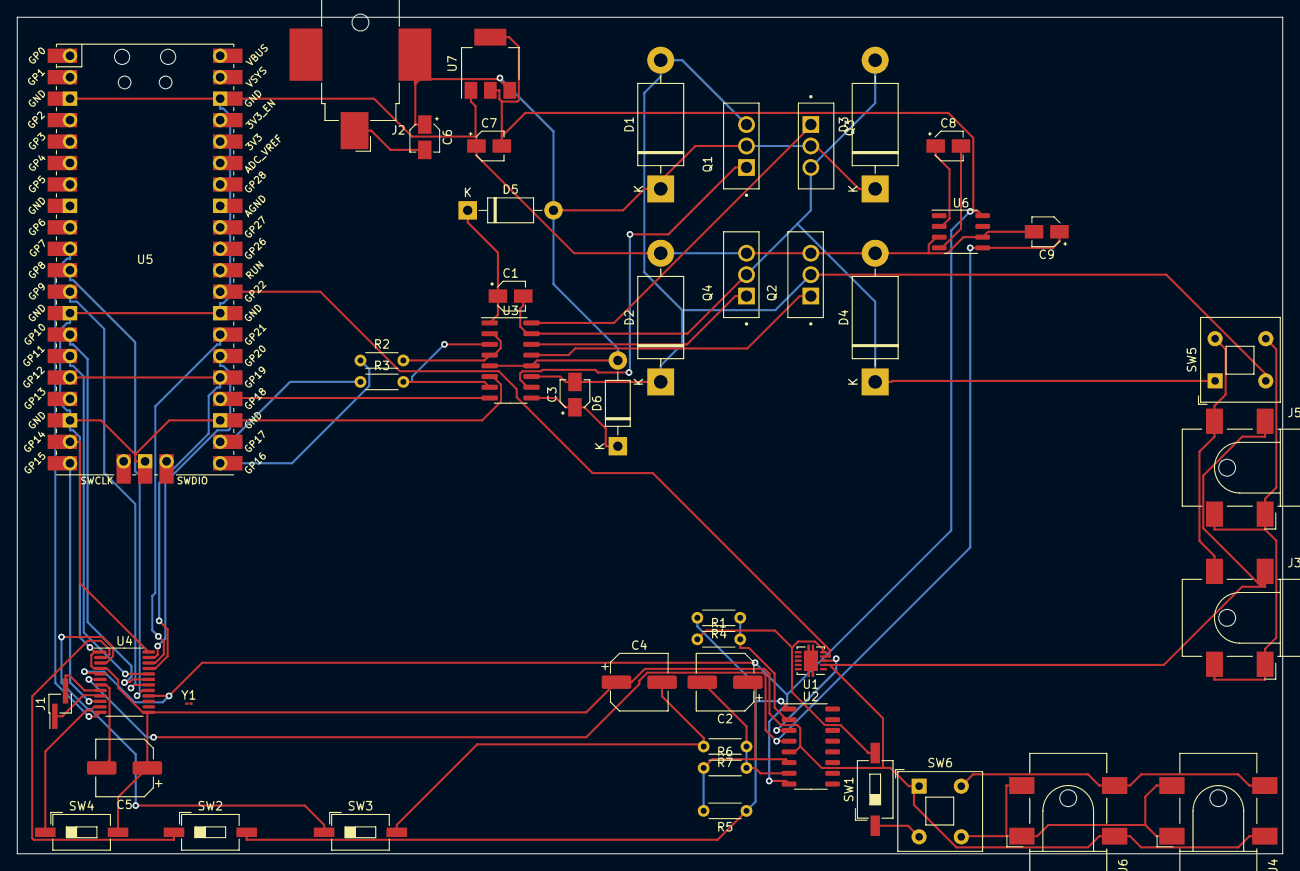
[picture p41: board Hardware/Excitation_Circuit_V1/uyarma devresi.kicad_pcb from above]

Board: 2 copper layers, 149.9 x 99.1 mm, 46 parts (0 on the bottom side), 51 nets.

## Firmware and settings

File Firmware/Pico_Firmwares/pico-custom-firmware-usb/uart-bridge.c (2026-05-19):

#include <boards/pico_w.h>
#include <hardware/irq.h>
#include <hardware/structs/sio.h>
#include <hardware/uart.h>
#include <pico/multicore.h>
#include <pico/stdlib.h>
#include <string.h>
#include <tusb.h>
#include "hardware/pio.h"
#include "rx.pio.h"
#include "hardware/pwm.h"
//udp
#include "pico/cyw43_arch.h"
#include "lwip/pbuf.h"
#include "lwip/udp.h"

#define  RECEIVER_IP  "192.168.0.105"
#define  RECEIVER_PORT 6001
struct udp_pcb  * upcb;
struct udp_pcb  * spcb;

#if !defined(MIN)
#define MIN(a, b) ((a > b) ? b : a)
#endif /* MIN */


#define BUFFER_SIZE 2560

#define DEF_BIT_RATE 1500000
#define DEF_STOP_BITS 1
#define DEF_PARITY 0
#define DEF_DATA_BITS 8


typedef struct {
	uart_inst_t *const inst;
	uint irq;
	void *irq_fn;
	uint8_t tx_pin;
	uint8_t rx_pin;
} uart_id_t;

typedef struct {
	cdc_line_coding_t usb_lc;
	cdc_line_coding_t uart_lc;
	mutex_t lc_mtx;
	uint8_t uart_buffer[BUFFER_SIZE];
	uint32_t uart_pos;
	mutex_t uart_mtx;
	uint8_t usb_buffer[BUFFER_SIZE];
	uint32_t usb_pos;
	mutex_t usb_mtx;
} uart_data_t;

void uart0_irq_fn(void);
void uart1_irq_fn(void);

const uart_id_t UART_ID[CFG_TUD_CDC] = {
	{
		.inst = uart0,
		.irq = UART0_IRQ,
		.irq_fn = &uart0_irq_fn,
		.tx_pin = 0,
		.rx_pin = 1,
	}, {
		.inst = uart1,
		.irq = UART1_IRQ,
		.irq_fn = &uart1_irq_fn,
		.tx_pin = 4,
		.rx_pin = 5,
	}
};

uart_data_t UART_DATA[CFG_TUD_CDC];

static inline uint databits_usb2uart(uint8_t data_bits)
{
	switch (data_bits) {
		case 5:
			return 5;
		case 6:
			return 6;
		case 7:
			return 7;
		default:
			return 8;
	}
}

static inline uart_parity_t parity_usb2uart(uint8_t usb_parity)
{
	switch (usb_parity) {
		case 1:
			return UART_PARITY_ODD;
		case 2:
			return UART_PARITY_EVEN;
		default:
			return UART_PARITY_NONE;
	}
}

static inline uint stopbits_usb2uart(uint8_t stop_bits)
{
	switch (stop_bits) {
		case 2:
			return 2;
		default:
			return 1;
	}
}

void update_uart_cfg(uint8_t itf)
{
	const uart_id_t *ui = &UART_ID[itf];
	uart_data_t *ud = &UART_DATA[itf];

	mutex_enter_blocking(&ud->lc_mtx);

	if (ud->usb_lc.bit_rate != ud->uart_lc.bit_rate) {
		uart_set_baudrate(ui->inst, ud->usb_lc.bit_rate);
		ud->uart_lc.bit_rate = ud->usb_lc.bit_rate;
	}

	if ((ud->usb_lc.stop_bits != ud->uart_lc.stop_bits) ||
	    (ud->usb_lc.parity != ud->uart_lc.parity) ||
	    (ud->usb_lc.data_bits != ud->uart_lc.data_bits)) {
		uart_set_format(ui->inst,
				databits_usb2uart(ud->usb_lc.data_bits),
				stopbits_usb2uart(ud->usb_lc.stop_bits),
				parity_usb2uart(ud->usb_lc.parity));
		ud->uart_lc.data_bits = ud->usb_lc.data_bits;
		ud->uart_lc.parity = ud->usb_lc.parity;
		ud->uart_lc.stop_bits = ud->usb_lc.stop_bits;
	}

	mutex_exit(&ud->lc_mtx);
}

void usb_read_bytes(uint8_t itf)
{
	uart_data_t *ud = &UART_DATA[itf];
	uint32_t len = tud_cdc_n_available(itf);

	if (len &&
	    mutex_try_enter(&ud->usb_mtx, NULL)) {
		len = MIN(len, BUFFER_SIZE - ud->usb_pos);
		if (len) {
			uint32_t count;

			count = tud_cdc_n_read(itf, &ud->usb_buffer[ud->usb_pos], len);
			ud->usb_pos += count;
		}

		mutex_exit(&ud->usb_mtx);
	}
}

void usb_write_bytes(uint8_t itf)
{
	uart_data_t *ud = &UART_DATA[itf];

	if (ud->uart_pos &&
	    mutex_try_enter(&ud->uart_mtx, NULL)) {
		uint32_t count;

		count = tud_cdc_n_write(itf, ud->uart_buffer, ud->uart_pos);
		if (count < ud->uart_pos)
			memmove(ud->uart_buffer, &ud->uart_buffer[count],
			       ud->uart_pos - count);
		ud->uart_pos -= count;

		mutex_exit(&ud->uart_mtx);

		if (count)
			tud_cdc_n_write_flush(itf);
	}
}

void usb_cdc_process(uint8_t itf)
{
	uart_data_t *ud = &UART_DATA[itf];

	mutex_enter_blocking(&ud->lc_mtx);
	tud_cdc_n_get_line_coding(itf, &ud->usb_lc);
	mutex_exit(&ud->lc_mtx);

	usb_read_bytes(itf);
	usb_write_bytes(itf);
}

void core1_entry(void)
{

	tusb_init();

	while (1) {
		int itf;
		int con = 0;

		tud_task();

		for (itf = 0; itf < CFG_TUD_CDC; itf++) {
			if (tud_cdc_n_connected(itf)) {
				con = 1;
				usb_cdc_process(itf);
			}

		}
	}
}

static inline void uart_read_bytes(uint8_t itf)
{
	uart_data_t *ud = &UART_DATA[itf];
	const uart_id_t *ui = &UART_ID[itf];

	if (uart_is_readable(ui->inst)) {
		mutex_enter_blocking(&ud->uart_mtx);

		while (uart_is_readable(ui->inst) &&
		       (ud->uart_pos < BUFFER_SIZE)) {
			ud->uart_buffer[ud->uart_pos] = uart_getc(ui->inst);
			ud->uart_pos++;
		}

		mutex_exit(&ud->uart_mtx);
	}
}

void uart0_irq_fn(void)
{
	uart_read_bytes(0);
}

void uart1_irq_fn(void)
{
	uart_read_bytes(1);
}

void uart_write_bytes(uint8_t itf)
{
	uart_data_t *ud = &UART_DATA[itf];

	if (ud->usb_pos &&
	    mutex_try_enter(&ud->usb_mtx, NULL)) {
		const uart_id_t *ui = &UART_ID[itf];
		uint32_t count = 0;

		while (uart_is_writable(ui->inst) &&
		       count < ud->usb_pos) {
			uart_putc_raw(ui->inst, ud->usb_buffer[count]);
			count++;
		}

		if (count < ud->usb_pos)
			memmove(ud->usb_buffer, &ud->usb_buffer[count],
			       ud->usb_pos - count);
		ud->usb_pos -= count;

		mutex_exit(&ud->usb_mtx);
	}
}

void init_uart_data(uint8_t itf)
{
	const uart_id_t *ui = &UART_ID[itf];
	uart_data_t *ud = &UART_DATA[itf];

	/* Pinmux */
	gpio_set_function(ui->tx_pin, GPIO_FUNC_UART);
	gpio_set_function(ui->rx_pin, GPIO_FUNC_UART);

	/* USB CDC LC */
	ud->usb_lc.bit_rate = DEF_BIT_RATE;
	ud->usb_lc.data_bits = DEF_DATA_BITS;
	ud->usb_lc.parity = DEF_PARITY;
	ud->usb_lc.stop_bits = DEF_STOP_BITS;

	/* UART LC */
	ud->uart_lc.bit_rate = DEF_BIT_RATE;
	ud->uart_lc.data_bits = DEF_DATA_BITS;
	ud->uart_lc.parity = DEF_PARITY;
	ud->uart_lc.stop_bits = DEF_STOP_BITS;

	/* Buffer */
	ud->uart_pos = 0;
	ud->usb_pos = 0;

	/* Mutex */
	mutex_init(&ud->lc_mtx);
	mutex_init(&ud->uart_mtx);
	mutex_init(&ud->usb_mtx);

	/* UART start */
	uart_init(ui->inst, ud->usb_lc.bit_rate);
	uart_set_hw_flow(ui->inst, false, false);
	uart_set_format(ui->inst, databits_usb2uart(ud->usb_lc.data_bits),
			stopbits_usb2uart(ud->usb_lc.stop_bits),
			parity_usb2uart(ud->usb_lc.parity));
	uart_set_fifo_enabled(ui->inst, false);

	/* UART RX Interrupt */
	irq_set_exclusive_handler(ui->irq, ui->irq_fn);
	irq_set_enabled(ui->irq, true);
	uart_set_irq_enables(ui->inst, true, false);
}

void uyar(void){
	// Uyarma sargısı H bridge çıkışları
	const uint enA = 6;
	const uint in1 = 20;
	const uint in2 = 21;
	const int sw = 26; //pin 22 ile pin26 arasına jumper atıldı
	const uint p11=11;
	const uint  frekans= 200; // her bir değer 1us
	
	gpio_init(22);
	gpio_set_dir(22, GPIO_IN);

	gpio_set_function(enA, GPIO_FUNC_PWM);
	gpio_set_function(in1, GPIO_FUNC_PWM);
	gpio_set_function(in2, GPIO_FUNC_PWM);
	gpio_set_function(sw, GPIO_FUNC_PWM);
	gpio_set_function(p11, GPIO_FUNC_PWM);


	uint inputs = pwm_gpio_to_slice_num(in1);
	uint enable = pwm_gpio_to_slice_num(enA);
	int pin26 = pwm_gpio_to_slice_num(sw);
	int pin11 = pwm_gpio_to_slice_num(p11);

	// 250 mhz/250 =1mhz clock, 
	pwm_set_clkdiv(inputs,250);
    pwm_set_wrap(inputs, frekans);

	pwm_set_clkdiv(enable,250);
    pwm_set_wrap(enable, frekans);

	pwm_set_clkdiv(pin26,250);
    pwm_set_wrap(pin26, frekans);
	
	pwm_set_clkdiv(pin11,250);
    pwm_set_wrap(pin11, frekans);

	//phase correct
	pwm_set_phase_correct(inputs, true);
	pwm_set_phase_correct(enable, false);
	pwm_set_phase_correct(pin26, false);
	pwm_set_phase_correct(pin11, false);

	pwm_set_output_polarity(inputs,false, true);
	pwm_set_output_polarity(enable,false, false);
	pwm_set_output_polarity(pin26,false, false);
	pwm_set_output_polarity(pin11,false, false);
    //PWM counter ayarı


	pwm_set_chan_level(inputs, PWM_CHAN_A, frekans/(frekans/40.0));
    pwm_set_chan_level(inputs, PWM_CHAN_B, frekans-frekans/(frekans/40.0));

	pwm_set_counter(enable, frekans/(frekans/40.0));
	pwm_set_chan_level(enable, PWM_CHAN_A, frekans/(frekans/80.0));
	pwm_set_chan_level(pin26, PWM_CHAN_A, frekans/(frekans/120.0)); //demodülator uyarma sinyalinden 40us ileri

	pwm_set_counter(pin11, frekans/(frekans/82.0));
	pwm_set_chan_level(pin11, PWM_CHAN_B, frekans/(frekans/80.0));

	// Set the PWM running
    pwm_set_enabled(inputs, true);
	pwm_set_enabled(enable, true);
	pwm_set_enabled(pin26, true);
	pwm_set_enabled(pin11, true);

}

void SendUDP(char * IP , int port, void * data, int data_size)
{
      ip_addr_t   destAddr;
      ip4addr_aton(IP,&destAddr);
      struct pbuf * p = pbuf_alloc(PBUF_TRANSPORT,data_size,PBUF_RAM);
      memcpy(p->payload,data,data_size);
      cyw43_arch_lwip_begin();
      udp_sendto(upcb,p,&destAddr,port);
      cyw43_arch_lwip_end();
      pbuf_free(p);
}

int main(void)
{
	int itf;
	set_sys_clock_khz(250000, false);
	unsigned int n=0;
	uint8_t recv[1024];
	usbd_serial_init();

	for (itf = 0; itf < CFG_TUD_CDC; itf++)
		init_uart_data(itf);

	gpio_init(13);
	gpio_set_dir(13, GPIO_OUT);

	gpio_put(13,1);

	// SM kurulumu- pin10'a ek rx kanalı
    PIO pio = pio0;
    uint sm = 0;
    uint offset = pio_add_program(pio, &uart_rx_program);
    uart_rx_program_init(pio, sm, offset, 10, 1500000);

	//core1 usb işini yapacak
	multicore_launch_core1(core1_entry);

	//udp kurulumu
   	cyw43_arch_init();
	cyw43_arch_enable_sta_mode(); //sta=client mode oluyor
	cyw43_arch_wifi_connect_timeout_ms("ÜÇERLER(2.4)","333ER333", CYW43_AUTH_WPA2_AES_PSK, 30000);
	upcb = udp_new();
	spcb = udp_new();
	err_t err = udp_bind(spcb,IP_ADDR_ANY,6001);

	uyar();
	
	while (1) {        		
		for (itf = 0; itf < CFG_TUD_CDC; itf++) {
			//usb üzerinden uart ayarları değişirse
			update_uart_cfg(itf);
			
			//çift yönlü uartta usb bufferından aldığını yazması için
			uart_write_bytes(itf);
		}

		//SM ile pin 10'a ek RX pinin eklenip uart1 bufferına yazılması

			while (!pio_sm_is_rx_fifo_empty(pio0, sm) && n < 1024) {
			recv[n]= uart_rx_program_getc(pio, sm);
			n++;
			}
			if(n>=1023){
			SendUDP(RECEIVER_IP,RECEIVER_PORT, recv, 1024);
			n=0;
			cyw43_arch_poll();

			}

	
	}

	return 0;
}

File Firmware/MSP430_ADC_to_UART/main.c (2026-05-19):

#include "msp430.h"
int i=0;
unsigned long int results[3]={0,0,0};

void senduart(void)
{
  while (!(IFG1 & UTXIFG0));                // USART0 TX buffer ready?
  TXBUF0 = 0xA5;
  while (!(IFG1 & UTXIFG0));                // USART0 TX buffer ready?
  TXBUF0 = results[1]&0xff;
  while (!(IFG1 & UTXIFG0));                // USART0 TX buffer ready?
  TXBUF0 = (results[1]>>8)&0xff;
  while (!(IFG1 & UTXIFG0));                // USART0 TX buffer ready?
  TXBUF0 = (results[1]>>16)&0xff;
  while (!(IFG1 & UTXIFG0));                // USART0 TX buffer ready?
  TXBUF0 = (results[1]>>24)&0xff;
  
  while (!(IFG1 & UTXIFG0));                // USART0 TX buffer ready?
  TXBUF0 = results[2]&0xff;
  while (!(IFG1 & UTXIFG0));                // USART0 TX buffer ready?
  TXBUF0 = (results[2]>>8)&0xff;
  while (!(IFG1 & UTXIFG0));                // USART0 TX buffer ready?
  TXBUF0 = (results[2]>>16)&0xff;
  while (!(IFG1 & UTXIFG0));                // USART0 TX buffer ready?
  TXBUF0 = (results[2]>>24)&0xff;
  while (!(IFG1 & UTXIFG0)); 
  TXBUF0 = 0xA5;
}

void main(void)
{
  volatile unsigned int i;
  
  WDTCTL = WDTPW + WDTHOLD;                 // Stop WDT
  P1SEL |= BIT3;                       // P1.3, = USART0 TXD
  //DCO ile 12 mhz
  //  do
  //  {
  //      IFG1 &= ~OFIFG;                       // Clear OSCFault flag
  //      for (i = 0x47FF; i > 0; i--);         // Time for flag to set
  //  }
  //  while ((IFG1 & OFIFG));                   // OSCFault flag still set?
  //      /* Check if 12MHz Calibration is present */
  //        if (CALBC1_12MHZ != 0xFF)
  //        {
  //            DCOCTL = 0; // Select lowest DCOx and MODx
  //            BCSCTL1 = CALBC1_12MHZ; // Set range
  //            DCOCTL = CALDCO_12MHZ; // Set DCO step + modulation
  //        }
  
  /* 12mHz kristal */
  P2SEL |= (BIT6 | BIT7); // XIN, XOUT
  P2SEL2 &= ~(BIT6|BIT7); // XIN, XOUT
  
  BCSCTL1 ^= (XT2OFF); // xt2on
  BCSCTL3 |= (XT2S_2); // 2-16mhz kristal
  do
  {
    IFG1 &= ~OFIFG;                       // Clear OSCFault flag
    for (i = 0x47FF; i > 0; i--);         // Time for flag to set
  }
  while ((IFG1 & OFIFG));                   // OSCFault flag still set?
  {
    BCSCTL2 |= (SELS+SELM1); // MCLK=SMCLk=xt2=12MHZ
  }
  
  
  ME1 |= UTXE0;                     // Enable USART0 TXD/RXD
  U0CTL |= CHAR;                            // 8-bit character
  U0TCTL |= SSEL1;                          // UCLK= SMCLK
  U0BR0 = 8;                               // 1MHz 115200
  U0BR1 = 0x00;                             // 1MHz 115200
  U0MCTL = 0x00;                            // 1MHz 115200 modulation
  U0CTL &= ~SWRST;                          // Initialize USART state machine
  // IE1 |= URXIE0;                            // Enable USART0 RX interrupt
  //P1SEL2 |= BIT0;                           // Set SMCLK at P1.0
  
  SD24CTL   = SD24REFON+SD24VMIDON+SD24SSEL0+SD24DIV0;          // 1.2V ref, SMCLK 12mhz/12=1mhz
  SD24CCTL0 = SD24SNGL+SD24OSR_128+SD24IE;
  SD24CCTL1 = SD24OSR_1024+SD24IE;
  
  //SD24INCTL0 |= SD24INTDLY0;  SD24OSR_512+ +SD24DIV1+SD24XDIV0+
  SD24INCTL1 |= SD24GAIN_32;
  SD24INCTL0 |= SD24GAIN_2;
  for (i = 0; i < 0x3600; i++);             // Delay for 1.2V ref startup
  
    
  P1IE |= BIT4;                             // P1.4 interrupt enabled
  P1IES |= BIT4;                            // P1.4 Hi/lo edge
  P1IFG &= ~BIT4;                           // P1.4 IFG cleared
  SD24CCTL1 |= SD24SC;

    __bis_SR_register(GIE);       // Enter w/ interrupt
    SD24PRE0 = 0;
 
}

#if defined(__TI_COMPILER_VERSION__) || defined(__IAR_SYSTEMS_ICC__)
#pragma vector=SD24_VECTOR
__interrupt void SD24AISR(void)
#elif defined(__GNUC__)
void __attribute__ ((interrupt(SD24_VECTOR))) SD24AISR (void)
#else
#error Compiler not supported!
#endif
{
  switch (__even_in_range(SD24IV,SD24IV_SD24MEM2)) {
  case SD24IV_NONE: break;
  case SD24IV_SD24OVIFG: break;
  case SD24IV_SD24MEM0:
    senduart();
    results[1] = SD24MEM0;                   // Save CH0 results (clears IFG)
    SD24CCTL0 |= SD24LSBACC;
    results[1] = ((SD24MEM0)+ ((results[1] >>11) <<16));
    SD24CCTL0 ^= SD24LSBACC;  
  case SD24IV_SD24MEM1:
    results[2] = SD24MEM1;                   // Save CH2 results (clears IFG)
    SD24CCTL1 |= SD24LSBACC;
    results[2] = ((SD24MEM1)+ ((results[2] >>2) <<16));
    SD24CCTL1 ^= SD24LSBACC;
    
  case SD24IV_SD24MEM2: break;
  default: break;
  }
  
}

#pragma vector=PORT1_VECTOR
__interrupt void Port_1(void)
{
  SD24CCTL0 |= SD24SC;
  P1IFG &= ~BIT4;                           // P1.4 IFG cleared
  }

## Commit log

2026-05-19 Initial commit: Reorganized Fluxgate Sensor project into professional open-source structure
    [BOM-uyarma devresi.csv, bom.csv, designators.csv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]
2026-05-19 Enriched README files with system schematic, PCB layout renders, physical board photo, and toroid core winding photos. Relocated udp_plot_pyqt.py into Software/Python_GUI_Demo
